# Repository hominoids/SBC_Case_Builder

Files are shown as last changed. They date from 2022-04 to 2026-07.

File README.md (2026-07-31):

# SBC Case Builder

## Introduction

This project is about autonomous SBC case creation. It utilizes the SBC Model Framework project to automatically generate cases based on the data for any of the current devices contained within the framework. This allows legacy, current and future SBC to have multiple cases available on day one of their inclusion in the framework. There are multiple base case designs available (shell, panel, stacked, tray, tray-sides, round, hex, snap, fitted, folded-paper and standard motherboard adapters) and each allows for customization within the design.

All case openings are created automatically based on SBC data and the dimensions of any case design can be expanded in any axis allowing for the creation of larger cases. If you reposition the SBC in a case, you will see I/O openings created or removed appropriately based on their proximity to the case geometry. These cases might be useful for prototypes or other in house uses to quickly and easily create standard, specialized and custom SBC cases thru different case designs, customization and accessories.

License: GPLv3.

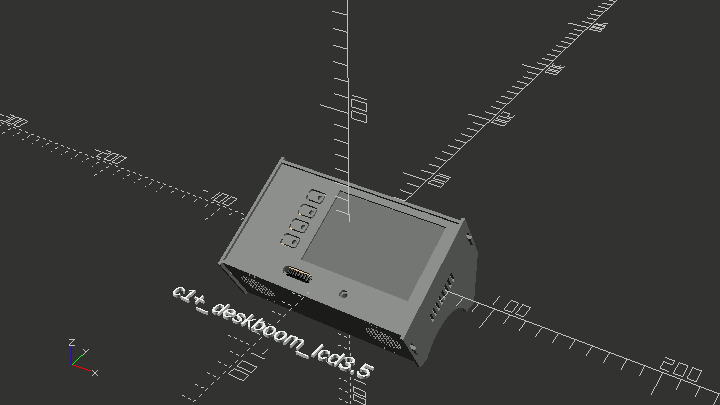
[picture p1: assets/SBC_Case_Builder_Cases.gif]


### Install
```
  git clone https://github.com/hominoids/SBC_Case_Builder.git
  cd SBC_Case_Builder
  git submodule init
  git submodule update

```
NOTE: The submodule *SBC Model Framework* needs to be updated anytime SBC Case Builder is updated.

## SBC Case Builder Features:
-  Autonomous Multi-SBC, Multi-Case Parametric Generation
-  Autonomous SBC and Accessory Model I/O Openings
-  Autonomous Case Standoffs with Variable Height
-  Extended Standoff SBC collision detection
-  Accessory Customization Framework
-  Accessory Multi-Associative Parametric Positioning
   - Absolute Location
   - Case Associations
   - SBC Associations
   - SBC_X,Y - Case_Z Association
-  Graphical User Interface
-  SBC Meta Data Access
-  Individual Standoff Parameter Control
-  Dynamic Heatsink Fan Size, Vent and Mask Openings 
-  Top and Bottom Case Cover Patterns
-  Parametric Bottom Access Panel

### Base Case Designs:
- Shell - complete
- Panel - complete
- Stacked - complete
- Tray - complete
- Tray-Sides - complete
- Tray-Vu5 - complete
- Tray-Vu7 - complete
- Round - complete
- Hex - complete
- Snap - complete
- Fitted - complete
- Paper, Folded - complete
- Standard MB SBC Adapters & io plates - completed
	+ SSI-EEB, SSI-CEB, ATX, Micro-ATX, DTX, Flex-ATX, Mini-DTX, EBX, Mini-ITX, Mini-ITX Thin, Mini-STX, Mini-STX Thin
- Standard MB Cases - complete
	+ SSI-EEB, SSI-CEB, ATX, Micro-ATX, DTX, Flex-ATX, Mini-DTX, EBX, Mini-ITX, Mini-ITX Thin, Mini-STX, Mini-STX Thin, Nano-ITX, NUC, Pico-ITX
- NAS, panel_nas - complete
- Rack, 1U and 2U - complete
- Stacked Levels
- Sliding
- Cylinder
- Free Form
- Sheet Metal, Folded
- CNC Cases

All case data is stored in the json file sbc_case_builder.json with the accessory data stored in a separate file structure in sbc_case_builder_accessories.cfg.  An accessory group name for a given case is stored as part of the case data in the json file.  This allows for the reuse or sharing of an accessory set by different cases and can be used to manage groups of accessories.

Variable height automated SBC standoffs, which can be individually adjusted, are also implemented to integrate add-on PCB, hats, heatsinks or other accessories that share SBC standoffs for mounting.

## Graphical User Interface
The GUI has multiple tabs that control what model and case is displayed, how it is presented, its adjustments, options and associated accessories. There are separate tabs in the GUI for *Folded Case Adjustments*, *Standard Motherboard Case Adjustments* and *3D Case Adjustments*.  The first two have unique settings that only apply to the respective case designs.  3D case adjustments affect all others case designs and some entries can also affect Folded and Standard Motherboard cases as well. There are three groups of two tabs each associated with SBC, Extended Case and Multi-PCB standoffs.



### View Tab
The View Tab allows the selection of various viewing modes and the selection of the device model for which a case is being generated.  The *view* pickbox allows the respective case to be displayed as a 3D model, platter for 3D printing and as an individual case part, which can be selected using the *individual part* pickbox.  The *section part* checkbox sections the selected part for dxf or other 2D export. The *sbc model* pickbox selects the device (SBC, MCU, Motherboard, etc).  The *sbc off* and *sbc information* are self explanatory.  The *sbc highlight* shows the subtractive openings that are being automatically created by SBC Model Framework while the *accessory highlight* shows the subtractive openings being generated by entries in the file sbc_case_builder_accessories.cfg.  The later is useful when trying to visually place a subtractive accessory.

### Folded Case Adjustments Tab
This tab exclusively deals with folded cases.  At this time the bend allowance equations are not complete and limits its use to paper and other thin materials with a low bend radius.  Once folded metal cases are implemented the bend allowance equations will be complete and allow for any bendable material of any given bend radius.  With that said, these adjustments are used for the paper_full-top and paper_split-top case designs and the *material thickness* and *bend Allowance* adjustments still need to be set appropriately for proper use.  The *bottom clearance* adjustment allows additional bottom height adjustment for those wishing to use user provided standoffs on the bottom of the device for better stability.  The *flat blank section* checkbox generates a flat blank based on the aforementioned settings.  Once it has been generated the model must be rendered(F6) to produce a 2D blank that can then be exported as a DXF or SVG file for printing or fed to a CNC cutter.

### Standard Motherboard Case Adjustments Tab
Both standard motherboard adapters and cases can be generated with SBC Case Builder and this tab controls the specific settings. Since it is not possible to know the motherboard thickness it is set to 2mm and the *standard motherboard thickness* setting is used to add or subtract thickness for an accurate representation of the user provided PCB.  The *rear io shield* setting enables the generation of an io shield for adapters and standard motherboard cases.  The setting *adapter sbc rotation* rotates the sbc for adapters.  Most of the adjustments in the *3D Case Adjustments* tab also work for motherboard adapters which allows for the SBC or other device to be repositioned on the adapter while providing the full use of the accessory subsystem. Any accessory entries in the sbc_case_builder_accessories.cfg file should reference the bottom face. The *bottom cover pattern* in the *Fan and Vent Openings* tab and the *SBC Bottom Standoff* tabs also apply to motherboard adapters.  There are predefined example cases and adapters available in the GUI for further reference.

### Rack Mount Case Adjustments Tab
Both 1U and 2U, 10" and 19", rack cases are configured in this tab.  The first entry *rack width* selects if 10" or 19" rack cases are being created.  The *rack size* sets whether 1U or 2U.  There is a 2mm wall in front of every removable bay. *removable bay height* allows the tray height to be reduced to form an opening which allows for tray removal and venting when installed with other rack cases above.  The remaining tab is divided into six groups of settings each representing a virtual bay.  Each bay group specifies the SBC thru the pickbox *Rack Bay1* respectively. With *rack bay1 xyz loc* and *rack bay1 rotation determining the position and z-axis rotation.  The type of bay is set in the *rack bay1 face* pickbox followed by two checkboxes for the internal dividing wall, rear fan and a bay conduit selection pickbox. 

### 3D Case Adjustments Tab
The *3D Case Adjustments* tab makes up the bulk of the possible case adjustments for 3D printed cases.  Most of the entries in this tab are self explanatory.  The *pcb loc* adjustments allow the selected device model to be moved in the case design, the *case offset* adjustments increase the selected case design dimensions. The *wallthick*, *floorthick* and *sidethick* adjust their respective areas.  Do note that the *floorthick* adjustment also determines the ceiling thickness for all case designs and the *sidethick* only affects the tray_sides, tray_vu5, tray_vu7 case designs. The *gap* entry is the distance between the device PCB and the sidewall of the case design.  The *tol* adjustment, located at the bottom of the tab, is a  tolerance fitment adjustment for the snap, fitted, round and hex case design tops.  Adjust accordingly if the tops are too tight or loose.

### Fan and Vent Openings Tab
This tab handles the fan and cooling options for case designs.  The *top cover pattern*, *bottom cover pattern* and *front cover pattern* contain several options for the creation of vent patterns that cover the complete panel, including a solid covering.  The *cooling* pickbox selects fan and vent openings exclusively for the heatsink associated with the device in SBC Model Framework.
```
disable - turns off the heatsink model and mask
off - heatsink model is off, mask is on and default will be used
default - heatsink model is on and uses the mask setting in ./SBC_Model_Framework/sbc_models.cfg
none - heatsink model is on and mask is off.
fan and vent pattern selections - open, fan_open, fan_1, fan_2, fan_hex, vent, vent_hex_5mm, vent_hex_8mm
custom - uses the file ./SBC_Model_Framework/customfan.dxf
```
The *fan size* allows the selection of different fan size masks over the default size selected by 0.  The rear fan entries are for the *panel_nas* case design and allow for the same types of fan adjustments as the heatsink.  There is also the choice of one or two rear fans as well as additional adjustments for the position and spacing of them.

### Bottom Access Panel Tab
This tab allows the creation of a bottom access panel and its entries are self explanatory.  Additional access panels can be implemented using the accessory subsystem.

### Options and Accessories
The entrys in this tab allow for the enablement and selection of different options and accessories. It includes case indents, GPIO, and UART openings based on their type identifier in SBC_Model_Framework.  It also contains hard drive options for the panel_nas case.

#### GPIO Selections
```
disable - turns off the GPIO model and mask
off - GPIO model is off, mask is on and default will be used
default - GPIO model is on and uses the mask setting stored in ./SBC_Model_Framework/sbc_models.cfg
none - GPIO model is on and mask is off
mask opening selections - open, block, knockout, vent
```

#### UART Selections
```
default - UART model is on and uses the mask setting stored in ./SBC_Model_Framework/sbc_models.cfg
none - UART model is on and mask is off
mask opening selections - open, knockout
```

The *indent* checkbox enables indents for a select group of components defined in SBC Model Framework.  The currently support components are - video-hmdi_a, video-hdmi_micro, video-hdmi_mini, power-pwr5.5_7.5x11.5, power-pwr2.5_5x7.5, usb2-micro, usbc-single_horizontal, audio-jack_3.5. The *accessory name* pickbox uses the unique accessory group name to associate a given accessory set with a case design.  Entries are stored in the file sbc_case_builder_accessories.cfg which is covered in detail with the Accessory Subsystem in this document.  The remaining two entries select the color and proportional font used with the *sbc information* display when enabled in the *View* tab.

#### NAS HD Options
The *nas sbc location* pickbox allows the positioning of the SBC at the top or bottom of a NAS case.  *hd bays* sets the number of drive bays, *hd reverse* checkbox rotates the drives 180 degrees while *hd center* centers the drives in the x-axis.  The next entry, *hd space* determines the spacing between drives and *hd y position* and *hd z position* sets the respective axis locations.

#### Accessory Group Name 
The *accessory name* allows the selection of an accessory group to be associated with the current case.  These groups are located in the file sbc_case_builder_accessories.cfg and provide a means to add or subtract geometry, models and add items to the print platter.  See the *Accessory Subsystem* area below for further details and use.

### Standoff Tabs
There are 3 types of standoffs available in the user interface, SBC Standoffs, Extended Case Standoffs and Multi-PCB Standoffs.  The SBC standoffs control adjustments for the SBC or pcbid 0 as defined by the entry in SBC Model Framework file ./SBC_Model_Framework/sbc_models.cfg.  The Extended Case Standoffs control case corner standoffs when the case exceeds the SBC size by the *SBC Standoff Support Size*.  The Multi-PCB standoffs are used for additional PCB in multi-PCB configurations as defined in ./SBC_Model_Framework/sbc_models.cfg e.g. pcbid 1, pcbid 2, etc.  All three standoff types have similar controls made up of a global tab and individual Settings tab in the GUI.

The main difference between the different standoff groups are that the SBC Standoffs are located by the SBC PCB holes, the Extended Case Standoffs are located in the four corners of a case design that exceeds dimensions of the intended device by the size of the *SBC Case Standoff Support Size* and the Multiple PCB Standoffs are located by the holes of the additional PCBs that makeup a given device.  The entries for the standoffs are basically the same so only the top SBC standoffs will be specifically covered.

#### Standoff Global Settings
The tab *SBC Top Standoff Global Settings* affects all the respective standoffs and starts with three checkboxes. The first, *sbc top standoffs*, enables or disable all the top standoffs.  The second, *top standoff reverse*, rotates the standoff 180 degrees and is used primarily for standoffs associated with the top face of all case designs.  The last, *top sidewall support*, enables or disables the side wall support for all SBC top standoffs.  The first pickbox in the tab is called *top standoff size* and determines the overall size of the SBC top standoffs.  It is made up of named sizes that are predefined and a custom entry that is defined by the remaining entries in the tab.  The predefined named top standoff sizes are further divided into entries where only the hole size is different e.g. m3, m3+, m3_tap.  The m3 entry has a 3mm hole, the m3+ entry's hole is approximately 15% larger for clearance and the m3_tap entry's hole size is the tap drill size.  When a named size is selected the *top standoff diameter* and *top standoff hole size* entries have no effect but the remaining entries do apply - it is the *custom* entry that allows full control of all parameters.

The *top standoff support size* and *top standoff support height* is what allows recessed *top standoff type* entries to work on thin wall 
floors and ceilings by providing the extra size and depth for the given recess.  This applies to the *top standoff type* selections countersunk, recessed and nutholder.  The recessed entry also allows for deep recessed screws by recessing the standoff for the full height of the *standoff support height* less 2mm.  This can be deployed for tall cases in order to use shorter fasteners and is the most practical way to handle this scenario.  The *top standoff insert* checkbox enables the use of inserts of the size defined by *top standoff insert dia* and *top Standoff insert height* at the opposite end of the standoff.  This allows case halves to be fastened together thru the bottom of the case and is another alternative to dealing with tall case designs.

#### Standoff Individual Settings
The *SBC Top Individual Settings* entries control variable on a per standoff basis.  There are four entry groups each controlling a standoff's enablement, height adjustment and sidewall support location.  This is useful when dealing with hats or other accessories that share SBC PCB holes for mounting.  Likewise, being able to change the direction of the sidewall support allows for a wider choice to strengthen and tie the standoff to the case walls or completely disable them if SBC components interfere.  The length of the sidewall support is equal to the respective *standoff support size* for SBC, Extended Case and  Multi-PCB standoffs.

As indicated previously, The SBC Standoffs, Extended Case Standoffs and Multi-PCB Standoffs all work the same with the following exceptions. The *standoff support size* is also used to determine the corner proximity for the Extended Case standoffs.  The Multiple PCB Standoffs present a unique challenge due to their nature.  There will be situations with multiple PCB devices when not all the standoffs created by the PCB holes will be needed.  Imagine two PCBs next to each other that would normally create eight standoffs.  In many scenarios only outer standoffs are needed for both the top and bottom and the bottom inner standoffs for PCB support.  In order to handle this and many other situations without creating a complex and burdensome GUI, an entry for the creation of the PCB hole can be used to disable the top, bottom or both standoffs.  This is accomplished within the SBC Model Framework pcbhole class.  The person creating the sbc_models.cfg entry can determine and override the creation of these standoffs in SBC Case Builder.  See the SBC Model Framework pcbhole class for further details.

## Notes, Tips and Things to Check
SBC Case Builder by default makes the smallest symmetrical case possible for the SBC selected and default parameters.  Most times this works well but some SBC need asymmetrical spacing, extra gap or additional standoff clearance and may require tweaking to obtain the best results. If there is a saved case for an SBC it is best to start your new case with it, or at least become familiar with any special changes made, since they might apply to a new case.

### Standoff Selection, Inserts and Clearance
Standoff selection and implementation is the most effected part of customizing a case.  Some SBC can use a M3 screw and others only use a M2.5 or M2 screw.  Finding the best fastening approach can be influenced too by the hardware one has on-hand or personal preference.  If using inserts, a custom standoff size must be used since the standard standoff sizes are to small for their respective insert diameter.  For tall cases, fastener length can be reduced by using a deep recessed standoff, the depth set by the *standoff support height* after selecting a *recessed* type under the appropriate global Tab . Watch for standoff clearance issues around PCB holes and neighboring components.  Some SBC designs crowd the area and can interfere with standoff diameter sizes, especially when inserts are being used. This is one factor that may determine whether to fasten the case from the top or bottom.

### Component Overhang and Case Gap
As previously stated, symmetrical cases use the same gap spacing for all sides. This has worked well but more recently many SBC use significantly different component overhangs and could benefit from an asymmetrical case. By increasing the case size by the needed amount in an axis and possibly shifting the PCB the same amount or not, an asymmetrical case gap can be created to accommodate SBC with significantly differing overhangs.  This is especially import if opposing sides of an SBC use component overhangs greater then 2mm which may also influence the assembly of the case.

### Geometry Placement, Alignment and Interference Checking
When using subtractive geometry accessories, turning on *accessory highlight* under the *View Tab* will help in placing and aligning objects.
Use case sections to view inside a closed case by setting to -1 the *move side* slider under the *View Tab*.  Platter view can be useful to view changes and as a final check if everything is configured as required prior to STL export. 

### Using Accessories Dynamically
Having SBC Case Builder running while editing the sbc_case_builder_accessories.cfg file using a separate text editor will aide in visual accessory manipulation and placement.  OpenSCAD will automatically regenerate the model preview when the accessory configuration files is saved.  
 
## Accessory Subsystem
Case accessories entries are kept in the file sbc_case_builder_accessories.cfg. Newly created accessory group names also need to be added to the variable accessory_name in sbc_models.scad on or around line #128 in order for them to appear in the GUI pickbox.  Any new accessory group names must be added to the pickbox entry or they will not be present in the GUI. This can be done manually or the helper script get_customizer_values.scad can be used to generate a complete accessory names list for copy and paste from the console.

### Accessory Schema
Each accessory group consists of a unique name followed by an unlimited number of accessory entries each containing 11 variables.
```
schema:

"accessory_name",
"class","type",loc_x,loc_y,loc_z,face,rotation[x,y,z],parametrics[association,x,y,z],size[],data[],mask[]
```

### Accessories Entries
There are 6 classes, “add1”,“sub”,”suball”,”add2”,”model”,”platter” and all use the same command format for various “type”.
```
"class","type",loc_x,loc_y,loc_z,face,rotation[x,y,z],parametrics[association,x,y,z],size[],data[],mask[]
```
e.g.
```
                                              p
                                              a
                                              r
                                     r        a                                               s
                                     o        m                                               e
                                     t        e                           s s s             l t    m
       c          l  l  l            a        t                           i i i             e      s
       l      t   o  o  o      f     t        r                           z z z   d     m   n b    t
       a      y   c  c  c      a     i        i                           e e e   a     a   g a    y
       s      p                c     o        c                                   t     s   t c    l
       s,     e,  x, y, z,     e,    n,       s,                          x,y,z,  a,    k   h k    e

     "sub","fan",10,10,24.5,"top",[0,0,0],["sbc-case_z",true,true,true],[40,0,6],[0],[true,10,2,"default"],
```
  
Every type, regardless of its class, uses a basic set of variables
`(loc_x,loc_y,loc_z,”face”,rotation[],parametrics[])`
but each type doesn’t necessarily use all available data fields
`(size[],data[])`

Multi-associative parametric positioning of accessories is implemented and allows each accessory to enable or disable parametric movement of the accessory for each axis.  The XY and Z axis can be associated with the case offset (size), SBC positioning, multi-associated axis's or absolute positioning.  For instance, a SBC fan opening needs to follow the SBC in the X and Y axis but the case Z axis for the correct height.  The parametric array specifies the axis to enable for associated parametric positioning. An accessory can be associated with the sbc position("sbc"), case offset("case"),multi-associated which use sbc xy position and case z offset("sbc-case_z") or use absolute values if all axis's are false.  In the accessory example above, the 8th parameter `["sbc-case_z",true,true,true]` means all axis's are enabled for multi-associative movement with the X and Y accessory axis following the SBC X and Y axis and the accessory Z axis following the case Z axis.

### classes: add1, sub, suball, add2, model, platter

Class *add1* and *add2* are used to add geometry to the case. The difference is when the addition occurs. *add1* happens at the beginning when the core case geometry is created before any subtractions and *add2* happens at the end after all subtractions have occurred. *suball* is used to affect all faces of a case, not just a single face. The “face” is the case piece that will be effected by the addition or subtraction. The *model* class is for placing supporting accessories in the model view. e.g. hard drives, fans. The *platter* class is for adding supporting accessories, that are not part of the core case geometry, to the print platter for printing e.g. a fan cover or access panel cover.

**additive type:**

art, access_panel, batt_holder, button, button_assembly, fan_cover, feet, grommet, hd_holder, hk_boom_grill, hk_boom_speaker_holder, hk_boom_vring, hk_h3_port_extender_holder, hk_hc4_oled_holder, hk_uart_holder, hk_uart_strap, keyhole, nut_holder, panel_clamp, pcb_holder, rectangle, round, slot, sphere, standoff, text, vent_panel_hex, uart_holder, hc4_oled_holder, button, pcb_holder

**subtractive type:**

art, fan_mask, hd_holes, knockout, rectangle, round, slot, sphere, text, vent, vent_hex

**model type:**

access_cover, adafruit_lcd, dsub, fan, hd25, hd35, hk_boom, hk_boom_speaker, hk_h3_port_extender, hk_hc4_oled, hk35_lcd, hk_m1s_ups, hk_net_card, hk_pwr_button, hk_speaker, hk_uart, hk_vu7c, hk_vu8m, hk_vu8s, hk_wb2, hk_xu4_shifter_shield, pillar, rpi_m2hat, stl_model

**platter type:**

access_cover, button_assembly, fan_cover, feet, grommet, hk_boom_vring, hk_h3_port_extender_holder, hk_uart_strap, vent_panel_hex

## Accessory Reference Manual

### Add1 and Add2 class “types”

### access_cover

```
    CLASSES: add1, add2, platter
DESCRIPTION: creates bottom access cover for access panels.
       MASK: no
      USAGE: "class", "access_cover", loc_x, loc_y, loc_z, face, rotation[], parametric[], size[], data[], mask[]

              class = "add1", "add2", "platter"
               type = "access_cover"
              loc_x = x location placement
              loc_y = y location placement
              loc_z = z location placement
               face = "top", "bottom", "right", "left", "front", "rear"
         rotation[] = object rotation
       parametric[] = "case", "sbc", "sbc-case_z"
            size[0] = x dimension
            size[1] = y dimension
            size[2] = floor thickness
            data[0] = "portrait", "landscape"
            mask[0] = false, not used
            mask[1] = length
            mask[2] = set back
            mask[3] = mstyle "default"
```

### access_panel

```
    CLASSES: add2
DESCRIPTION: creates bottom access panels.
       MASK: yes
      USAGE: "class", "access_panel", loc_x, loc_y, loc_z, face, rotation[], parametric[], size[], data[], mask[]

              class = "add2"
               type = "access_panel"
              loc_x = x location placement
              loc_y = y location placement
              loc_z = z location placement
               face = "top", "bottom", "right", "left", "front", "rear"
         rotation[] = object rotation
       parametric[] = "case", "sbc", "sbc-case_z"
            size[0] = x dimension
            size[1] = y dimension
            size[2] = floor thickness
            data[0] = "portrait", "landscape"
            mask[0] = true
            mask[1] = length
            mask[2] = set back
            mask[3] = mstyle "default"
```

### art

```
    CLASSES: add1, add2, sub, suball
DESCRIPTION: creates or subtracts art work geometry in dxf or svg format.
       MASK: no
      USAGE: "class", "art", loc_x, loc_y, loc_z, face, rotation[], parametric[], size[], data[], mask[]

              class = "add1", "add2", "sub", "suball"
               type = "art"
              loc_x = x location placement
              loc_y = y location placement
              loc_z = z location placement
               face = "top", "bottom", "right", "left", "front", "rear"
         rotation[] = object rotation
       parametric[] = "case", "sbc", "sbc-case_z"
             size[] = not used
            data[0] = scale
            data[1] = height
            data[2] = "file"
            mask[0] = false, not used
            mask[1] = length
            mask[2] = set back
            mask[3] = mstyle "default"
```

### battery_holder

```
    CLASSES: add1, add2
DESCRIPTION: creates battery holder for coin cr2032 batteries.
       MASK: no
      USAGE: "class", "battery_holder", loc_x, loc_y, loc_z, face, rotation[], parametric[], size[], data[], mask[]

              class = "add1", "add2"
               type = "battery_holder"
              loc_x = x location placement
              loc_y = y location placement
              loc_z = z location placement
               face = "top", "bottom", "right", "left", "front", "rear"
         rotation[] = object rotation
       parametric[] = "case", "sbc", "sbc-case_z"
             size[] = not used
            data[0] = tolerance adjustment
            mask[0] = false, not used
            mask[1] = length
            mask[2] = set back
            mask[3] = mstyle "default"
```

### button

```
    CLASSES: add2
DESCRIPTION: adds various button styles.
       MASK: yes
      USAGE: "add2", "button", loc_x, loc_y, loc_z, face, rotation[], parametric[], size[], data[], mask[]

              class = "add2"
               type = "button"
              loc_x = x location placement
              loc_y = y location placement
              loc_z = z location placement
               face = "top", "bottom", "right", "left", "front", "rear"
         rotation[] = object rotation
       parametric[] = "case", "sbc", "sbc-case_z"
            size[0] = diameter of button body for recess style
            size[1] = not used
            size[2] = height above button for recess style
            data[0] = "recess", "cutout"
            data[1] = radius for cutout style
            data[2] = button post size for cutout style
            mask[0] = true
            mask[1] = length
            mask[2] = set back
            mask[3] = mstyle "default"
```

### button_assembly

```
    CLASSES: add2, platter
DESCRIPTION: adds button assembly for recess button style.
       MASK: yes
      USAGE: "add2", "button_assembly", loc_x, loc_y, loc_z, face, rotation[], parametric[], size[], data[], mask[]

              class = "add2"
               type = "button_assembly"
              loc_x = x location placement
              loc_y = y location placement
              loc_z = z location placement
               face = "top", "bottom", "right", "left", "front", "rear"
         rotation[] = object rotation
       parametric[] = "case", "sbc", "sbc-case_z"
            size[0] = diameter of button body for recess style
            size[1] = not used
            size[2] = height above button for recess style
            data[0] = "recess"
            mask[0] = true
            mask[1] = length
            mask[2] = set back
            mask[3] = mstyle "default"
```

### fan_cover

```
    CLASSES: add1, add2, platter
DESCRIPTION: creates fan cover for fan openings.
       MASK: no
      USAGE: "class", "fan_cover", loc_x, loc_y, loc_z, face, rotation[], parametric[], size[], data[], mask[]

              class = "add1", "add2", "platter"
               type = "fan_cover"
              loc_x = x location placement
              loc_y = y location placement
              loc_z = z location placement
               face = "top", "bottom", "right", "left", "front", "rear"
         rotation[] = object rotation
       parametric[] = "case", "sbc", "sbc-case_z"
            size[0] = fan size
            size[1] = not used
            size[2] = cover thickness
            data[0] = "fan_open", "fan_1", "fan_2", "fan_hex"
            mask[0] = false, not used
            mask[1] = length
            mask[2] = set back
            mask[3] = mstyle "default"
```

### feet

```
    CLASSES: add1, add2, platter
DESCRIPTION: creates case feet.
       MASK: no
      USAGE: "class", "feet", loc_x, loc_y, loc_z, face, rotation[], parametric[], size[], data[], mask[]

              class = "add1", "add2", "platter"
               type = "feet"
              loc_x = x location placement
              loc_y = y location placement
              loc_z = z location placement
               face = "top", "bottom", "right", "left", "front", "rear"
         rotation[] = object rotation
       parametric[] = "case", "sbc", "sbc-case_z"
            size[0] = feet diameter
            size[1] = not used
            size[2] = feet height
             data[] = not used
            mask[0] = false, not used
            mask[1] = length
            mask[2] = set back
            mask[3] = mstyle "default"
```

### grommet

```
    CLASSES: add1, add2, platter
DESCRIPTION: creates different groumet styles.
       MASK: yes
      USAGE: "class", "grommet", loc_x, loc_y, loc_z, face, rotation[], parametric[], size[], data[], mask[]

              class = "add1", "add2", "platter"
               type = "grommet"
              loc_x = x location placement
              loc_y = y location placement
              loc_z = z location placement
               face = "top", "bottom", "right", "left", "front", "rear"
         rotation[] = object rotation
       parametric[] = "case", "sbc", "sbc-case_z"
            size[0] = od outside diameter of grommet body
            size[1] = id inside hole diameter of grommet body
            size[2] = wall thickness of installation
            data[0] = "top","bottom","front","rear","left","right"
            data[1] = "sleeve"
            data[2] = assembled true, false 
            mask[0] = true enables component mask
            mask[1] = mask length
            mask[2] = mask setback
            mask[3] = mstyle "default"
```

### hd_holder

```
    CLASSES: add1, add2
DESCRIPTION: creates a horizontal double stacked holder for 2.5 and 3.5 drives.
       MASK: no
      USAGE: "class", "hd_holder", loc_x, loc_y, loc_z, face, rotation[], parametric[], size[], data[], mask[]

              class = "add1", "add2"
               type = "hd_holder"
              loc_x = x location placement
              loc_y = y location placement
              loc_z = z location placement
               face = "top", "bottom", "right", "left", "front", "rear"
         rotation[] = object rotation
       parametric[] = "case", "sbc", "sbc-case_z"
             size[] = not used
            data[0] = 2.5 or 3.5
            data[1] = ”portrait”, “landscape”
            mask[0] = false, not used
            mask[1] = length
            mask[2] = set back
            mask[3] = mstyle "default"
```

### hd_vertleft_holder

```
    CLASSES: add1, add2
DESCRIPTION: creates a vertical left facing holder for 2.5 and 3.5 drives.
       MASK: no
      USAGE: "class", "hd_vertleft_holder", loc_x, loc_y, loc_z, face, rotation[], parametric[], size[], data[], mask[]

              class = "add1", "add2"
               type = "hd_vertleft_holder"
              loc_x = x location placement
              loc_y = y location placement
              loc_z = z location placement
               face = "top", "bottom", "right", "left", "front", "rear"
         rotation[] = object rotation
       parametric[] = "case", "sbc", "sbc-case_z"
             size[] = not used
            data[0] = 2.5 or 3.5
            data[1] = ”portrait”, “landscape”
            mask[0] = false, not used
            mask[1] = length
            mask[2] = set back
            mask[3] = mstyle "default"
```

### hd_vertright_holder

```
    CLASSES: add1, add2
DESCRIPTION: creates a vertical right facing holder for 2.5 and 3.5 drives.
       MASK: no
      USAGE: "class", "hd_vertright_holder", loc_x, loc_y, loc_z, face, rotation[], parametric[], size[], data[], mask[]

              class = "add1", "add2"
               type = "hd_vertright_holder"
              loc_x = x location placement
              loc_y = y location placement
              loc_z = z location placement
               face = "top", "bottom", "right", "left", "front", "rear"
         rotation[] = object rotation
       parametric[] = "case", "sbc", "sbc-case_z"
             size[] = not used
            data[0] = 2.5 or 3.5
            data[1] = ”portrait”, “landscape”
            mask[0] = false, not used
            mask[1] = length
            mask[2] = set back
            mask[3] = mstyle "default"
```

### hk_boom_grill

```
    CLASSES: add2
DESCRIPTION: creates hk boom bonnet grill covers.
       MASK: yes
      USAGE: "class", "hk_boom_grill", loc_x, loc_y, loc_z, face, rotation[], parametric[], size[], data[], mask[]

              class = "add2"
               type = "hk_boom_grill"
              loc_x = x location placement
              loc_y = y location placement
              loc_z = z location placement
               face = "top", "bottom", "right", "left", "front", "rear"
         rotation[] = object rotation
       parametric[] = "case", "sbc", "sbc-case_z"
            size[0] = not used
            size[1] = not used
            size[2] = wall thickness
            data[0] = "flat", "dome", "frame"
            mask[0] = true
            mask[1] = length
            mask[2] = set back
            mask[3] = mstyle "default"
```

### hk_boom_speaker_holder

```
    CLASSES: add2, platter
DESCRIPTION: creates hk boom bonnet speaker clamp and friction style holder.
       MASK: no
      USAGE: "class", "hk_boom_speaker_holder", loc_x, loc_y, loc_z, face, rotation[], parametric[], size[], data[], mask[]

              class = "add2"
               type = "hk_boom_speaker_holder"
              loc_x = x location placement
              loc_y = y location placement
              loc_z = z location placement
               face = "top", "bottom", "right", "left", "front", "rear"
         rotation[] = object rotation
       parametric[] = "case", "sbc", "sbc-case_z"
             size[] = not used
            data[0] = "friction", "clamp"
            data[1] = tolerance adjustment
            mask[0] = false
            mask[1] = length
            mask[2] = set back
            mask[3] = mstyle "default"
```

### hk_boom_vring

```
    CLASSES: add1, add2, platter
DESCRIPTION: creates hk stereo boom bonnet volume wheel extention.
       MASK: no
      USAGE: "class", "hk_boom_vring", loc_x, loc_y, loc_z, face, rotation[], parametric[], size[], data[], mask[]

              class = "add1", "add2", "platter"
               type = "hk_boom_vring"
              loc_x = x location placement
              loc_y = y location placement
              loc_z = z location placement
               face = "top", "bottom", "right", "left", "front", "rear"
         rotation[] = object rotation
       parametric[] = "case", "sbc", "sbc-case_z"
             size[] = not used
            data[0] = tolerance adjustment
            mask[0] = false
            mask[1] = length
            mask[2] = set back
            mask[3] = mstyle "default"
```

### hk_h3_port_extender_holder

```
    CLASSES: add1, add2, platter
DESCRIPTION: creates odroid-h3 port extender holder parts.
       MASK: no
      USAGE: "class", "hk_h3_port_extender_holder", loc_x, loc_y, loc_z, face, rotation[], parametric[], size[], data[], mask[]

              class = "add1", "add2", "platter"
               type = "hk_h3_port_extender_holder"
              loc_x = x location placement
              loc_y = y location placement
              loc_z = z location placement
               face = "top", "bottom", "right", "left", "front", "rear"
         rotation[] = object rotation
       parametric[] = "case", "sbc", "sbc-case_z"
             size[] = not used
            data[0] = distance from mount face
            data[1] = "top", "bottom", "both"
            mask[0] = false
            mask[1] = length
            mask[2] = set back
            mask[3] = mstyle "default"
```

### hk_hc4_oled_holder

```
    CLASSES: add2
DESCRIPTION: creates a holder for the hk odroid-hc4 oled display.
       MASK: yes
      USAGE: "class", "hk_hc4_oled_holder", loc_x, loc_y, loc_z, face, rotation[], parametric[], size[], data[], mask[]

              class = "add2"
               type = "hk_hc4_oled_holder"
              loc_x = x location placement
              loc_y = y location placement
              loc_z = z location placement
               face = "top", "bottom", "right", "left", "front", "rear"
         rotation[] = object rotation
       parametric[] = "case", "sbc", "sbc-case_z"
            size[0] = not used
            size[1] = not used
            size[2] = floor thickness
             data[] = not used
            mask[0] = true
            mask[1] = length
            mask[2] = set back
            mask[3] = mstyle "default"
```

### hk_uart_holder

```
    CLASSES: add2
DESCRIPTION: creates a holder for the hk micro-usb uart.
       MASK: yes
      USAGE: "class", "hk_uart_holder", loc_x, loc_y, loc_z, face, rotation[], parametric[], size[], data[], mask[]

              class = "add2"
               type = "hk_uart_holder"
              loc_x = x location placement
              loc_y = y location placement
              loc_z = z location placement
               face = "top", "bottom", "right", "left", "front", "rear"
         rotation[] = object rotation
       parametric[] = "case", "sbc", "sbc-case_z"
             size[] = not used
             data[] = not used
            mask[0] = true
            mask[1] = length
            mask[2] = set back
            mask[3] = mstyle "default"
```

### hk_uart_strap

```
    CLASSES: add2, platter
DESCRIPTION: creates a strap for the hk micro-usb uart holder.
       MASK: no
      USAGE: "class", "hk_uart_holder", loc_x, loc_y, loc_z, face, rotation[], parametric[], size[], data[], mask[]

              class = "add2"
               type = "hk_uart_holder"
              loc_x = x location placement
              loc_y = y location placement
              loc_z = z location placement
               face = "top", "bottom", "right", "left", "front", "rear"
         rotation[] = object rotation
       parametric[] = "case", "sbc", "sbc-case_z"
             size[] = not used
             data[] = not used
            mask[0] = false
            mask[1] = length
            mask[2] = set back
            mask[3] = mstyle "default"
```

### keyhole

```
    CLASSES: add1, add2
DESCRIPTION: creates enclosed keyhole.
       MASK: yes
      USAGE: "class", "keyhole", loc_x, loc_y, loc_z, face, rotation[], parametric[], size[], data[], mask[]

              class = "add1", "add2"
               type = "keyhole"
              loc_x = x location placement
              loc_y = y location placement
              loc_z = z location placement
               face = "top", "bottom", "right", "left", "front", "rear"
         rotation[] = object rotation
       parametric[] = "case", "sbc", "sbc-case_z"
             size[] = not used
            data[0] = [head_dia, slot_width, slot_length, floor_thick]
            mask[0] = true
            mask[1] = length
            mask[2] = set back
            mask[3] = mstyle "default"
```

### nut_holder

```
    CLASSES: add1, add2
DESCRIPTION: creates nut holder of various styles.
       MASK: no
      USAGE: "class", "nut_holder", loc_x, loc_y, loc_z, face, rotation[], parametric[], size[], data[], mask[]

              class = "add1", "add2"
               type = "nut_holder"
              loc_x = x location placement
              loc_y = y location placement
              loc_z = z location placement
               face = "top", "bottom", "right", "left", "front", "rear"
         rotation[] = object rotation
       parametric[] = "case", "sbc", "sbc-case_z"
            size[0] = top diameter or x size in mm
            size[1] = bottom diameter or y size in mm
            size[2] = holder height in mm
            data[0] = "m2", "m2.5", "m3", "m4", "m3-insert"
            data[1] = "default", "sloped", "trap"
            mask[0] = true
            mask[1] = length
            mask[2] = set back
            mask[3] = mstyle "default"
```

### panel_clamp

```
    CLASSES: add1, add2
DESCRIPTION: creates clamps to join two panels.
       MASK: yes
      USAGE: "class", "panel_clamp", loc_x, loc_y, loc_z, face, rotation[], parametric[], size[], data[], mask[]

              class = "add1", "add2"
               type = "panel_clamp"
              loc_x = x location placement
              loc_y = y location placement
              loc_z = z location placement
               face = "top", "bottom", "right", "left", "front", "rear"
         rotation[] = object rotation
       parametric[] = "case", "sbc", "sbc-case_z"
            size[0] = top diameter or x size in mm
            size[1] = bottom diameter or y size in mm
            size[2] = clamp height in mm
            data[0] = orientation "top","bottom","rear","front","left","right"
            data[1] = "sloped"
            data[2] = "m2", "m2.5", "m3", "m4"
            mask[0] = false
            mask[1] = length
            mask[2] = set back
            mask[3] = mstyle "default", "holes"
```

### pcb_holder

```
    CLASSES: add1, add2
DESCRIPTION: creates pcb holder for vertical mounting.
       MASK: no
      USAGE: "class", "pcb_holder", loc_x, loc_y, loc_z, face, rotation[], parametric[], size[], data[], mask[]

              class = "add1", "add2"
               type = "pcb_holder"
              loc_x = x location placement
              loc_y = y location placement
              loc_z = z location placement
               face = "top", "bottom", "right", "left", "front", "rear"
         rotation[] = object rotation
       parametric[] = "case", "sbc", "sbc-case_z"
            size[0] = pcb x size in mm
            size[1] = pcb y size in mm
            size[2] = pcb z size in mm
            data[0] = holder wall thickness
            mask[0] = false
            mask[1] = length
            mask[2] = set back
            mask[3] = mstyle "default"
```

### rectangle

```
    CLASSES: add1, add2, sub, suball
DESCRIPTION: creates or subtracts rectangular geometry with individual defined corner fillets. 
             Radius1 is lower left corner then moves clockwise.
       MASK: no
      USAGE: "class", "rectangle", loc_x, loc_y, loc_z, face, rotation[], parametric[], size[], data[], mask[]

              class = "add1", "add2", "sub", "suball"
               type = "rectangle"
              loc_x = x location placement
              loc_y = y location placement
              loc_z = z location placement
               face = "top", "bottom", "right", "left", "front", "rear"
         rotation[] = object rotation
       parametric[] = "case", "sbc", "sbc-case_z"
            size[0] = width
            size[1] = depth
            size[2] = height
            data[0] = [radius1, radius2, radius3, radius4]
            mask[0] = false, not used
            mask[1] = length
            mask[2] = set back
            mask[3] = mstyle "default"
```

### round

```
    CLASSES: add1, add2, sub, suball
DESCRIPTION: creates or subtracts circular geometry.
       MASK: no
      USAGE: "class", "round", loc_x, loc_y, loc_z, face, rotation[], parametric[], size[], data[], mask[]

              class = "add1", "add2", "sub", "suball"
               type = "round"
              loc_x = x location placement
              loc_y = y location placement
              loc_z = z location placement
               face = "top", "bottom", "right", "left", "front", "rear"
         rotation[] = object rotation
       parametric[] = "case", "sbc", "sbc-case_z"
            size[0] = diameter
            size[1] = not used
            size[2] = height
             data[] = not used
            mask[0] = false, not used
            mask[1] = length
            mask[2] = set back
            mask[3] = mstyle "default"
```

### slot

```
    CLASSES: add1, add2, sub, suball
DESCRIPTION: creates or subtracts slot geometry.
       MASK: no
      USAGE: "class", "slot", loc_x, loc_y, loc_z, face, rotation[], parametric[], size[], data[], mask[]

              class = "add1", "add2", "sub", "suball"
               type = "slot"
              loc_x = x location placement
              loc_y = y location placement
              loc_z = z location placement
               face = "top", "bottom", "right", "left", "front", "rear"
         rotation[] = object rotation
       parametric[] = "case", "sbc", "sbc-case_z"
            size[0] = diameter
            size[1] = length
            size[2] = height
             data[] = not used
            mask[0] = false, not used
            mask[1] = length
            mask[2] = set back
            mask[3] = mstyle "default"
```

### sphere

```
    CLASSES: add1, add2, sub, suball
DESCRIPTION: creates or subtracts sphere geometry.
       MASK: no
      USAGE: "class", "sphere", loc_x, loc_y, loc_z, face, rotation[], parametric[], size[], data[], mask[]

              class = "add1", "add2", "sub", "suball"
               type = "sphere"
              loc_x = x location placement
              loc_y = y location placement
              loc_z = z location placement
               face = "top", "bottom", "right", "left", "front", "rear"
         rotation[] = object rotation
       parametric[] = "case", "sbc", "sbc-case_z"
            size[0] = diameter
            size[1] = not used
            size[2] = not used
             data[] = not used
            mask[0] = false, not used
            mask[1] = length
            mask[2] = set back
            mask[3] = mstyle "default"
```

### standoff

```
    CLASSES: add2
DESCRIPTION: creates standoffs.
       MASK: yes
      USAGE: "add2", "standoff", loc_x, loc_y, loc_z, face, rotation[], parametric[], size[], data[], mask[]

              class = "add2"
               type = "standoff"
              loc_x = x location placement
              loc_y = y location placement
              loc_z = z location placement
               face = "top", "bottom"
         rotation[] = object rotation
       parametric[] = "case", "sbc", "sbc-case_z"
             size[] = not used
            data[0] = [size,diameter,height,holesize,supportsize,supportheight,sink,pillarstyle,pillarsupport,reverse,insert_e,i_dia,i_depth]

                       size = "m2_tap","m2","m2+","m2.5_tap","m2.5","m2.5+","m3_tap","m3","m3+","m4_tap","m4","m4+","custom"
                       diameter = pillar radius
                       height = total height
                       holesize = hole diameter
                       supportsize = support size for sink
                       supportheight = height of support for sink
                       sink = "none", "countersunk", "recessed", "nut holder", "blind"
                       pillarstyle = "hex", "round"
                       pillarsupport = "none", "left", "rear", "front", "right"
                       reverse = true or false
                       insert_e = true or false
                       i_dia = insert diameter
                       i_depth = insert hole depth

            mask[0] = true
            mask[1] = length
            mask[2] = set back
            mask[3] = mstyle "default"
```

### text

```
    CLASSES: add1, add2, sub, suball
DESCRIPTION: creates or subtracts raised or sunk text geometry.
       MASK: no
      USAGE: "class", "text", loc_x, loc_y, loc_z, face, rotation[], parametric[], size[], data[], mask[]

              class = "add1", "add2", "sub", "suball"
               type = "text"
              loc_x = x location placement
              loc_y = y location placement
              loc_z = z location placement
               face = "top", "bottom", "right", "left", "front", "rear"
         rotation[] = object rotation
       parametric[] = "case", "sbc", "sbc-case_z"
             size[] = not used
            data[0] = text size
            data[1] = "text"
            mask[0] = false, not used
            mask[1] = length
            mask[2] = set back
            mask[3] = mstyle "default"
```

### vent_panel_hex

```
    CLASSES: add1, add2, platter
DESCRIPTION: creates hex pattern covers for vent openings.
       MASK: no
      USAGE: "class", "vent_panel_hex", loc_x, loc_y, loc_z, face, rotation[], parametric[], size[], data[], mask[]

              class = "add1", "add2"
               type = "vent_panel_hex"
              loc_x = x location placement
              loc_y = y location placement
              loc_z = z location placement
               face = "top", "bottom", "right", "left", "front", "rear"
         rotation[] = object rotation
       parametric[] = "case", "sbc", "sbc-case_z"
            size[0] = #rows
            size[1] = #columns
            size[2] = thickness
            data[0] = size of hex
            data[1] = space between hex
            data[2] = size of borber
            data[3] = type of border "none", "default"
            mask[0] = false, not used
            mask[1] = length
            mask[2] = set back
            mask[3] = mstyle "default"
```

## Sub and Suball class “types”

### art

```
    CLASSES: add1, add2, sub, suball
DESCRIPTION: creates or subtracts art work geometry in dxf or svg format.
       MASK: no
      USAGE: "class", "art", loc_x, loc_y, loc_z, face, rotation[], parametric[], size[], data[], mask[]

              class = "add1", "add2", "sub", "suball"
               type = "art"
              loc_x = x location placement
              loc_y = y location placement
              loc_z = z location placement
               face = "top", "bottom", "right", "left", "front", "rear"
         rotation[] = object rotation
       parametric[] = "case", "sbc", "sbc-case_z"
             size[] = not used
            data[0] = scale
            data[1] = height
            data[2] = "file"
            mask[0] = false, not used
            mask[1] = length
            mask[2] = set back
            mask[3] = mstyle "default"
```

### fan_mask

```
    CLASSES: sub, suball
DESCRIPTION: creates fan openings in various styles and sizes.
       MASK: no
      USAGE: "class", "fan_mask", loc_x, loc_y, loc_z, face, rotation[], parametric[], size[], data[], mask[]

              class = "sub", "suball"
               type = "fan_mask"
              loc_x = x location placement
              loc_y = y location placement
              loc_z = z location placement
               face = "top", "bottom", "right", "left", "front", "rear"
         rotation[] = object rotation
       parametric[] = "case", "sbc", "sbc-case_z"
            size[0] = fan size of opening
            size[1] = not used
            size[2] = thickness
            data[0] = "fan_open", "fan_1", "fan_2", "fan_hex"
            mask[0] = false, not used
            mask[1] = length
            mask[2] = set back
            mask[3] = mstyle "default"
```

### hd_holes

```
    CLASSES: sub, suball
DESCRIPTION: creates hard drive holes for 2.5 and 3.5 drives in various orientations.
       MASK: no
      USAGE: "class", "hd_holes", loc_x, loc_y, loc_z, face, rotation[], parametric[], size[], data[], mask[]

              class = "sub", "suball"
               type = "hd_holes"
              loc_x = x location placement
              loc_y = y location placement
              loc_z = z location placement
               face = "top", "bottom", "right", "left", "front", "rear"
         rotation[] = object rotation
       parametric[] = "case", "sbc", "sbc-case_z"
             size[] = not used
            data[0] = 2.5 or 3.5
            data[1] = "portrait", "landscape"
            data[2] = "left", "right", "both", "bottom", "all"
            data[3] = floor thickness
            data[4] = "hole", "slot"
            mask[0] = false, not used
            mask[1] = length
            mask[2] = set back
            mask[3] = mstyle "default"
```

### knockout

```
    CLASSES: sub, suball
DESCRIPTION: creates knockouts in rectangle, round or slot shape.
       MASK: no
      USAGE: "class", "knockout", loc_x, loc_y, loc_z, face, rotation[], parametric[], size[], data[], mask[]

              class = "sub", "suball"
               type = "knockout"
              loc_x = x location placement
              loc_y = y location placement
              loc_z = z location placement
               face = "top", "bottom", "right", "left", "front", "rear"
         rotation[] = object rotation
       parametric[] = "case", "sbc", "sbc-case_z"
            size[0] = length
            size[1] = height
            size[2] = thickness
            data[0] = gap
            data[1] = fillet size
            data[2] = "slot", "rectangle", "round"
            mask[0] = false, not used
            mask[1] = length
            mask[2] = set back
            mask[3] = mstyle "default"
```

### rectangle

```
    CLASSES: add1, add2, sub, suball
DESCRIPTION: creates or subtracts rectangular geometry with individual defined corner fillets. 
             Radius1 is lower left corner then moves clockwise.
       MASK: no
      USAGE: "class", "rectangle", loc_x, loc_y, loc_z, face, rotation[], parametric[], size[], data[], mask[]

              class = "add1", "add2", "sub", "suball"
               type = "rectangle"
              loc_x = x location placement
              loc_y = y location placement
              loc_z = z location placement
               face = "top", "bottom", "right", "left", "front", "rear"
         rotation[] = object rotation
       parametric[] = "case", "sbc", "sbc-case_z"
            size[0] = width
            size[1] = depth
            size[2] = height
            data[0] = [radius1, radius2, radius3, radius4]
            mask[0] = false, not used
            mask[1] = length
            mask[2] = set back
            mask[3] = mstyle "default"
```

### round

```
    CLASSES: add1, add2, sub, suball
DESCRIPTION: creates or subtracts circular geometry.
       MASK: no
      USAGE: "class", "round", loc_x, loc_y, loc_z, face, rotation[], parametric[], size[], data[], mask[]

              class = "add1", "add2", "sub", "suball"
               type = "round"
              loc_x = x location placement
              loc_y = y location placement
              loc_z = z location placement
               face = "top", "bottom", "right", "left", "front", "rear"
         rotation[] = object rotation
       parametric[] = "case", "sbc", "sbc-case_z"
            size[0] = diameter
            size[1] = not used
            size[2] = height
             data[] = not used
            mask[0] = false, not used
            mask[1] = length
            mask[2] = set back
            mask[3] = mstyle "default"
```

### slot

```
    CLASSES: add1, add2, sub, suball
DESCRIPTION: creates or subtracts slot geometry.
       MASK: no
      USAGE: "class", "slot", loc_x, loc_y, loc_z, face, rotation[], parametric[], size[], data[], mask[]

              class = "add1", "add2", "sub", "suball"
               type = "slot"
              loc_x = x location placement
              loc_y = y location placement
              loc_z = z location placement
               face = "top", "bottom", "right", "left", "front", "rear"
         rotation[] = object rotation
       parametric[] = "case", "sbc", "sbc-case_z"
            size[0] = diameter
            size[1] = length
            size[2] = height
             data[] = not used
            mask[0] = false, not used
            mask[1] = length
            mask[2] = set back
            mask[3] = mstyle "default"
```

### sphere

```
    CLASSES: add1, add2, sub, suball
DESCRIPTION: creates or subtracts sphere geometry.
       MASK: no
      USAGE: "class", "sphere", loc_x, loc_y, loc_z, face, rotation[], parametric[], size[], data[], mask[]

              class = "add1", "add2", "sub", "suball"
               type = "sphere"
              loc_x = x location placement
              loc_y = y location placement
              loc_z = z location placement
               face = "top", "bottom", "right", "left", "front", "rear"
         rotation[] = object rotation
       parametric[] = "case", "sbc", "sbc-case_z"
            size[0] = diameter
            size[1] = not used
            size[2] = not used
             data[] = not used
            mask[0] = false, not used
            mask[1] = length
            mask[2] = set back
            mask[3] = mstyle "default"
```

### text

```
    CLASSES: add1, add2, sub, suball
DESCRIPTION: creates or subtracts raised or sunk text geometry.
       MASK: no
      USAGE: "class", "text", loc_x, loc_y, loc_z, face, rotation[], parametric[], size[], data[], mask[]

              class = "add1", "add2", "sub", "suball"
               type = "text"
              loc_x = x location placement
              loc_y = y location placement
              loc_z = z location placement
               face = "top", "bottom", "right", "left", "front", "rear"
         rotation[] = object rotation
       parametric[] = "case", "sbc", "sbc-case_z"
             size[] = not used
            data[0] = text size
            data[1] = "text"
            mask[0] = false, not used
            mask[1] = length
            mask[2] = set back
            mask[3] = mstyle "default"
```

### vent

```
    CLASSES: sub, suball
DESCRIPTION: creates horizontal or vertical vent openings.
       MASK: no
      USAGE: "class", "vent", loc_x, loc_y, loc_z, face, rotation[], parametric[], size[], data[], mask[]

              class = "sub", "suball"
               type = "vent"
              loc_x = x location placement
              loc_y = y location placement
              loc_z = z location placement
               face = "top", "bottom", "right", "left", "front", "rear"
         rotation[] = object rotation
       parametric[] = "case", "sbc", "sbc-case_z"
            size[0] = coloumn size_x
            size[1] = column size_y
            size[2] = height
            data[0] = #row
            data[1] = #columns
            data[2] = "horizontal", "vertical"
            data[3] = gap size
            mask[0] = false, not used
            mask[1] = length
            mask[2] = set back
            mask[3] = mstyle "default"
```

### vent_hex

```
    CLASSES: sub, suball
DESCRIPTION: creates horizontal or vertical hex vent openings.
       MASK: no
      USAGE: "class", "vent_hex", loc_x, loc_y, loc_z, face, rotation[], parametric[], size[], data[], mask[]

              class = "sub", "suball"
               type = "vent_hex"
              loc_x = x location placement
              loc_y = y location placement
              loc_z = z location placement
               face = "top", "bottom", "right", "left", "front", "rear"
         rotation[] = object rotation
       parametric[] = "case", "sbc", "sbc-case_z"
            size[0] = #rows
            size[1] = #columns
            size[2] = thickness
            data[0] = size of hex
            data[1] = space between hex
            data[2] = "horizontal", "vertical"
            data[3] = gap size
            mask[0] = false, not used
            mask[1] = length
            mask[2] = set back
            mask[3] = mstyle "default"
```

## Model class “types”

### adafruit_2030_powerboost

```
    CLASSES: model
DESCRIPTION: creates Adafruit 2030 Powerboost 1000 basic.
       MASK: yes
      USAGE: "model", "adafruit_2030_powerboost", loc_x, loc_y, loc_z, face, rotation[], parametric[], size[], data[], mask[]

              class = "model"
               type = "adafruit_2030_powerboost"
              loc_x = x location placement
              loc_y = y location placement
              loc_z = z location placement
               face = "top", "bottom", "right", "left", "front", "rear"
         rotation[] = object rotation
       parametric[] = "case", "sbc", "sbc-case_z"
             size[] = not used
             data[] = not used
            mask[0] = true
            mask[1] = length
            mask[2] = set back
            mask[3] = mstyle "default"
```

### adafruit_4311_lcd

```
    CLASSES: model
DESCRIPTION: creates Adafruit 4311 2.0" 320x240 Color IPS TFT Display with microSD Card Breakout - ST7789 EYESPI.
       MASK: yes
      USAGE: "model", "adafruit_4311_lcd", loc_x, loc_y, loc_z, face, rotation[], parametric[], size[], data[], mask[]

              class = "model"
               type = "adafruit_4311_lcd"
              loc_x = x location placement
              loc_y = y location placement
              loc_z = z location placement
               face = "top", "bottom", "right", "left", "front", "rear"
         rotation[] = object rotation
       parametric[] = "case", "sbc", "sbc-case_z"
             size[] = not used
             data[] = not used
            mask[0] = true
            mask[1] = length
            mask[2] = set back
            mask[3] = mstyle "default"
```

### adafruit_4755_solar_charger

```
    CLASSES: model
DESCRIPTION: creates Adafruit 4755 Universal USB/DC/Solar Lithium Ion/Polymer charger - bq24074.
       MASK: yes
      USAGE: "model", "adafruit_4755_solar_charger", loc_x, loc_y, loc_z, face, rotation[], parametric[], size[], data[], mask[]

              class = "model"
               type = "adafruit_4755_solar_charger"
              loc_x = x location placement
              loc_y = y location placement
              loc_z = z location placement
               face = "top", "bottom", "right", "left", "front", "rear"
         rotation[] = object rotation
       parametric[] = "case", "sbc", "sbc-case_z"
             size[] = not used
             data[] = not used
            mask[0] = true
            mask[1] = length
            mask[2] = set back
            mask[3] = mstyle "default"
```

### dsub

```
    CLASSES: model
DESCRIPTION: creates db connectors.
       MASK: yes
      USAGE: "model", "dsub", loc_x, loc_y, loc_z, face, rotation[], parametric[], size[], data[], mask[]

              class = "model"
               type = "dsub"
              loc_x = x location placement
              loc_y = y location placement
              loc_z = z location placement
               face = "top", "bottom", "right", "left", "front", "rear"
         rotation[] = object rotation
       parametric[] = "case", "sbc", "sbc-case_z"
             size[] = not used
            data[0] = "db9"
            data[1] = "female"
            mask[0] = true
            mask[1] = length
            mask[2] = set back
            mask[3] = mstyle "default"
```

### fan

```
    CLASSES: model
DESCRIPTION: creates fans.
       MASK: yes
      USAGE: "model", "fan", loc_x, loc_y, loc_z, face, rotation[], parametric[], size[], data[], mask[]

              class = "model"
               type = "fan"
              loc_x = x location placement
              loc_y = y location placement
              loc_z = z location placement
               face = "top", "bottom", "right", "left", "front", "rear"
         rotation[] = object rotation
       parametric[] = "case", "sbc", "sbc-case_z"
             size[] = not used
            data[0] = "box25x10","box30x10","box40x10","box50x10","box60x10","box80x10","box80x25","box92x10","box92x25","box120x25","box140x25"
            mask[0] = true
            mask[1] = length
            mask[2] = set back
            mask[3] = mstyle "default", "fan_open", "fan_1", "fan_2", "fan_hex"
```

### hd25

```
    CLASSES: model
DESCRIPTION: creates a 2.5 hard drive model.
       MASK: yes
      USAGE: "model", "hd25", loc_x, loc_y, loc_z, face, rotation[], parametric[], size[], data[], mask[]

              class = "model"
               type = "hd25"
              loc_x = x location placement
              loc_y = y location placement
              loc_z = z location placement
               face = "top", "bottom", "right", "left", "front", "rear"
         rotation[] = object rotation
       parametric[] = "case", "sbc", "sbc-case_z"
             size[] = not used
            data[0] = "landscape", "portrait"
            data[1] = height
            mask[0] = true
            mask[1] = length
            mask[2] = set back
            mask[3] = mstyle "default", "bottom", "side", "both"
```

### hd35

```
    CLASSES: model
DESCRIPTION: creates a 3.5 hard drive model.
       MASK: yes
      USAGE: "model", "hd35", loc_x, loc_y, loc_z, face, rotation[], parametric[], size[], data[], mask[]

              class = "model"
               type = "hd35"
              loc_x = x location placement
              loc_y = y location placement
              loc_z = z location placement
               face = "top", "bottom", "right", "left", "front", "rear"
         rotation[] = object rotation
       parametric[] = "case", "sbc", "sbc-case_z"
             size[] = not used
            data[0] = "landscape", "portrait"
            mask[0] = true
            mask[1] = length
            mask[2] = set back
            mask[3] = mstyle "default", "bottom", "side", "both"
```

### hk_h3_port_extender

```
    CLASSES: model
DESCRIPTION: creates hk port extender model.
       MASK: yes
      USAGE: "model", "hk_h3_port_extender", loc_x, loc_y, loc_z, face, rotation[], parametric[], size[], data[], mask[]

              class = "model"
               type = "hk_h3_port_extender"
              loc_x = x location placement
              loc_y = y location placement
              loc_z = z location placement
               face = "top", "bottom", "right", "left", "front", "rear"
         rotation[] = object rotation
       parametric[] = "case", "sbc", "sbc-case_z"
             size[] = not used
            data[0] = "header", "remote"
            mask[0] = true
            mask[1] = length
            mask[2] = set back
            mask[3] = mstyle "default"
```

### hk_boom

```
    CLASSES: model
DESCRIPTION: creates hardkernel boom bonnet model.
       MASK: yes
      USAGE: "model", "hk_boom", loc_x, loc_y, loc_z, face, rotation[], parametric[], size[], data[], mask[]

              class = "model"
               type = "hk_boom"
              loc_x = x location placement
              loc_y = y location placement
              loc_z = z location placement
               face = "top", "bottom", "right", "left", "front", "rear"
         rotation[] = object rotation
       parametric[] = "case", "sbc", "sbc-case_z"
             size[] = not used
            data[0] = true, false speakers
            data[1] = "front", "rear" facing 
            mask[0] = true
            mask[1] = length
            mask[2] = set back
            mask[3] = mstyle "default"
```

### hk_boom_speaker

```
    CLASSES: model
DESCRIPTION: creates hk stereo boom bonnet speaker model.
       MASK: yes
      USAGE: "model", "hk_boom_speaker", loc_x, loc_y, loc_z, face, rotation[], parametric[], size[], data[], mask[]

              class = "model"
               type = "hk_boom_speaker"
              loc_x = x location placement
              loc_y = y location placement
              loc_z = z location placement
               face = "top", "bottom", "right", "left", "front", "rear"
         rotation[] = object rotation
       parametric[] = "case", "sbc", "sbc-case_z"
             size[] = not used
             data[] = not used
            mask[0] = true
            mask[1] = length
            mask[2] = set back
            mask[3] = mstyle "default"
```

### hk_boom_speaker_pcb

```
    CLASSES: model
DESCRIPTION: creates hk stereo boom bonnet speaker pcb mounted model.
       MASK: yes
      USAGE: "model", "hk_boom_speaker_pcb", loc_x, loc_y, loc_z, face, rotation[], parametric[], size[], data[], mask[]

              class = "model"
               type = "hk_boom_speaker_pcb"
              loc_x = x location placement
              loc_y = y location placement
              loc_z = z location placement
               face = "top", "bottom", "right", "left", "front", "rear"
         rotation[] = object rotation
       parametric[] = "case", "sbc", "sbc-case_z"
             size[] = not used
            data[0] = true, false pcb
            data[1] = "left", "right"
            mask[0] = true
            mask[1] = length
            mask[2] = set back
            mask[3] = mstyle "default"
```

### hk_hc4_oled

```
    CLASSES: model
DESCRIPTION: creates hk odroid-hc4 oled model.
       MASK: yes
      USAGE: "model", "hk_hc4_oled", loc_x, loc_y, loc_z, face, rotation[], parametric[], size[], data[], mask[]

              class = "model"
               type = "hk_hc4_oled"
              loc_x = x location placement
              loc_y = y location placement
              loc_z = z location placement
               face = "top", "bottom", "right", "left", "front", "rear"
         rotation[] = object rotation
       parametric[] = "case", "sbc", "sbc-case_z"
             size[] = not used
             data[] = not used
            mask[0] = true
            mask[1] = length
            mask[2] = set back
            mask[3] = mstyle "default"
```

### hk_lcd35

```
    CLASSES: model
DESCRIPTION: creates hk 3.5" lcd model.
       MASK: yes
      USAGE: "model", "hk_lcd35", loc_x, loc_y, loc_z, face, rotation[], parametric[], size[], data[], mask[]

              class = "model"
               type = "hk_lcd35"
              loc_x = x location placement
              loc_y = y location placement
              loc_z = z location placement
               face = "top", "bottom", "right", "left", "front", "rear"
         rotation[] = object rotation
       parametric[] = "case", "sbc", "sbc-case_z"
             size[] = not used
             data[] = not used
            mask[0] = true
            mask[1] = length
            mask[2] = set back
            mask[3] = mstyle "default"
```

### hk_m1s_ups

```
    CLASSES: model
DESCRIPTION: creates hk odroid-m1s ups model.
       MASK: yes
      USAGE: "model", "hk_m1s_ups", loc_x, loc_y, loc_z, face, rotation[], parametric[], size[], data[], mask[]

              class = "model"
               type = "hk_m1s_ups"
              loc_x = x location placement
              loc_y = y location placement
              loc_z = z location placement
               face = "top", "bottom", "right", "left", "front", "rear"
         rotation[] = object rotation
       parametric[] = "case", "sbc", "sbc-case_z"
             size[] = not used
             data[] = not used
            mask[0] = true
            mask[1] = length
            mask[2] = set back
            mask[3] = mstyle "default"
```

### hk_netcard

```
    CLASSES: model
DESCRIPTION: creates hk 4 port 2.5gb netcard model.
       MASK: yes
      USAGE: "model", "hk_netcard", loc_x, loc_y, loc_z, face, rotation[], parametric[], size[], data[], mask[]

              class = "model"
               type = "hk_netcard"
              loc_x = x location placement
              loc_y = y location placement
              loc_z = z location placement
               face = "top", "bottom", "right", "left", "front", "rear"
         rotation[] = object rotation
       parametric[] = "case", "sbc", "sbc-case_z"
             size[] = not used
             data[] = not used
            mask[0] = true
            mask[1] = length
            mask[2] = set back
            mask[3] = mstyle "default"
```

### hk_pwr_button

```
    CLASSES: model
DESCRIPTION: creates hk backlite power button model.
       MASK: yes
      USAGE: "model", "hk_pwr_button", loc_x, loc_y, loc_z, face, rotation[], parametric[], size[], data[], mask[]

              class = "model"
               type = "hk_pwr_button"
              loc_x = x location placement
              loc_y = y location placement
              loc_z = z location placement
               face = "top", "bottom", "right", "left", "front", "rear"
         rotation[] = object rotation
       parametric[] = "case", "sbc", "sbc-case_z"
             size[] = not used
             data[] = not used
            mask[0] = true
            mask[1] = length
            mask[2] = set back
            mask[3] = mstyle "default"
```

### hk_speaker

```
    CLASSES: model
DESCRIPTION: creates hk speaker model.
       MASK: yes
      USAGE: "model", "hk_speaker", loc_x, loc_y, loc_z, face, rotation[], parametric[], size[], data[], mask[]

              class = "model"
               type = "hk_speaker"
              loc_x = x location placement
              loc_y = y location placement
              loc_z = z location placement
               face = "top", "bottom", "right", "left", "front", "rear"
         rotation[] = object rotation
       parametric[] = "case", "sbc", "sbc-case_z"
             size[] = not used
             data[] = not used
            mask[0] = true
            mask[1] = length
            mask[2] = set back
            mask[3] = mstyle "default"
```

### hk_uart

```
    CLASSES: model
DESCRIPTION: creates hk micro-usb uart model.
       MASK: yes
      USAGE: "model", "hk_uart", loc_x, loc_y, loc_z, face, rotation[], parametric[], size[], data[], mask[]

              class = "model"
               type = "hk_uart"
              loc_x = x location placement
              loc_y = y location placement
              loc_z = z location placement
               face = "top", "bottom", "right", "left", "front", "rear"
         rotation[] = object rotation
       parametric[] = "case", "sbc", "sbc-case_z"
             size[] = not used
             data[] = not used
            mask[0] = true
            mask[1] = length
            mask[2] = set back
            mask[3] = mstyle "default"
```

### hk_vu7c

```
    CLASSES: model
DESCRIPTION: creates hk vu7c model with optional gpio extension and tabs.
       MASK: yes
      USAGE: "model", "hk_vu7c", loc_x, loc_y, loc_z, face, rotation[], parametric[], size[], data[], mask[]

              class = "model"
               type = "hk_vu7c"
              loc_x = x location placement
              loc_y = y location placement
              loc_z = z location placement
               face = "top", "bottom", "right", "left", "front", "rear"
         rotation[] = object rotation
       parametric[] = "case", "sbc", "sbc-case_z"
             size[] = not used
            data[0] = true, false gpio_ext
            data[1] = true, false tabs
            mask[0] = true
            mask[1] = length
            mask[2] = set back
            mask[3] = mstyle "default"
```

### hk_vu8m

```
    CLASSES: model
DESCRIPTION: creates hk vu8m model with optional brackets.
       MASK: yes
      USAGE: "model", "hk_vu8m", loc_x, loc_y, loc_z, face, rotation[], parametric[], size[], data[], mask[]

              class = "model"
               type = "hk_vu8m"
              loc_x = x location placement
              loc_y = y location placement
              loc_z = z location placement
               face = "top", "bottom", "right", "left", "front", "rear"
         rotation[] = object rotation
       parametric[] = "case", "sbc", "sbc-case_z"
             size[] = not used
            data[0] = true, false brackets
            mask[0] = true
            mask[1] = length
            mask[2] = set back
            mask[3] = mstyle "default"
```

### hk_vu8s

```
    CLASSES: model
DESCRIPTION: creates hk vu8s model.
       MASK: yes
      USAGE: "model", "hk_vu8s", loc_x, loc_y, loc_z, face, rotation[], parametric[], size[], data[], mask[]

              class = "model"
               type = "hk_vu8s"
              loc_x = x location placement
              loc_y = y location placement
              loc_z = z location placement
               face = "top", "bottom", "right", "left", "front", "rear"
         rotation[] = object rotation
       parametric[] = "case", "sbc", "sbc-case_z"
             size[] = not used
             data[] = not used
            mask[0] = true
            mask[1] = length
            mask[2] = set back
            mask[3] = mstyle "default"
```

### hk_wb2

```
    CLASSES: model
DESCRIPTION: creates hk weather board 2 model.
       MASK: no
      USAGE: "model", "hk_wb2", loc_x, loc_y, loc_z, face, rotation[], parametric[], size[], data[], mask[]

              class = "model"
               type = "hk_wb2"
              loc_x = x location placement
              loc_y = y location placement
              loc_z = z location placement
               face = "top", "bottom", "right", "left", "front", "rear"
         rotation[] = object rotation
       parametric[] = "case", "sbc", "sbc-case_z"
             size[] = not used
             data[] = not used
            mask[0] = false
            mask[1] = length
            mask[2] = set back
            mask[3] = mstyle "default"
```

### hk_xu4_shifter_shield

```
    CLASSES: model
DESCRIPTION: creates hk odroid-xu5 level shifter shield model.
       MASK: yes
      USAGE: "model", "hk_xu4_shifter_shield", loc_x, loc_y, loc_z, face, rotation[], parametric[], size[], data[], mask[]

              class = "model"
               type = "hk_xu4_shifter_shield"
              loc_x = x location placement
              loc_y = y location placement
              loc_z = z location placement
               face = "top", "bottom", "right", "left", "front", "rear"
         rotation[] = object rotation
       parametric[] = "case", "sbc", "sbc-case_z"
             size[] = not used
             data[] = not used
            mask[0] = true
            mask[1] = length
            mask[2] = set back
            mask[3] = mstyle "default"
```

### pillar

```
    CLASSES: model
DESCRIPTION: creates pillars with female ends.
       MASK: yes
      USAGE: "model", "pillar", loc_x, loc_y, loc_z, face, rotation[], parametric[], size[], data[], mask[]

              class = "model"
               type = "pillar"
              loc_x = x location placement
              loc_y = y location placement
              loc_z = z location placement
               face = "top", "bottom", "right", "left", "front", "rear"
         rotation[] = object rotation
       parametric[] = "case", "sbc", "sbc-case_z"
            size[0] = outside diameter
            size[1] = inside diameter
            size[2] = height
            data[0] = "hex", "round"
            data[1] = "color"
            data[2] = side "top" or "bottom"
            mask[0] = false
            mask[1] = length
            mask[2] = set back
            mask[3] = mstyle "default"
```

### rpi_m2hat

```
    CLASSES: model
DESCRIPTION: adds Raspberry Pi M.2 HAT+ M Key model
       MASK: yes
      USAGE: "model", "rpi_m2hat", loc_x, loc_y, loc_z, face, rotation[], parametric[], size[], data[], mask[]

              class = "model"
               type = "rpi_m2hat"
              loc_x = x location placement
              loc_y = y location placement
              loc_z = z location placement
               face = "top", "bottom", "right", "left", "front", "rear"
         rotation[] = object rotation
       parametric[] = "case", "sbc", "sbc-case_z"
             size[] = not used
             data[] = not used
            mask[0] = true, false
            mask[1] = length
            mask[2] = set back
            mask[3] = mstyle "default"
```

### stl_model

```
    CLASSES: model
DESCRIPTION: adds stl models.
       MASK: no
      USAGE: "model", "stl_model", loc_x, loc_y, loc_z, face, rotation[], parametric[], size[], data[], mask[]

              class = "model"
               type = "stl_model"
              loc_x = x location placement
              loc_y = y location placement
              loc_z = z location placement
               face = "top", "bottom", "right", "left", "front", "rear"
         rotation[] = object rotation
       parametric[] = "case", "sbc", "sbc-case_z"
             size[] = not used
            data[0] = scale
            data[1] = "file name"
            mask[0] = false, not used
            mask[1] = length
            mask[2] = set back
            mask[3] = mstyle "default"
```

## Platter class “types”

### access_cover

```
    CLASSES: add1, add2, platter
DESCRIPTION: creates bottom access cover for access panels.
       MASK: no
      USAGE: "class", "access_cover", loc_x, loc_y, loc_z, face, rotation[], parametric[], size[], data[], mask[]

              class = "add1", "add2", "platter"
               type = "access_cover"
              loc_x = x location placement
              loc_y = y location placement
              loc_z = z location placement
               face = "top", "bottom", "right", "left", "front", "rear"
         rotation[] = object rotation
       parametric[] = "case", "sbc", "sbc-case_z"
            size[0] = x dimension
            size[1] = y dimension
            size[2] = floor thickness
            data[0] = "portrait", "landscape"
            mask[0] = false, not used
            mask[1] = length
            mask[2] = set back
            mask[3] = mstyle "default"
```

### button_assembly

```
    CLASSES: add2, platter
DESCRIPTION: adds button assembly for recess button style.
       MASK: yes
      USAGE: "add2", "button_assembly", loc_x, loc_y, loc_z, face, rotation[], parametric[], size[], data[], mask[]

              class = "add2"
               type = "button_assembly"
              loc_x = x location placement
              loc_y = y location placement
              loc_z = z location placement
               face = "top", "bottom", "right", "left", "front", "rear"
         rotation[] = object rotation
       parametric[] = "case", "sbc", "sbc-case_z"
            size[0] = diameter of button body for recess style
            size[1] = not used
            size[2] = height above button for recess style
            data[0] = "recess"
            mask[0] = true
            mask[1] = length
            mask[2] = set back
            mask[3] = mstyle "default"
```

### fan_cover

```
    CLASSES: add1, add2, platter
DESCRIPTION: creates fan cover for fan openings.
       MASK: no
      USAGE: "class", "fan_cover", loc_x, loc_y, loc_z, face, rotation[], parametric[], size[], data[], mask[]

              class = "add1", "add2", "platter"
               type = "fan_cover"
              loc_x = x location placement
              loc_y = y location placement
              loc_z = z location placement
               face = "top", "bottom", "right", "left", "front", "rear"
         rotation[] = object rotation
       parametric[] = "case", "sbc", "sbc-case_z"
            size[0] = fan size
            size[1] = not used
            size[2] = cover thickness
            data[0] = "fan_open", "fan_1", "fan_2", "fan_hex"
            mask[0] = false, not used
            mask[1] = length
            mask[2] = set back
            mask[3] = mstyle "default"
```

### feet

```
    CLASSES: add1, add2, platter
DESCRIPTION: creates case feet.
       MASK: no
      USAGE: "class", "feet", loc_x, loc_y, loc_z, face, rotation[], parametric[], size[], data[], mask[]

              class = "add1", "add2", "platter"
               type = "feet"
              loc_x = x location placement
              loc_y = y location placement
              loc_z = z location placement
               face = "top", "bottom", "right", "left", "front", "rear"
         rotation[] = object rotation
       parametric[] = "case", "sbc", "sbc-case_z"
            size[0] = feet diameter
            size[1] = not used
            size[2] = feet height
             data[] = not used
            mask[0] = false, not used
            mask[1] = length
            mask[2] = set back
            mask[3] = mstyle "default"
```

### grommet

```
    CLASSES: add1, add2, platter
DESCRIPTION: creates different groumet styles.
       MASK: yes
      USAGE: "class", "grommet", loc_x, loc_y, loc_z, face, rotation[], parametric[], size[], data[], mask[]

              class = "add1", "add2", "platter"
               type = "grommet"
              loc_x = x location placement
              loc_y = y location placement
              loc_z = z location placement
               face = "top", "bottom", "right", "left", "front", "rear"
         rotation[] = object rotation
       parametric[] = "case", "sbc", "sbc-case_z"
            size[0] = od outside diameter of grommet body
            size[1] = id inside hole diameter of grommet body
            size[2] = wall thickness of installation
            data[0] = "top","bottom","front","rear","left","right"
            data[1] = "sleeve"
            data[2] = assembled true, false 
            mask[0] = true enables component mask
            mask[1] = mask length
            mask[2] = mask setback
            mask[3] = mstyle "default"
```

### hk_boom_speaker_holder

```
    CLASSES: add2, platter
DESCRIPTION: creates hk boom bonnet speaker clamp and friction style holder.
       MASK: no
      USAGE: "class", "hk_boom_speaker_holder", loc_x, loc_y, loc_z, face, rotation[], parametric[], size[], data[], mask[]

              class = "add2"
               type = "hk_boom_speaker_holder"
              loc_x = x location placement
              loc_y = y location placement
              loc_z = z location placement
               face = "top", "bottom", "right", "left", "front", "rear"
         rotation[] = object rotation
       parametric[] = "case", "sbc", "sbc-case_z"
             size[] = not used
            data[0] = "friction", "clamp"
            data[1] = tolerance adjustment
            mask[0] = false
            mask[1] = length
            mask[2] = set back
            mask[3] = mstyle "default"
```

### hk_boom_vring

```
    CLASSES: add1, add2, platter
DESCRIPTION: creates hk stereo boom bonnet volume wheel extention.
       MASK: no
      USAGE: "class", "hk_boom_vring", loc_x, loc_y, loc_z, face, rotation[], parametric[], size[], data[], mask[]

              class = "add1", "add2", "platter"
               type = "hk_boom_vring"
              loc_x = x location placement
              loc_y = y location placement
              loc_z = z location placement
               face = "top", "bottom", "right", "left", "front", "rear"
         rotation[] = object rotation
       parametric[] = "case", "sbc", "sbc-case_z"
             size[] = not used
            data[0] = tolerance adjustment
            mask[0] = false
            mask[1] = length
            mask[2] = set back
            mask[3] = mstyle "default"
```

### hk_h3_port_extender_holder

```
    CLASSES: add1, add2, platter
DESCRIPTION: creates odroid-h3 port extender holder parts.
       MASK: no
      USAGE: "class", "hk_h3_port_extender_holder", loc_x, loc_y, loc_z, face, rotation[], parametric[], size[], data[], mask[]

              class = "add1", "add2", "platter"
               type = "hk_h3_port_extender_holder"
              loc_x = x location placement
              loc_y = y location placement
              loc_z = z location placement
               face = "top", "bottom", "right", "left", "front", "rear"
         rotation[] = object rotation
       parametric[] = "case", "sbc", "sbc-case_z"
             size[] = not used
            data[0] = distance from mount face
            data[1] = "top", "bottom", "both"
            mask[0] = false
            mask[1] = length
            mask[2] = set back
            mask[3] = mstyle "default"
```

### hk_uart_strap

```
    CLASSES: add2, platter
DESCRIPTION: creates a strap for the hk micro-usb uart holder.
       MASK: no
      USAGE: "class", "hk_uart_holder", loc_x, loc_y, loc_z, face, rotation[], parametric[], size[], data[], mask[]

              class = "add2"
               type = "hk_uart_holder"
              loc_x = x location placement
              loc_y = y location placement
              loc_z = z location placement
               face = "top", "bottom", "right", "left", "front", "rear"
         rotation[] = object rotation
       parametric[] = "case", "sbc", "sbc-case_z"
             size[] = not used
             data[] = not used
            mask[0] = false
            mask[1] = length
            mask[2] = set back
            mask[3] = mstyle "default"
```

### vent_panel_hex

```
    CLASSES: add1, add2, platter
DESCRIPTION: creates hex pattern covers for vent openings.
       MASK: no
      USAGE: "class", "vent_panel_hex", loc_x, loc_y, loc_z, face, rotation[], parametric[], size[], data[], mask[]

              class = "add1", "add2"
               type = "vent_panel_hex"
              loc_x = x location placement
              loc_y = y location placement
              loc_z = z location placement
               face = "top", "bottom", "right", "left", "front", "rear"
         rotation[] = object rotation
       parametric[] = "case", "sbc", "sbc-case_z"
            size[0] = #rows
            size[1] = #columns
            size[2] = thickness
            data[0] = size of hex
            data[1] = space between hex
            data[2] = size of borber
            data[3] = type of border "none", "default"
            mask[0] = false, not used
            mask[1] = length
            mask[2] = set back
            mask[3] = mstyle "default"
```

## Case Build Notes
This area covers specific build notes for specific cases.  Hardware used or other relavent information is list by case design name.

### panel_nas Case Design
The panel_nas design can be CNC cut or 3D printed.  By changing the top and bottom standoff type to "none" in the *SBC Standoff Global Settings* tabs respectively, only a hole is generated for CNC cutting support.  Panels can be exported in DXF or SVG by selecting the *part" view under the *view* tab, then the indivual part and select the *section part* checkbox. After the projection has been generated render it by pressing F7 or by selecting render from the user interface.  Exported DXF and SVG file formats are available under the File->Export menu.

Normally the top and bottom height added together is the overall case height for other cases.  But with hard drives involved there is additional height which is represented in its total by the height value.  In the example, the top is 41mm tall from the outside of the case to the top of the PCB.  In a bottom mounted case, 22.25mm measurement would be from the bottom of the case to the top of the PCB, which is sunk by it’s thickness so that the PCB top is even with the top edge of the bottom case piece normally.  So the equations for the standoff lengths would be:

Top standoff length = top height – floor thickness
38mm = 41mm – 3mm

Bottom standoff height = bottom height – floor thickness – PCB thickness
17mm = 22.25mm – 3mm – 2.25mm

2.5” drives are supported using a 3.5” holder adapter.  There is one in SBCCB that can be accessed using a new program, sbccb_accessory_tool.scad.  The holder can also be wider then a 3.5” drive (101.6mm) for an exact case fit.

For internal mounted rear fans, room above the rear fans equal to the 10mm tab size is required to remove the rear piece.

### rack Case Design
This case is divided into 3 pieces for the 19" cases and 2 pieces for the 10" cases.  They can be selected in the *part* view for STL export under the *view* tab by selecting the left, bottom or right individual part.  The peices are held together using M2x8mm screws and nuts.

10” rack case Qty 5 - M2x8mm screws cap or countersunk with nuts.
19” rack case Qty 10 - M2x8mm screws cap or countersunk with nuts.
Appropriate fasteners for all SBC.

For a better fit, prep the edges of the case pieces prior to assembly.  Use sand paper or a file to remove any imperfections and true the edge.

Using 2mm thickness for the floor and walls provides for an adequate case in most enclosed applications but a 3mm floor  or better is recommended for removable and open front cases.

There are 3mm holes on the left, center and right, both front and rear, to use for feet when deployed as a single bench top case.  If using the rack stands, the holes can be used to mount an external standoff to support the rear of a heavy case.

All case bodies can be printed without the use of support.  Only the removable bay tray needs support for printing.  SBC placement so as to bisect a SBC opening with a case divide, will require print supports.

Varies accessories (1u rack stand, grommets, fan covers, 2.5” drive holder, washers, etc) are available from sbccb_accessory_tool.scad.  The table top rack stand is comprised of two interchangeable brackets that can hold 1U-4U rack cases.

## Accuracy

In the past there was been no way of validating whether a SBC Model Framework model and its components were dimensionaly accurate in their size and placement other then trial and error. Along with producing cases this project provides a much needed model validation tool to assure model accuracy thru the use of test cases. It works on the very simple premise that if the real SBC fits the test case then the virtual model is accurate or otherwise shows were corrections are needed. This will further increased the overall accuracy of models over time.

Some SBC in SBC Model Framework have not been validated or may be missing component data and may produce one or more aspects of a case incorrectly.  SBC status is noted in sbc.png and sbc_models_viwer.scad, all a part of SBC Model Framework.  The color coded indicator of a SBC’s verification and completion is indicated in sbc.png as follows:

- GREEN = verified, complete and passes SBC Case Builder
- YELLOW = unverified, mostlikely usable and/or missing minor information
- ORANGE = unverified, may be usable but missing component data
- RED = unverified, not usable due to incomplete component data

The SBC that I do not own have been created using manufacturer supplied models, mechanical drawings or contributed by users.  Some of the drawings are missing information or have errors that effect all or part of the subsequent SBC models.  If you own an SBC that is not represented or verified in SBC Model Framework, please consider adding it or helping to correct any errors in the SBC data.  An SBC can be verified to be accurate if a printed shell case from SBC Case Builder fits.  Any misalignment is corrected in the SBC Model Framework model data(sbc_models.cfg).

## Future Development

There are a few more ideas for base cases to be worked on as well as a host of supporting accessory models that need to be created.  It would also be nice to have all of the OEM accessories for each OEM in the library as well.  I’m still looking for a better way to create accessory entries and groups, and  continue to expand and verify as many SBC as possible. With that and the obvious benefit of autonomously making SBC cases, this project has also been helping fulfill another personal goal.

Computer aided design(CAD) has been around a long time but I have been interested in exploring approaches to the next step, computer autonomous design.  Regardless of the current or future object creation method, whether it be manufactured or materialized, I believe a universal approach to autonomous design will be needed to advance the human condition.  This application has helped me explore and think about practical approaches that might be possible right now in autonomous design and I hope to continue this work by developing new tools and techniques for the new CAD, Computer Autonomous Design.

## Project Supporters

Thank You to the contributors for their contributions and also HardKernel and Pine64 for their support through the donation of SBC.

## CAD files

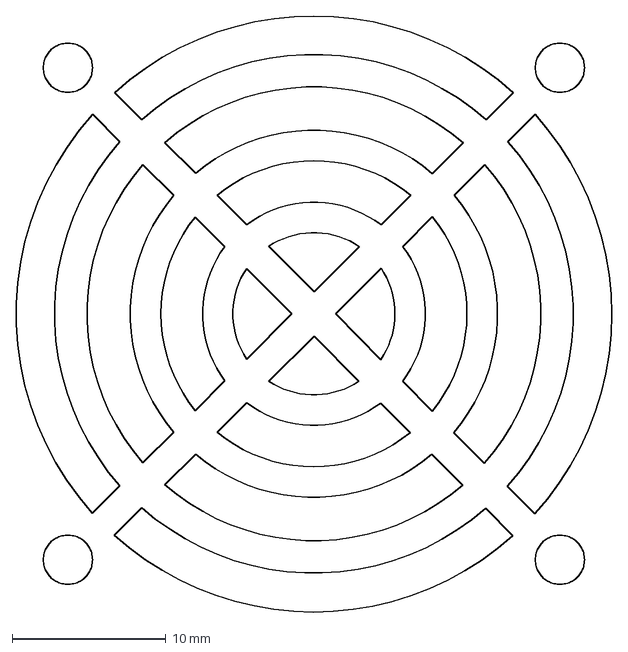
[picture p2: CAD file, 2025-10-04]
dxf/customfan.dxf
38.7 x 38.8 mm

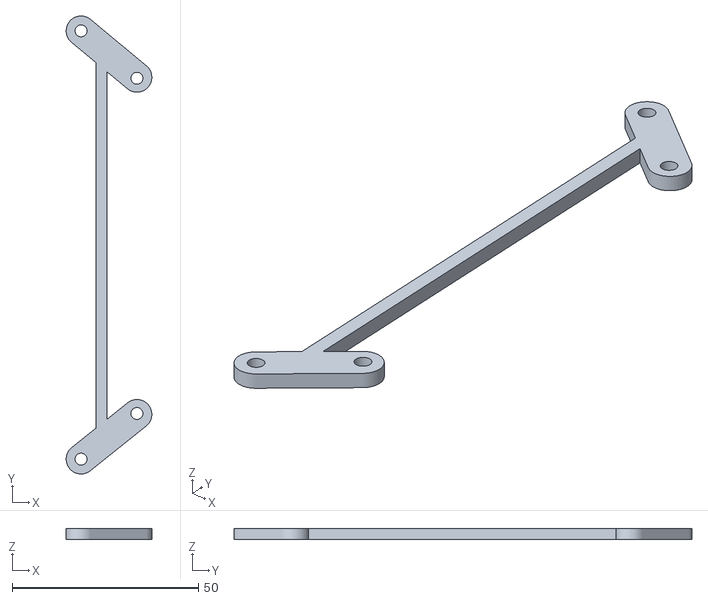
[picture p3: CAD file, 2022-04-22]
stl/Vu7_Speaker_Bracket_Right.stl
23.0 x 123.0 x 3.00

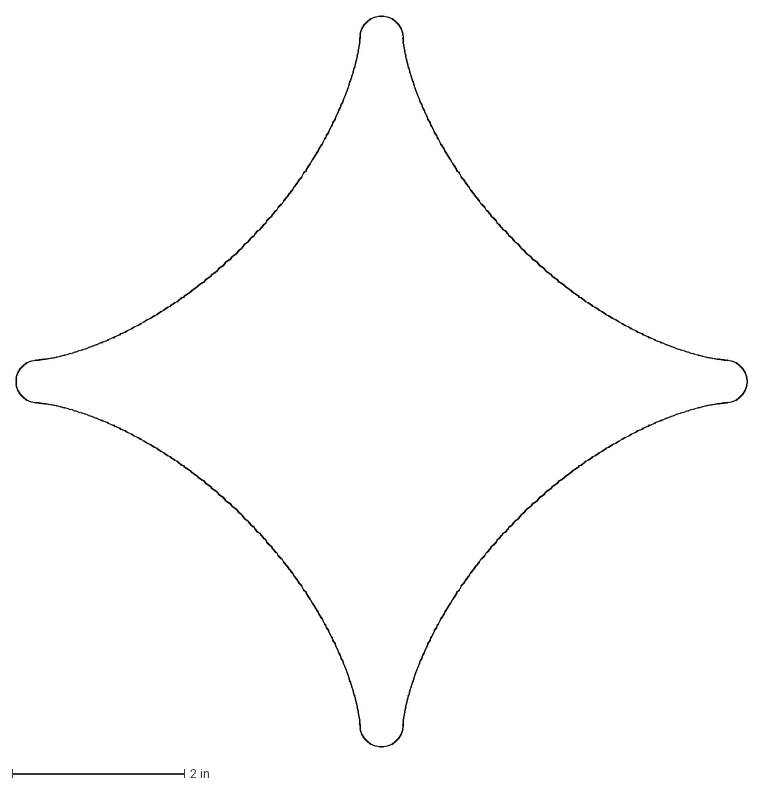
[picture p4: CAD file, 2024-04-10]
dxf/astroid_8mm.dxf
8.50 x 8.50 in

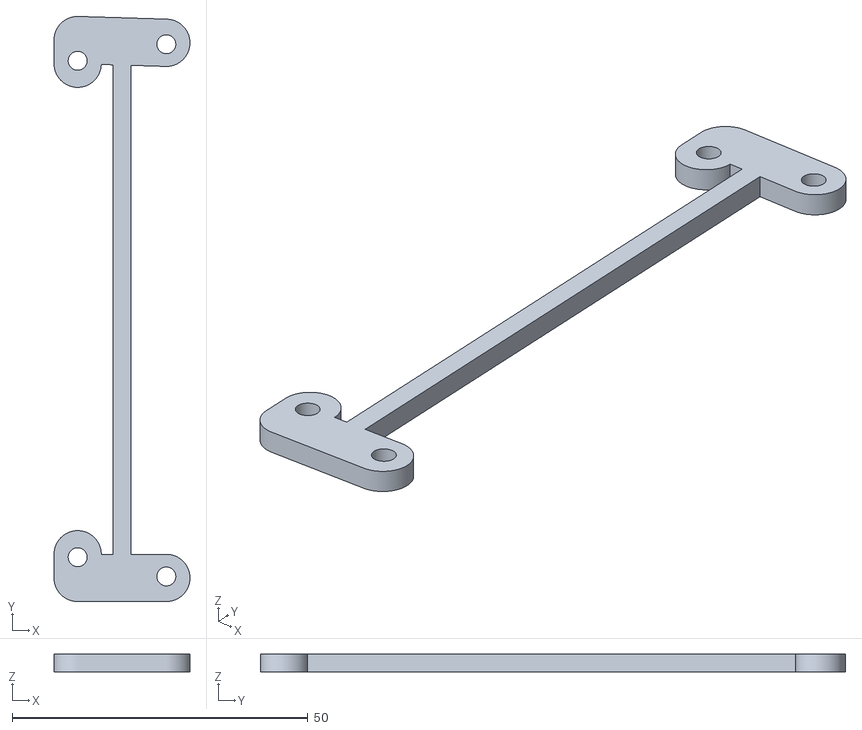
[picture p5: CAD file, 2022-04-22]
stl/Vu5_Speaker_Bracket_Right.stl
23.0 x 99.0 x 3.00

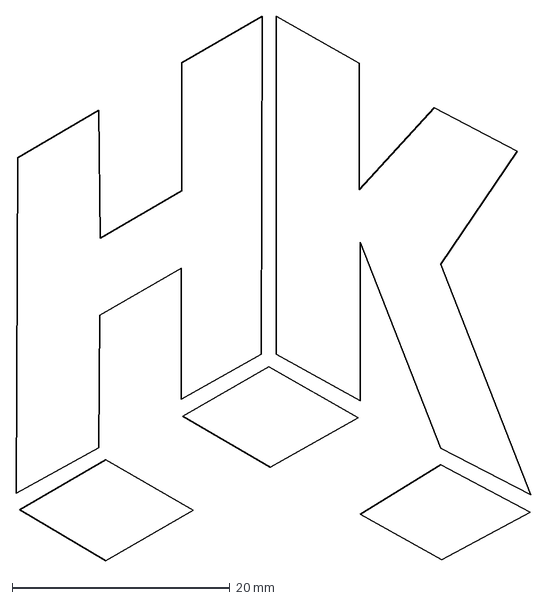
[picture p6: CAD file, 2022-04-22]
dxf/hk_50mm.dxf
47.3 x 50.0 mm

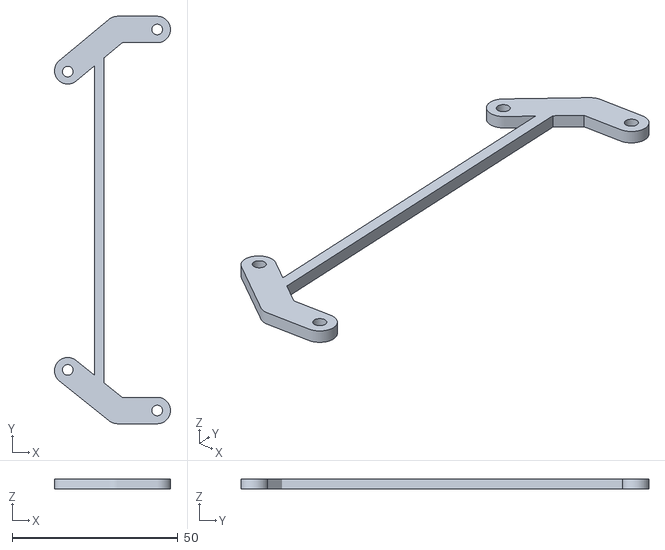
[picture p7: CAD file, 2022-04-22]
stl/Vu7_Speaker_Bracket_Left.stl
35.0 x 123.0 x 3.00

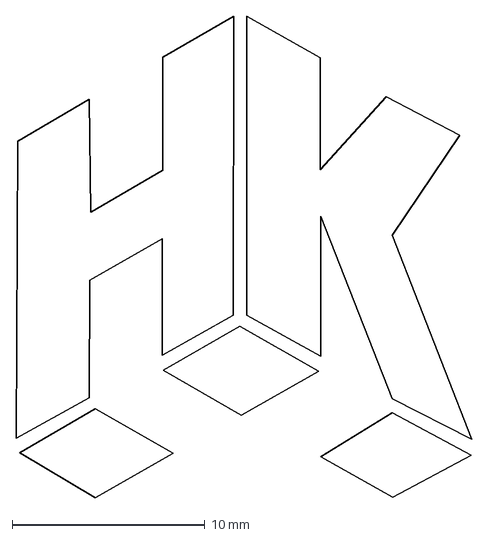
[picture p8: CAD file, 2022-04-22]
dxf/hk_25mm.dxf
23.7 x 25.0 mm

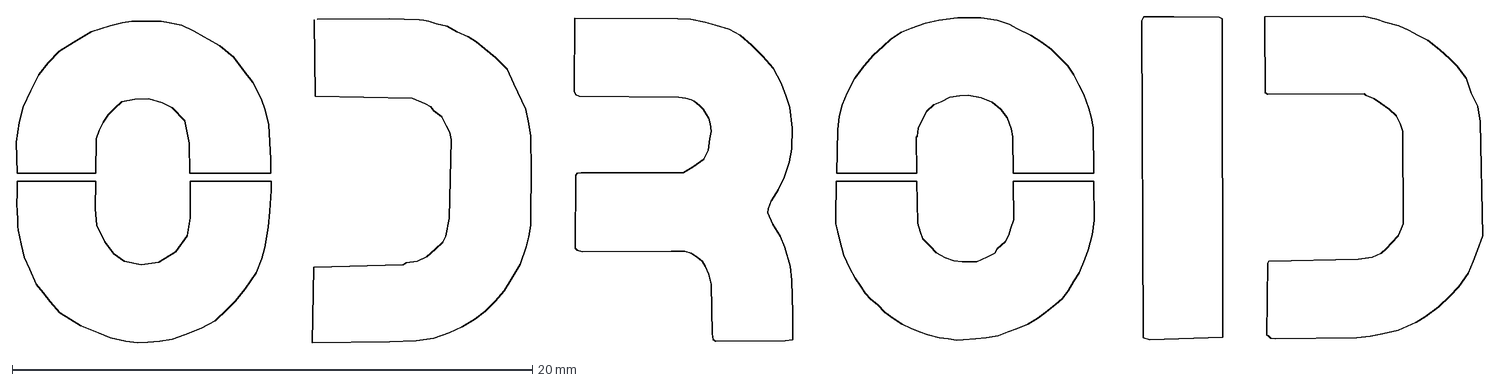
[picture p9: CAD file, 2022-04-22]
dxf/customart.dxf
56.4 x 12.6 mm

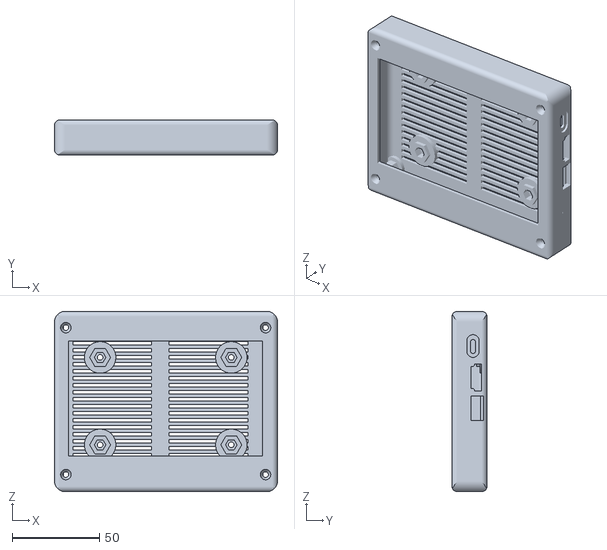
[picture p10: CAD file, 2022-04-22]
stl/Vu5_Case.stl
127.5 x 20.0 x 103.1

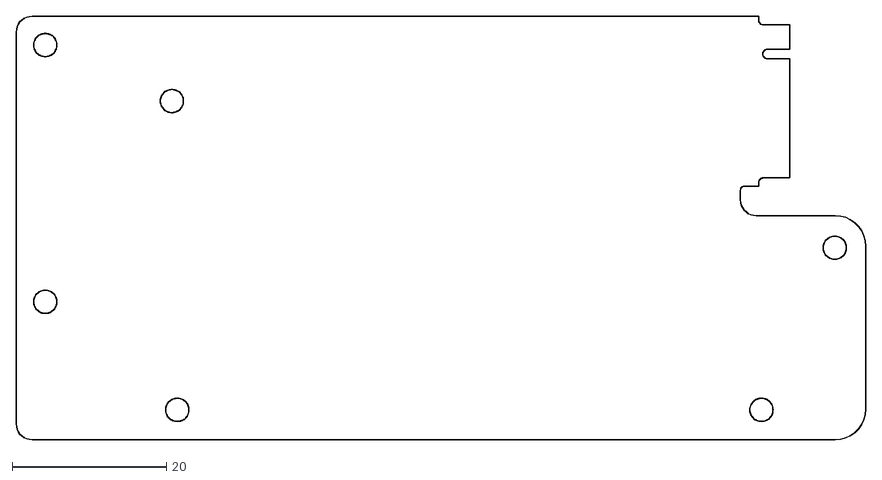
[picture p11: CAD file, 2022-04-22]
dxf/hk-network-card.dxf
110.0 x 54.8

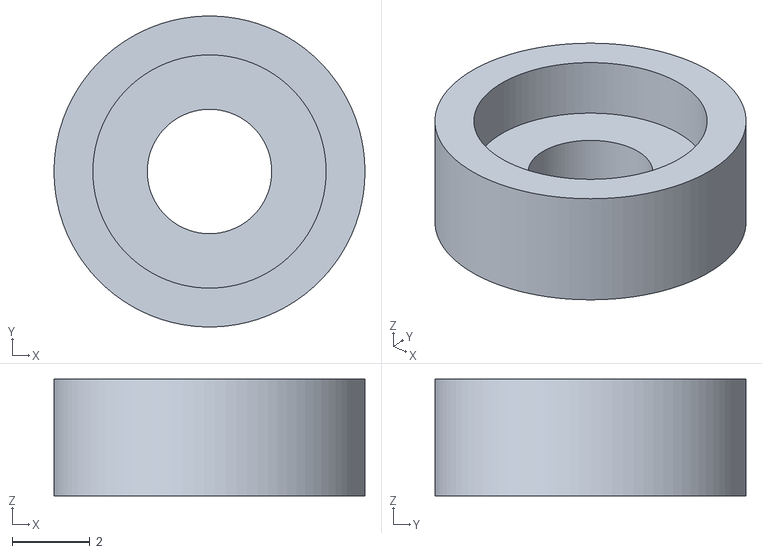
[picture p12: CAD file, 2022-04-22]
stl/Vu_Speaker_Bracket_Washer.stl
8.00 x 8.00 x 3.00

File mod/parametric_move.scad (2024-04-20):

/*
    This file is part of SBC Case Builder https://github.com/hominoids/SBC_Case_Builder
    Copyright 2022,2023,2024 Edward A. Kisiel hominoid@cablemi.com

    This program is free software: you can redistribute it and/or modify
    it under the terms of the GNU General Public License as published by
    the Free Software Foundation, either version 3 of the License, or
    (at your option) any later version.

    but WITHOUT ANY WARRANTY; without even the implied warranty of
    MERCHANTABILITY or FITNESS FOR A PARTICULAR PURPOSE.  See the
    GNU General Public License for more details.

    You should have received a copy of the GNU General Public License
    along with this program.  If not, see <http://www.gnu.org/licenses/>
    Code released under GPLv3: http://www.gnu.org/licenses/gpl.html


           NAME: parametric_move_add
    DESCRIPTION: places parametric additive objects 
           TODO: none

          USAGE: parametric_move_add(type, loc_x, loc_y, loc_z, face, rotation, parametric[], size[], data[], mask[])

                         type = component type
                        loc_x = x location placement
                        loc_y = y location placement
                        loc_z = z location placement
                         face = "top", "bottom", "left", "right", "front", "rear"
                   rotation[] = object rotation
                 parametric[] = parametric movement array
                       size[] = size array x,y,z
                       data[] = data filed
                      mask[0] = true enables component mask
                      mask[1] = mask length
                      mask[2] = mask setback
                      mask[3] = mstyle "default"

*/

module parametric_move_add(type, loc_x, loc_y, loc_z, face, rotation, parametric, size, data, mask) {
    
    // absolute no parametrics
    if(parametric[1] == false && parametric[2] == false && parametric[3] == false) {        
        add(type, loc_x, loc_y, loc_z, face, rotation, size, data, mask);
    }
    // x axis accessory parametrics
    if(parametric[1] == true && parametric[2] == false && parametric[3] == false) {
        if(parametric[0] == "case") {
            add(type, loc_x+case_offset_x, loc_y, loc_z, face, rotation, size, data, mask);
        }
        if(parametric[0] == "sbc") {
            add(type, loc_x+pcb_loc_x, loc_y, loc_z, face, rotation, size, data, mask);
        }
    }
    // y axis accessory parametrics
    if(parametric[1] == false && parametric[2] == true && parametric[3] == false) {
        if(parametric[0] == "case") {
            add(type, loc_x, loc_y+case_offset_y, loc_z, face, rotation, size, data, mask);
        }
        if(parametric[0] == "sbc") {
            add(type, loc_x, loc_y+pcb_loc_y, loc_z, face, rotation, size, data, mask);
        }
    }
    // z axis accessory parametrics
    if(parametric[1] == false && parametric[2] == false && parametric[3] == true) {
        if(parametric[0] == "case" && face == "top") {
            add(type, loc_x, loc_y, loc_z+case_offset_tz+case_offset_bz, face, rotation, size, data, mask);
        }
        if(parametric[0] == "case" && face == "bottom") {
            add(type, loc_x, loc_y, loc_z+case_offset_bz, face, rotation, size, data, mask);
        }
        if(parametric[0] == "case" && face != "bottom" && face != "top") {
            add(type, loc_x, loc_y, loc_z, face, rotation, size, data, mask);
        }
        if(parametric[0] == "sbc") {
            add(type, loc_x, loc_y, loc_z+pcb_loc_z+case_offset_bz, face, rotation, size, data, mask);
        }
        if(parametric[0] == "sbc-case_z" && face == "top") {
            add(type, loc_x, loc_y, loc_z+case_offset_tz+case_offset_bz, face, rotation, size, data, mask);
        }
        if(parametric[0] == "sbc-case_z" && face == "bottom") {
            add(type, loc_x, loc_y, loc_z+case_offset_bz, face, rotation, size, data, mask);
        }
    }
    // xy axis accessory parametrics
    if(parametric[1] == true && parametric[2] == true && parametric[3] == false) {
        if(parametric[0] == "case") {
            add(type, loc_x+case_offset_x, loc_y+case_offset_y, loc_z, face, rotation, size, data, mask);
        }
        if(parametric[0] == "sbc") {
            add(type, loc_x+pcb_loc_x, loc_y+pcb_loc_y, loc_z, face, rotation, size, data, mask);
        }
    }
    // xz axis accessory parametrics
    if(parametric[1] == true && parametric[2] == false && parametric[3] == true) {
        if(parametric[0] == "case" && face == "top") {
            add(type, loc_x+case_offset_x, loc_y, loc_z+case_offset_tz+case_offset_bz, face, rotation, size, data, mask);
        }
        if(parametric[0] == "case" && face == "bottom") {
            add(type, loc_x+case_offset_x, loc_y, loc_z+case_offset_bz, face, rotation, size, data, mask);
        }
        if(parametric[0] == "case" && face != "bottom" && face != "top") {
            add(type, loc_x+case_offset_x, loc_y, loc_z, face, rotation, size, data, mask);
        }
        if(parametric[0] == "sbc") {
            add(type, loc_x+pcb_loc_x, loc_y, loc_z+pcb_loc_z+case_offset_bz, face, rotation, size, data, mask);
        }
        if(parametric[0] == "sbc-case_z" && face == "top") {
            add(type, loc_x+pcb_loc_x, loc_y, loc_z+case_offset_tz+case_offset_bz, face, rotation, size, data, mask);
        }
        if(parametric[0] == "sbc-case_z" && face == "bottom") {
            add(type, loc_x+pcb_loc_x, loc_y, loc_z+case_offset_bz, face, rotation, size, data, mask);
        }
    }
    // yz axis accessory parametrics
    if(parametric[1] == false && parametric[2] == true && parametric[3] == true) {
        if(parametric[0] == "case" && face == "top") {
            add(type, loc_x, loc_y+case_offset_y, loc_z+case_offset_tz+case_offset_bz, face, rotation, size, data, mask);
        }
        if(parametric[0] == "case" && face == "bottom") {
            add(type, loc_x, loc_y+case_offset_y, loc_z+case_offset_bz, face, rotation, size, data, mask);
        }
        if(parametric[0] == "case" && face != "bottom" && face != "top") {
            add(type, loc_x, loc_y+case_offset_y, loc_z, face, rotation, size, data, mask);
        }
        if(parametric[0] == "sbc") {
            add(type, loc_x, loc_y+pcb_loc_y, loc_z+pcb_loc_z+case_offset_bz, face, rotation, size, data, mask);
        }
        if(parametric[0] == "sbc-case_z" && face == "top") {
            add(type, loc_x,loc_y+pcb_loc_y, loc_z+case_offset_tz+case_offset_bz, face, rotation, size, data, mask);
        }
        if(parametric[0] == "sbc-case_z" && face == "bottom") {
            add(type, loc_x, loc_y+pcb_loc_y, loc_z+case_offset_bz, face, rotation, size, data, mask);
        }
    }
    // xyz axis accessory parametrics
    if(parametric[1] == true && parametric[2] == true && parametric[3] == true) {
        if(parametric[0] == "case" && face == "top") {
            add(type, loc_x+case_offset_x, loc_y+case_offset_y, loc_z+case_offset_tz+case_offset_bz, face, rotation, size, data, mask);
        }
        if(parametric[0] == "case" && face == "bottom") {
            add(type, loc_x+case_offset_x, loc_y+case_offset_y, loc_z+case_offset_bz, face, rotation, size, data, mask);
        }
        if(parametric[0] == "case" && face != "bottom" && face != "top") {
            add(type, loc_x+case_offset_x, loc_y+case_offset_y, loc_z, face, rotation, size, data, mask);
        }
        if(parametric[0] == "sbc") {
            add(type, loc_x+pcb_loc_x, loc_y+pcb_loc_y, loc_z+pcb_loc_z+case_offset_bz, face, rotation, size, data, mask);
        }
        if(parametric[0] == "sbc-case_z" && face == "top") {
            add(type, loc_x+pcb_loc_x, loc_y+pcb_loc_y, loc_z+case_offset_tz+case_offset_bz, face, rotation, size, data, mask);
        }
        if(parametric[0] == "sbc-case_z" && face == "bottom") {
            add(type, loc_x+pcb_loc_x, loc_y+pcb_loc_y, loc_z+case_offset_bz, face, rotation, size, data, mask);
        }
    }
}


/*
           NAME: parametric_move_sub
    DESCRIPTION: places parametric subtractive objects 
           TODO: none

          USAGE: parametric_move_sub(type, loc_x, loc_y, loc_z, face, rotation, parametric[], size[], data[], mask[])

                         type = component type
                        loc_x = x location placement
                        loc_y = y location placement
                        loc_z = z location placement
                         face = "top", "bottom", "left", "right", "front", "rear"
                   rotation[] = object rotation
                 parametric[] = parametric movement array
                       size[] = size array x,y,z
                      mask[0] = true enables component mask
                      mask[1] = mask length
                      mask[2] = mask setback
                      mask[3] = mstyle "default"

*/
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

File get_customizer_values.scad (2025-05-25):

/* Gets a list of SBCs from the SBC Model Framework and Accessory sets
   for use with SBC Case Builder.
   After running this script, copy the output from the first Echo command into the
   list of SBC boards in `sbc_case_builder.scad:32` and `sbc_case_builder.scad` 
   6 locations line 82,90,98,106,114,122 for the sbc selection for the rack case design.
   Also copy the output from the second Echo command into the list of case acceessory
   sets in `sbc_case_builder.scad:196`
*/
include <./SBC_Model_Framework/sbc_models.cfg>;
include <./sbc_case_builder_accessories.cfg>;
echo(" ");
boards = [for(i=[0:1:len(sbc_data)-1]) sbc_data[i][0]];
echo("Copy the following to `sbc_case_builder.scad` for the `sbc_model` variable");
echo(boards);
echo(" ");
accessory_sets = [for(i=[0:1:len(accessory_data)-1]) accessory_data[i][0]];
echo("Copy the following to `sbc_case_builder.scad` for the `accessory_name` variable");
echo(accessory_sets);
echo(" ");

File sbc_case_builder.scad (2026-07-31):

/*
    SBC Case Builder Copyright 2022-2026 Edward A. Kisiel hominoid@cablemi.com

    This program is free software: you can redistribute it and/or modify
    it under the terms of the GNU General Public License as published by
    the Free Software Foundation, either version 3 of the License, or
    (at your option) any later version.

    but WITHOUT ANY WARRANTY; without even the implied warranty of
    MERCHANTABILITY or FITNESS FOR A PARTICULAR PURPOSE.  See the
    GNU General Public License for more details.

    You should have received a copy of the GNU General Public License
    along with this program.  If not, see <http://www.gnu.org/licenses/>.
    Code released under GPLv3: http://www.gnu.org/licenses/gpl.html

    20220202 Version 1.0.0    sbc case builder using sbc model framework.
    
    see https://github.com/hominoids/SBC_Case_Builder
*/

use <./SBC_Model_Framework/sbc_models.scad>;
include <./sbc_case_builder_library.scad>;
include <./SBC_Model_Framework/sbc_models.cfg>;
include <./sbc_case_builder_accessories.cfg>;

/* [View] */
// viewing mode "model", "platter", "part"
view = "model"; // [model, platter, part]
individual_part = "bottom"; // [top, bottom, right, left, front, rear, io_shield, accessories]
// section individual parts for panel cases
section_part = false; // [true,false]
// single board computer model
sbc_model = "c1+"; //  ["c1+", "c2", "c4", "hc4", "c5", "xu4", "xu4q", "mc1", "hc1", "n1", "n2", "n2+", "n2l", "n2lq", "m1", "m1s", "m2", "h2", "h2+", "h3", "h3+", "h4", "h4+", "h4_ultra", "h5", "show2", "rpipico", "rpipicow", "rpicm4+ioboard", "rpicm5+ioboard", "rpicm1", "rpicm3", "rpicm3l", "rpicm3+", "rpicm4s", "rpicm4", "rpicm4l", "rpicm5", "rpizero", "rpizerow", "rpizero2w", "rpi1a+", "rpi1b+", "rpi2b", "rpi3a+", "rpi3b", "rpi3b+", "rpi4b", "rpi5", "a64", "a64lts", "rock64", "rockpro64", "quartz64a", "quartz64b", "h64b", "star64", "soedge_a-baseboard", "soedge_rk1808", "rock4a", "rock4b", "rock4a+", "rock4b+", "rock4c", "rock4c+", "rock5b-v1.3", "rock5b", "rock5bq", "rock5b+", "nio12l", "vim1", "vim2", "vim3", "vim3l", "vim4", "tinkerboard", "tinkerboard-s", "tinkerboard-2", "tinkerboard-2s", "tinkerboard-r2", "tinkerboard-r2s", "opizero", "opizero2", "opir1plus_lts", "opir1", "opi3b-v2.1", "opi5", "opi5max", "jetsonnano", "lepotato", "sweetpotato", "tritium-h2+", "tritium-h3", "tritium-h5", "solitude", "alta", "atomicpi", "visionfive2", "visionfive2q", "bpif3", "milk-v_duos", "licheerv+dock", "rak19007", "cnano-avr128da48", "nodemcu-32s", "cs-solarmeter", "feather-m0_express", "feather-m0_wifi", "feather-m4_express", "ssi-eeb", "ssi-ceb", "atx", "micro-atx", "dtx", "flex-atx", "mini-dtx", "ebx", "mini-itx", "mini-itx_thin", "mini-stx", "mini-stx_thin", "nano-itx", "nuc", "pico-itx"]

// sbc off in model view
sbc_off = false;
// sbc information display
sbc_information = false;
// enable highlight for sbc component subtractive geometry
sbc_highlight = false;
// enable highlight for accessory subtractive geometry
accessory_highlight = false;
// base case design
case_design = "shell"; // [shell,panel,panel_nas,stacked,tray,tray_sides,tray_vu5,tray_vu7,round,hex,snap,fitted,rack,paper_split-top,paper_full-top,adapter_ssi-eeb,adapter_ssi-ceb,adapter_atx,adapter_micro-atx,adapter_dtx,adapter_flex-atx,adapter_mini-dtx,adapter_ebx,adapter_mini-itx,adapter_mini-itx_thin,adapter_mini-stx,adapter_mini-stx_thin]

// raises top mm in model view or < 0 = off
raise_top = 0; // [-1:100]
// lowers bottom mm in model view or < 0 = off
lower_bottom = 0; // [-1:100]
// move left side mm in model view or < 0 = off
move_leftside = 0; // [-1:100]
// move right side mm in model view or < 0 = off
move_rightside = 0; // [-1:100]
// move front mm in model view or < 0 = off
move_front = 0; // [-1:100]
// move rear mm in model view or < 0 = off
move_rear = 0; // [-1:100]

/* [3D Case Adjustments] */
// sbc location x axis
pcb_loc_x = 0; //[0:.01:300]
// sbc location y axis
pcb_loc_y = 0; //[0:.01:300]
// sbc location z axis
pcb_loc_z = 0; //[0:.01:100]
// additional x axis case size
case_offset_x = 0; //[0:.01:300]
// additional y axis case size
case_offset_y = 0; //[0:.01:300]
// additional z axis case top size
case_offset_tz = 0; //[-50:.01:300]
// additional z axis case bottom size
case_offset_bz = 0; //[-50:.01:300]
// case wall thickness
wallthick = 2; //[1:.25:5]
// case floor and ceiling thickness
floorthick = 2; //[1:.25:5]
// side wall thickness for tray_side and panel_nas cases only
sidethick = 2; //[1:.25:5]
// distance between pcb and case
gap = 1; //[.5:.25:5]
// corner fillets
corner_fillet = 3; //[0:.5:9]
// edge fillets
edge_fillet = 0; //[0:.5:6]
// tolerance for fitted surfaces
tol = .25; //[-.5:.0625:.5]

/* [    Folded Case Adjustments] */
// material thickness in mm
material_thickness = .5; //[.1:.01:3]
// bend allowance
bend_allowance = 1; //[0:.01:5]
// bottom clearence
bottom_clearence = 3.5; //[-10:.01:10]
// enable flat blank section for export
flat_blank_section =  false;

/* [    Standard Motherboard Case Adjustments] */
// adjustment for ssi-eeb, ssi-ceb, atx, micro-atx, dtx, flex-atx, mini-dtx, mini-itx, mini-stx, nano-itx,nuc, pico-itx PCB thickness from 2mm default//
standard_motherboard_thickness =  0; //[-3:.01:3]
// rear io plate opening for standard form motherboards
rear_io_shield = false;
// sbc rotation on the adapter
adapter_sbc_rotation = 0; //[0:90:270]

/* [    Rack Mount Case Adjustments] */
// size of rack 10" or 19" //
rack_width =  19; //[10,19]
// size of rack mount cases 1U or 2U //
rack_size =  "1u"; //["1u","1u+","1u++","2u"]
removable_bay_height = 0; // [-4 : .5 : 0]
// bay sbc device
Rack_Bay1 = "none"; //  ["none", "c1+", "c2", "c4", "hc4", "c5", "xu4", "xu4q", "mc1", "hc1", "n1", "n2", "n2+", "n2l", "n2lq", "m1", "m1s", "m2", "h2", "h2+", "h3", "h3+", "h4", "h4+", "h4_ultra", "h5", "show2", "rpipico", "rpipicow", "rpicm4+ioboard", "rpicm5+ioboard", "rpicm1", "rpicm3", "rpicm3l", "rpicm3+", "rpicm4s", "rpicm4", "rpicm4l", "rpicm5", "rpizero", "rpizerow", "rpizero2w", "rpi1a+", "rpi1b+", "rpi2b", "rpi3a+", "rpi3b", "rpi3b+", "rpi4b", "rpi5", "a64", "a64lts", "rock64", "rockpro64", "quartz64a", "quartz64b", "h64b", "star64", "soedge_a-baseboard", "soedge_rk1808", "rock4a", "rock4b", "rock4a+", "rock4b+", "rock4c", "rock4c+", "rock5b-v1.3", "rock5b", "rock5bq", "rock5b+", "nio12l", "vim1", "vim2", "vim3", "vim3l", "vim4", "tinkerboard", "tinkerboard-s", "tinkerboard-2", "tinkerboard-2s", "tinkerboard-r2", "tinkerboard-r2s", "opizero", "opizero2", "opir1plus_lts", "opir1", "opi5", "opi5max", "opi3b-v2.1", "jetsonnano", "lepotato", "sweetpotato", "tritium-h2+", "tritium-h3", "tritium-h5", "solitude", "alta", "atomicpi", "visionfive2", "visionfive2q", "bpif3", "milk-v_duos", "licheerv+dock", "rak19007", "cnano-avr128da48", "nodemcu-32s", "cs-solarmeter", "feather-m0_express", "feather-m0_wifi", "feather-m4_express"]
rack_bay1_xyz_loc = [0,0,0]; // [0:.5:450]
rack_bay1_rotation = 0; // [0:90:270]
rack_bay1_face = "fixed"; // ["open","fixed","removable","vent"]
rack_bay1_wall = false; // [true,false]
rack_bay1_rear_fan = false; // [true,false]
rack_bay1_rear_conduit = "none"; // ["none","conduit","grommet","grommets-vertical"]

Rack_Bay2 = "none"; //  ["none", "c1+", "c2", "c4", "hc4", "c5", "xu4", "xu4q", "mc1", "hc1", "n1", "n2", "n2+", "n2l", "n2lq", "m1", "m1s", "m2", "h2", "h2+", "h3", "h3+", "h4", "h4+", "h4_ultra", "h5", "show2", "rpipico", "rpipicow", "rpicm4+ioboard", "rpicm5+ioboard", "rpicm1", "rpicm3", "rpicm3l", "rpicm3+", "rpicm4s", "rpicm4", "rpicm4l", "rpicm5", "rpizero", "rpizerow", "rpizero2w", "rpi1a+", "rpi1b+", "rpi2b", "rpi3a+", "rpi3b", "rpi3b+", "rpi4b", "rpi5", "a64", "a64lts", "rock64", "rockpro64", "quartz64a", "quartz64b", "h64b", "star64", "soedge_a-baseboard", "soedge_rk1808", "rock4a", "rock4b", "rock4a+", "rock4b+", "rock4c", "rock4c+", "rock5b-v1.3", "rock5b", "rock5bq", "rock5b+", "nio12l", "vim1", "vim2", "vim3", "vim3l", "vim4", "tinkerboard", "tinkerboard-s", "tinkerboard-2", "tinkerboard-2s", "tinkerboard-r2", "tinkerboard-r2s", "opizero", "opizero2", "opir1plus_lts", "opir1", "opi5", "opi5max", "opi3b-v2.1", "jetsonnano", "lepotato", "sweetpotato", "tritium-h2+", "tritium-h3", "tritium-h5", "solitude", "alta", "atomicpi", "visionfive2", "visionfive2q", "bpif3", "milk-v_duos", "licheerv+dock", "rak19007", "cnano-avr128da48", "nodemcu-32s", "cs-solarmeter", "feather-m0_express", "feather-m0_wifi", "feather-m4_express"]
rack_bay2_xyz_loc = [0,0,0]; // [0:.5:450]
rack_bay2_rotation = 0; // [0:90:270]
rack_bay2_face = "fixed"; //["open","fixed","removable","vent"]
rack_bay2_wall = false; // [true,false]
rack_bay2_rear_fan = false; //[true,false]
rack_bay2_rear_conduit =  "none"; //["none","conduit","grommet","grommets-vertical"]
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

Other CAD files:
stl/Vu5_Speaker_Bracket_Left.stl
sbc_case_builder_library.scad
mod/add.scad
mod/case_adapter.scad
mod/case_bottom.scad
mod/case_folded.scad
mod/case_rack.scad
mod/case_side.scad
mod/case_top.scad
mod/fillets.scad
mod/indent.scad
mod/place.scad
mod/sub.scad
sbccb_accessory_tool.scad

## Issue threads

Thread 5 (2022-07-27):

Cleanup Case Builder Config

davejlong, 2022-07-27:
It seems like there's a number of elements of the Case Builder config file that aren't used or are potentially the wrong data type. I figured I'd create a list of them to make sure they aren't there for some future plan before submitting a PR to remove or change them:

* Remove standoff height (second element in all 4 of the standoff lists)
* Standoff reverse should be boolean (it seems like the checks are always boolean checks)
* Standoff insert enable should be a boolean

hominoids, 2022-07-27:
The standoff reverse and standoff insert can be boolean but keep the standoff height for now.  It doesn't need to be in the customizer but keep it in the case schema(sbc_case_builder.cfg).  I have been working on decoupling the standoff height so it's not a calculation, in order to provide additional case flexibility.  On one hand keeping it as a calculation removes the user from having to figure it out and possibly make a mistake, but it also doesn't allow some case configurations.  I may be able to do the case config's with variable standoff height in the code base, and if so, it can be taken out later

davejlong, 2022-07-29:
What if, instead of a standoff height, it's a modification to the calculated standoff? For example, if you want to add additional buffer space, perhaps to make room for a fan, you would just set the height to be the fan's size, and that value is added to the calculation?

hominoids, 2022-07-30:
Extra z-axis is achieved by case_offset_bz already.  I think we will be going in the direction chosen by the decisions made regarding the customizer, see issue#7.

Closed 2022-07-30.

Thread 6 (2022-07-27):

Alternative to setting standoff hole parameters

davejlong, 2022-07-27:
Instead of having to specific numeric values for standoff holes, would it make more sense to instead just enter the type of screw used and build the holes off of that? For example, the standard screw for PCB holes is M2.5, so the bottom standoff hole should be 2.5mm. If setting a nut holder type hole, the nut for an M2.5 screw is 4.9mm, so the hole should be ~5mm.

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

hominoids, 2022-07-27:
That sounds good on the surface but I'm concerned that it might create limitations with so many diverse users.  For instance, tapping holes as one example.  The size of the hole does vary based on the strength and shrinkage of the material one might use.  Same thing with nuts to be inserted.  I sometimes reduce the opening and hot insert them when they need to stay in place.  This change would make it easier for some but also less flexible for others.   I like the thought behind the suggestion but not sure of all the consequences.  I think we should hold off for now which would give more time to think about all the possible ramifications.

hominoids, 2022-09-12:
Not implemented for now.

Closed 2022-09-12.

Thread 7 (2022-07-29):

Improve support for customizer

davejlong, 2022-07-29:
Moving thread from https://github.com/hominoids/SBC_Case_Builder/pull/4

Goal of this is to improve the ease of entry for someone who wants to build a case without being familiar with OpenSCAD or needing to figure out the syntax in `sbc_case_builder.cfg`. Make all of the variables populated from `sbc_case_builder.cfg` set by the Customizer. Customizer configurations can be saved as JSON files.

In theory this would also allow for someone to use the [Thingiverse Customizer](https://www.thingiverse.com/app:22) to get a case without having to download the SCAD files at all.

Current hangup is how to handle the accessory settings.

hominoids, 2022-07-30:
After doing a deeper dive into the latest features of the customizer I don’t believe a fully integrated solution using the json format is going to possible.  We need to be able to search the accessories and  search() doesn't appear to work with that format. It only works on vectors and lists of vectors.  The json entries are also sorted alphabetically which rules out any fixed reference scheme.  I did have a idea for a solution but it is a hybrid with a philosophical change.

The current approach has been to treat a complete case as one entry.  By decoupling the accessories from the case, the customizer can be used to create and store the case information.  The current sbc_case_builder.cfg would still be used for the accessory entries in the current format.  Still looking for other ways but I did put some time into the fore mentioned possible approach for discussion.   Take a look at the case_design branch I just posted and let me know what you think.  Didn't remove the case data yet from sbc_case_builder.cfg but it's not used.

hominoids, 2022-08-14:
The customizer has been implemented using it's current capabilities.

Closed 2022-08-14.

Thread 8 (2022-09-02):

Case accessories break when changing offsets

davejlong, 2022-09-02:
When changing the offset, for example case_offset_tz, case accessories break. For example, when applying a fan cutout to a case, if I change the case_offset_tz to something like 15, the cutout is moved away from the case. Issue only seems to be with accessories from `sbc_case_builder_accessories.cfg`. Using the customizer dropdowns for colling, gpio openings and vents works as expected.

A solution that seems relatively logical on the surface is to remove the loc_z value from the accessories schema. Alternatively, maybe make `loc_x`, `loc_y`, and `loc_z` relative based on the case?

hominoids, 2022-09-03:
The accessories were intentionally implemented as absolute coordinates without any implied relationship to the case or SBC.  When this originally came up I had just started implementing accessories and didn’t have a good understanding of the nuances of implementing parametric positioning for them at the time.  The decision was made to use absolute positioning for accessories and to associate any SBC component opening or features(GPIO, heatsink, UART, etc) directly to the responsible SBC component contained in sbc_model_framework.cfg.  So the feature openings for GPIO and cooling in sbc case builder are created when there is a GPIO header component and/or a heatsink for the given SBC and uses their positions.  That’s why there is an accessory set for any SBC that has no OEM heatsink, to provide the type and location for a fan/vent opening.  Likewise, if a SBC doesn’t have a GPIO header, the opening doesn’t appear for the same reason even if they are enabled.  It also can be added as an dissociated absolute accessory if needed.

All that said, I think parametric positioning of accessories is achievable.  Your solution covers one possible scenario but I believe there are at least three situations(absolute, SBC associated and case associated positioning) that need to be implemented to address parametric accessories adequately.  In your example the fan position needs to be parametric to the SBC so when the SBC is moved the fan opening is moved, SBC associated parametric positioning.  For other accessories case associated parametric positioning will be needed; consider a UART and opening at each face of a case.  What axis to use for case parametric adjustments is not intuitive or uniform across the faces.  Since the users intent is not implied or known the affected axis(s) must be given.

I have been working towards the release of version 2.0 but I’ll take a look at whether I can get this done in a timely manner to include in version 2.0 since it will require a schema change for the accessories.

davejlong, 2022-09-07:
What if the user selects to add a fan openeing, in a case where the board doesn't have an OEM heatsink, to just create a fan opening either centered on the board or centered over SOC1?

hominoids, 2022-09-07:
That can be done now with an accessory but if you mean automated there is at least one issue, I don’t know if there is a heatsink or not for any given SBC.  Right now the algorithm works on SBC components that are in the list.  Knowing what is not there requires a different approach, the SBC components would need to be parsed ahead of time and flags set and checked.  I have thought about developing this for other reasons, but not good enough ones as of yet.  Another approach would be using the SOC for all cooling openings, instead of the heatsink.  One issue with this approach is that SOC data is not always available.  Some OEM don’t provide that Mechanical information.  If you look at the SBC added recently in SBC Model Framework, some have comments that the SOC data is missing.  This doesn’t stop a case from being made right now but it isn’t and shouldn’t be relied on either.  As the SOC data matures it might make more sense to look at the SOC approach to locate cooling in the future.  I have some other cooling options I would like to add that need the SOC data.  Regardless of the approach, this will be achievable using an accessory(fan opening) associated to the SBC, centered as needed.

hominoids, 2022-09-12:
The first attempt at accessory associative parametric positioning is done.

hominoids, 2022-09-12:
The first attempt at accessory associative parametric positioning is done.

Closed 2022-09-12.

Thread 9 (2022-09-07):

Feature Request: Support for different height standoffs

davejlong, 2022-09-07:
I use the [GeeekPi PoE Hat](https://smile.amazon.com/dp/B08CVDQWXF) for my Raspberry Pis which attaches to the pi at 3 points using standoffs. This means that creating a case for it, I need 3 of the standoffs to be short to screw into the PoE Hat and 1 standoff to be longer to reach down to the Pi. Right now this isn't possible. I think it would be suitably easy to add an option to provide an offset for each standoff.

hominoids, 2022-09-07:
I agree and this aligns with the broader issue of add on PCBs that I have been mulling over.

hominoids, 2022-09-12:
This is now complete.

Closed 2022-09-12.

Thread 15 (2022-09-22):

Feature Request: Easier view of how components fit together

davejlong, 2022-09-22:
In developing accessory layouts it can be difficult to determine if there's enough spacing for things. For example, putting a fan into a case. It's hard to tell if there's actually enough room between the case and the board for a fan. The best way I've found to do it, is to render the Model view to STL, load it into SuperSlicer, slice the model and move through layers to see how things look.

Perhaps we could make it so that when looking at the model view, accessories like fans, speakers, etc. would render the actual shape. Then when I render the case in Model view, and look at the Wireframe view in OpenSCAD, it would be easy to see any overlap between the accessory and the SBC.

Perhaps we could even just use the [NopSCAD](https://github.com/nophead/NopSCADlib) library for generating the objects.

hominoids, 2022-09-23:
If I understand what your requesting, to view accessory models in model view, it can be done already but there is not a fan model yet.  Take a look at the hc4 or h2 accessory entries for examples of model accessories as part of the model view.

I have used [cutaway views](https://forum.odroid.com/viewtopic.php?f=53&t=43948&start=19) (see h2 button cutaway) for fit issues and there may be a way to add them to the VIEW tab for cases of limited pieces, supplementing the move functions.  So for instance, since the shell case only has a top and bottom to move, use a cutaway on demand to see into the rear, front or sides without moving either the top or the bottom.

Accessory models will continue to be added in the future.  Doing the major OEM accessories for the supported SBC is one long term goal.  The NopSCAD library is nice and I considered using it but it focuses on 3d printer design.  The fans are about the only thing relevant for SBC so I think just adding fan models to the existing library is the way to go for now.   Having accessory models for locating and checking can be important in some situations, which is why I suggested doing one of the GeeekPOE hat.

hominoids, 2022-09-25:
This is now complete.  In the view tab, cutaway view can be enabled by changing the case face, that is not movable, to -1.

Closed 2022-09-25.

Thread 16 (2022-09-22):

Case indents not working

davejlong, 2022-09-22:
Case indents for IO openings doesn't seem to be working.

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

Customizer values are:

```
        "test_indents": {
            "$fn": "90",
            "accessory_highlight": "false",
            "accessory_name": "rpi4b_shell",
            "adjust": "0.01",
            "bottom_ext_standoff": "[6.75, 5, 3.6, 10, 4, 1, 0, 0, 0, 4.5, 5.1]",
            "bottom_front_left": "0",
            "bottom_front_right": "0",
            "bottom_rear_left": "0",
            "bottom_rear_right": "0",
            "bottom_standoff": "[6.75, 7, 3.6, 10, 4, 1, 0, 0, 0, 4.5, 5.1]",
            "c_fillet": "3",
            "case_design": "shell",
            "case_ext_standoffs": "false",
            "case_ffn": "90",
            "case_fn": "360",
            "case_offset_bz": "0",
            "case_offset_tz": "0",
            "case_offset_x": "0",
            "case_offset_y": "0",
            "case_style": "none",
            "cooling": "fan",
            "exhaust_vents": "vent",
            "fillet": "3",
            "floorthick": "2",
            "gap": "1",
            "gpio_opening": "none",
            "indents": "true",
            "lip": "5",
            "lower_bottom": "0",
            "move_front": "0",
            "move_leftside": "0",
            "move_rear": "0",
            "move_rightside": "0",
            "pcb_loc_x": "0",
            "pcb_loc_y": "0",
            "pcb_loc_z": "0",
            "raise_top": "0",
            "sata_punchout": "false",
            "sbc_bottom_standoffs": "true",
            "sbc_highlight": "false",
            "sbc_model": "rpi4b",
            "sbc_off": "false",
            "sbc_top_standoffs": "true",
            "sidethick": "2",
            "sidewall_support": "true",
            "tol": "0.25",
            "top_ext_standoff": "[6.75, 18, 2.5, 10, 4, 4, 0, 1, 0, 4.5, 5.1]",
            "top_front_left": "0",
            "top_front_right": "0",
            "top_rear_left": "0",
            "top_rear_right": "0",
            "top_standoff": "[6.75, 18, 2.5, 10, 4, 4, 0, 1, 0, 4.5, 5.1]",
            "view": "model",
            "vu_rotation": "[15, 0, 0]",
            "wallthick": "2"
        }
```

davejlong, 2022-09-22:
It looks to be a limitation of the indents logic. I found that indents only work for:

* Micro USB
* HDMI A
* Power

Perhaps there's a better way to generate the indents based on the shape in SBC_Model_Framework instead of creating new shapes in the case builder.

hominoids, 2022-09-23:
Your correct, I have only implemented a small number of components and orientations.  It is the last item on my issue list currently and will be addressed in the future.  I'm not planning to implement indents for every component, just some specific ones make sense, but in all orientations.

davejlong, 2022-09-23:
Can you offer some insight into the math behind building them? I wanted to add them for a few basics that I think follow the same logic you already have: USB-C, Micro HDMI and 3.5mm Audio Jack (all on the RPi4B).

Looking at adding them, using the `slot(hole,length,depth)` module, it seems like there might be a slight problem with the logic. In the [SBC_Model_Framework's USB-C](https://github.com/hominoids/SBC_Model_Framework/blob/main/sbc_library.scad#L687), the hull properly takes into account that cylinders are centered, whereas [`slot`](https://github.com/hominoids/SBC_Case_Builder/blob/main/sbc_case_builder_library.scad#L393) doesn't, so the size of the slot will actually be larger than specified in the length parameter. Not sure if this was by design or not.

hominoids, 2022-09-23:
Both approaches are correct but differ on their goal.  For slot() total length = _length_ + _hole diameter_.  That allows a rectangular object who's width is equal to _length_ to be but in the slot.  The other example, total length = _length_ - _hole diameter_, so the width is slot _length_ only, a rectangular object of width _length_ would not fit in the slot.

What shape and size indent to use is driven by the type of cable connector housing.  Look at the indents already [implemented as examples](https://github.com/hominoids/SBC_Case_Builder/blob/main/sbc_case_builder.scad#L1964) and do something similar of reasonable size and shape to the housing of the cable.  Most cable housings are either rectangular or round so I used an appropriate size slot for rectangles and a cylinder for round.  A more structured approach may have to be implemented for all the orientations, similar to what was done for [mask()](https://github.com/hominoids/SBC_Case_Builder/blob/main/sbc_case_builder_library.scad#L2534).

hominoids, 2022-09-25:
Are you working on this issue?

davejlong, 2022-09-27:
I'll take care of adding the indents for USB-C, Micro HDMI and 3.5mm Audio.

hominoids, 2022-10-02:
The rewrite of the indent is complete with more components added and all orientations adjusted.  All support SBC top and bottom side placement except the power plugs and the audio jack which are only supported on the top side at this time.  I have never seen either of these on the bottom of a SBC but they can be easily added if needed in the future.  I didn't find any related work in your repositories so I did all of the currently requested components.  Indents supported are hdmi_a,hdmi_mini,hdmi_micro,pwr5.5_7.5x11.5,pwr2.5_5x7.5,usb2-micro,usbc-single_horizontal and audio-jack_3.5.

Closed 2022-10-02.

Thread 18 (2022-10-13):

Adding new boards?

Botched1, 2022-10-13:
Just learned about this - installed it, and it is great! Very nice work.

Question - how hard is it to add new boards, and is that something end users can do? For instance I use a lot of RAKWireless WisBlock boards to make IoT devices, and this could potentially be a great tool to use for case design on those.

If it is something an end user can do, I would be open to making a try at doing it.

Example board:
https://store.rakwireless.com/products/rak19007-wisblock-base-board-2nd-gen

They also have 3D models for most of their stuff. Example:
https://downloads.rakwireless.com/3D_File/WisBlock/3D_RAK19007.stp

hominoids, 2022-10-13:
Boards are added in SBC Model Framework and there is a write up on the basic process at the HK forum thread.
https://forum.odroid.com/viewtopic.php?f=53&t=33823
Regarding SBC Case Builders use with new boards, as long as no new components are needed the integration is fairly straight forward.  The Customizer’s SBC list needs to be updated.  If new SBC components are needed then new components are created in sbc_library.scad and masks openings in sbc_case_builder_library.scad in the module mask().

Right now it won’t be possible to use SBC Model Framework or SBC Case Builder for complex PCB shapes because they are not supported.  I have been looking at ways to implement that capability, as well as other improvements for SBC Model Framework, so possibly in the future.

Botched1, 2022-10-29:
That is awesome! Great work.

samuk, 2024-01-27:
Would you be interested in adding a case for: https://pipci.jeffgeerling.com/boards_cm/johanns_carrier_board.html I hope to make them available for sale soon. The boards will be CERN-OHL-P open hardware

The step is https://github.com/samuk/Open-Pi/tree/main/v1/3d

hominoids, 2024-01-27:
Hi Samuk,
It is possible but please open a new issue to discuss this topic further
regarding your specific request.

hominoid

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

hominoids, 2024-02-09:
It's been awhile but I wanted to let you know  version 2 of SBC Model Framework has been released and that this has been completed, in case your still interested.  A complete rk19007 has been added to SBC Model Framework and subsequently SBC Case Builder.  I used the RAK STEP model converted to STL to locate the components, others can be created the same way.
```
use <./sbc_models.scad>
model = "rak19007";

import("RAK19007_VB_0330.stl");
sbc(model, "default", 0, "default", "default", false);
// uncomment for mask set
//#sbc(model, "default", 0, "default", "default", true);
```
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

Closed 2024-02-09.

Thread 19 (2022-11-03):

a way to just  render case top or bottom

gjm19761, 2022-11-03:
For People with smaller build plates is it possible to render the top or the bottom as individual renders ??

Nurb432, 2022-11-03:
Just go into the design in SCAD and only export one piece at a time.

gjm19761, 2022-11-03:
i dont see that option under export anywhere in scad?

Nurb432, 2022-11-03:
i will verify the parameter tonight, but if i remember right its "offset" on the object, and if you set to < 1 it hides it. Then it only exports the one piece.

hominoids, 2022-11-03:
I use Slic3r's split function to breakout the individual pieces.  One of the problems is that the platters are generated dynamically so the amount of pieces and the overall size varies considerably.  The process that @Nurb432 suggested is a good work around in some situations but won't work correctly all the time.  Many of the pieces won't be in the correct orientation to print so they would still need to be transformed again.  It won't handle any of the components from accessories correctly either.

Using debug view might work. I use it to work on individual pieces during development.  I think I can add a pick box for what piece to generate when debug is selected and then they would be in the right orientation for printing.   I'll take a look and let you know how it goes.

One other thing, Not sure what SBC you guys are using but, if anyone can help verify any of the SBC not yet verified in SBC Model Framework I would really appreciate it.  It involves simply printing a shell case for the SBC and making or letting me know what corrections are needed for sbc_models.cfg.  Unfortunately I can not own them all to do the work, I wish I could.

tomek-szczesny, 2022-11-03:
Would be handy to find a way outside of slicer. I don't own a 3D printer and just export stuff from OpenSCAD so other can print them for me.
A checkbox for displaying separate parts, well oriented for printing, would be great.
But if the script could automatically export all parts to stl format separately that'd be perfect. However I'm not sure if stl exports can be automated in OpenSCAD language.

hominoids, 2022-11-03:
I added part selection for 'debug' and setup the case parts to display at  the origin for all parts accept the accessories.  Their platter location is stored in the sbc_case_builder_accessories.cfg and are placed accordingly.  I think this will work fine for individual parts but I'll keep an open mind to other ideas. let me know if there are any issues with the current implemented approach or other brainstorms.
Tom, thanks for the input.  I though about using check boxes but they are placed vertical when there is more then one and it would take more room and might not be the best UI layout.  It also would complicate the platter creation since it would be totally dynamic and I would have to start looking at part size to be guaranteed a proper and usable platter layout for any given part combination.  I'm not sure it's worth the extra effort over the current approach.

Closed 2022-11-03.

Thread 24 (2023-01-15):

add2 + standoff creates undesired holes on top and bottom

tomek-szczesny, 2023-01-15:
I guess the idea behind standoffs was to put them either on top or bottom of a case, as the code suggests it automatically makes holes for add2 class:

https://github.com/hominoids/SBC_Case_Builder/blob/33e9c04da10243e7fb8f548405a73253eb2e5be7/sbc_case_builder.scad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

Took me a while to figure out what is going on. :) Picture below. Holes are created regardless how standoff is oriented or how high it is above the case bottom.

Code:
```
"sub","round",111,16.57,9,"bottom",[0,90,0],["case",true,false,false],9,0,4,0,0,"",0,                                    // vent cover screw hole
"add2","standoff",140,16.57,9 ,"bottom",[0,90,0],["case",false,false,false],0,0,0,0,0,0,[10,4,3.2,10,2.5,3,1,0,0,0,0], // standoff
```
In another words, a horizontal 10mm standoff stuffed into a 9mm hole.

Any way to work around this issue? I could use add1 instead but I do need to make a hole first to obtain recessed nut holder.

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

hominoids, 2023-01-15:
Thanks for the issue report.  It has been addressed in the latest commit as well as the unreported issue you identified with the standoff sidewall support for the top of cases.

Closed 2023-01-15.

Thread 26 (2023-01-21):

access_port rotation bug

amazingfate, 2023-01-21:
I want to rotate the access_port 180 degree for my rock5b v1.3 board, here is  my attempt:
```
diff --git a/sbc_case_builder_accessories.cfg b/sbc_case_builder_accessories.cfg
index 4708fee..2a8ed19 100644
--- a/sbc_case_builder_accessories.cfg
+++ b/sbc_case_builder_accessories.cfg
@@ -1354,7 +1354,7 @@ accessory_data = [
              "sub","rectangle",-1,66.5,13,"top",[0,0,0],["sbc",true,true,false],10,2,8,0,0,"",[.25,.25,.25,.25],                        // UL standoff adjustment
              "sub","rectangle",92,17.5,13,"top",[0,0,0],["sbc",true,true,false],10,2,15,0,0,"",[.25,.25,.25,.25],                        // LR standoff adjustment
              "sub","rectangle",77,67,-1,"bottom",[0,0,0],["sbc",true,true,false],15,18,12.5,0,0,"",[.25,.25,.25,.25],                   // sdcard opening
-             "add1","access_port",10,0,-0.01,"bottom",[0,0,0],["sbc",true,true,false],80,75,2,0,0,"portrait",0,                         // access port
+             "add1","access_port",90,10,-0.01,"bottom",[0,0,180],["sbc",true,true,false],80,75,2,0,0,"portrait",0,
 // access port
              "model","access_cover",10,0,-0.01,"bottom",[0,0,0],["sbc",true,true,false],80,75,2,0,0,"portrait",0,                       // model access port cover
              "platter","access_cover",-110,30,0,"bottom",[0,0,0],["case",false,false,false],80,75,2,0,0,"portrait",0],                  // platter access port cover
```
Here is what I get:
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

hominoids, 2023-01-21:
Thanks for reporting the issue, I'll take a look.

hominoids, 2023-01-22:
Give it a try now from the main branch, it should work for 180 degree rotation in landscape or portrait.  This accessory wasn’t originally designed to be rotated but this fix should work until I get to the planned improvements in this area.

FYI, The Rock5b SBC model is not verified yet and I suspect it needs some adjustments.  Unfortunately I don’t own one but I briefly worked with another Radxa user to build the current Rock5b model in SBC Model Framework but it was never verified.  I see your active on the Radxa forum so I’ll ask if you would be willing to help verify the rock5b model?

It simply means that a case for the Rock5b would need to be 3D printed from SBC Case Builder, it could be the one your working on now.   If the case is misaligned then changes are made to adjust the virtual model in sbc_models.cfg so that it matches the real SBC, using the printed case as a guide.  Once the Rock5b fits the printed case the model is correctly aligned and is verified.  All subsequent designs will then print correctly for the Rock5b within SBC Case Builder.

If your willing to give it a try let me know I can help as well.  What you would get out of it are correctly fitted Rock5b cases for yourself and the Radxa community.

amazingfate, 2023-01-22:
@hominoids Thank you for your quick fix! I have a rock5b v1.3 board which has something different compared with the public releasd v1.42 board. Here are the top and bottom photo of it:
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
Since I don't have a printer,I'm going to print a case using your builder for it by the 3D print service of JLC China. By the way I know my friend @happyme531 has printed a case using your builder for rock5b, he may help you about it.
I will modify these following things to make the case fit for my rock5b v1.3 board:
1, rotate the access_port so that it fits with the bottom emmc and m.2 location
2, change the fan connector location and add openings for it on the case
I will follow the other locations from your code. I will feedback infos when I get my case.
Here is what I've done:
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

hominoids, 2023-01-22:
Thanks for the clarification regarding the different models.  It sounds like multiple SBC Model Framework entries should be created, one for each version of the board.  If your willing to share your v1.3 changes when finished, I'll create a new SBC, rock5b-v1.3 or accept a pull request for SBC Model Framework.  Any help by you or anyone else to get working rock5b models for v1.3, v1.42 or whatever the production version is, would be appreciated.  I see Radxa just released a Rock5a too.

Closed 2023-01-22.

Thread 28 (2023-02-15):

rock5b v1.3 case verified

amazingfate, 2023-02-15:
Hello , finally I got my printed case for my rock5b v1.3 developer edition.
It works but still has some minor issues.
At first I cant't install the case because of the audio jack opening:
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
Then I cut one part of the audio jack opening, then here comes the typec opening:
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
Then I cut one part of the typec opening, here is the final state:
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

There is another issue that the power button position is not right:
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

I use the position of audio jack, typec and power button same as rock5b v1.42 in your repo. This is just a feedback from rock5b v1.3. We need users who can verify this on rock5b v1.42.

hominoids, 2023-05-10:
After waiting more then 2 months my ROCK5B arrived a couple of days ago.  I did one test prints and made a few adjustments for the 1.42v yesterday.  I have another adjustment to do and test print and it should be complete.  I'll post the corrections I made soon.  Has the status of the 1.3v changed?

amazingfate, 2023-05-11:
There are some differences between v1.3 and v1.42. I may create pull request to add adjustments on v1.3 in the future. There are only 50 V1.3 boards in the world, so not many people need this.

Closed 2023-05-10.

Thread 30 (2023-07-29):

Generating heat sinks?

gounthar, 2023-07-29:
Hi there! 👋

I have been following this repository for a few months now, and I am thrilled that it exists. Your work is impressive, and I want to thank you for it. I have also been working on building a generic library with OpenSCAD to create boxes based on SBC dimensions, rack units, and more. However, your library is lightyears ahead of mine, and I truly appreciate your contribution.

One of the things I had in mind for my library was a heatsink generator. Unfortunately, I lacked many measurements to make it effective and ensure it fits as many components as possible. My plan was to print a thin prototype in PLA to test the fit (even in translucent PLA) and then use my CNC (yes, I got one just for this purpose) to mill a large heatsink block.

So, my question is, do you think your models have enough measurements to create a custom heatsink for each board?

Thank you so much for your time and expertise. Your work has been inspiring, and I look forward to your response.

hominoids, 2023-07-30:
Well, that is an interesting and a complicated question but I believe the short answer is probably.  The library involved would be SBC Model Framework not SBC Case Builder.  Let me explain how things work now and where development is going.  In essence, what your suggesting is what happens right now for some SBC.  Some heatsink models are generate on the fly with OpenSCAD and some are models provided by the manufacturer converted to a STL.  My goal is to have them all automatically generated but using OEM models has allowed me to offer heatsinks I haven’t had time to work on yet. See the [heatsink class in sbc_library.scad](https://github.com/hominoids/SBC_Model_Framework/blob/616edae8cb62fea0a4a067d471a521597516b81c/sbc_library.scad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)

If there is an OEM heatsink they are handled as their own entry in sbc_models.cfg as x_loc,y_loc,rotation,class,type for model inclusion.  If there is no official OEM heatsink one is not displayed(RPI) or, in some cases were there is a wide and clear community driven choice, it is included. e.g. using XU4 and XU4Q heatsinks on the StarFive2 or ROCK5B.

            ["c1+",85,56,1,3.5,17,6,                                // sbc model, pcb size and component height
            3.5,3.5,3,3.5,52.5,3,                                   // pcb holes 1 and 2
            61.5,3.5,3,61.5,52.5,3,                                 // pcb holes 3 and 4
            9.385,38,3,60.615,18,3,                                 // pcb holes 5 and 6
            0,0,0,0,0,0,                                            // pcb holes 7 and 8
            0,0,0,0,0,0,                                            // pcb holes 9 and 10     
            12,12,1.25,34.4,22,0,0,"top",                           // soc1 size, location, rotation and side
            0,0,0,0,0,0,0,"",                                       // soc2 size, location, rotation and side
            0,0,0,0,0,0,0,"",                                       // soc3 size, location, rotation and side
            0,0,0,0,0,0,0,"",                                       // soc4 size, location, rotation and side
 	.
	.
	.
	9.385,38,0,"top","heatsink","c1+_oem"],                 // heatsink

In the partial [C1+ entry](https://github.com/hominoids/SBC_Model_Framework/blob/616edae8cb62fea0a4a067d471a521597516b81c/sbc_models.cfg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) above, the x,y location is relative to the heatsink origin, which can vary between heatsinks and be defined anywhere, and is usually set based on the SOC location.  There is also heatsink hole data in the fixed length portion of the SBC definition.  SBC Model Framework requires the first hole entries to be the main PCB mounting holes for the case and generally speaking the heatsink holes are defined afterwards.  So in the above example the heatsink hole location and size are indicated by holes 5 and 6.  The height of the SOC is also given in the SOC1 entry as 1.25mm. See [file format documentation](https://github.com/hominoids/SBC_Model_Framework/blob/main/README.md).

So one could use the SBC data in SBC Model Framework to know the heatsink hole locations and pattern as well as the proper x,y,z location to place the heatsink in reference to the SOC.  This information could be queried for use during the design process and then again in a checking and locating process to validate the design and check for other component interference.

To do this there are several challenges that currently exist but all of them can be overcome.

- Missing SOC data for an entry.
- Correctly identify the heatsink holes from other holes.
- Better PCB component representation.

SOC information in some instantaneous is not provided by the OEM(e.g. RPI) but can be acquired with some effort.  It is the most common reason why SBC Model Framework models are “yellow” and not verified “green”.  The SOC data isn’t necessarily required for case generation so not a big impact on SBC Case Builder.  Knowing what hole entries belong to the heatsink needs to be improved so when a PCB was more then 4 mount holes or other holes, the heatsink holes can be clearly identified.   Also, to reduce space and improve performance many SBC components have been generalized and may not be accurate in the depth of the component, which will be an issue for accurate internal SBC interference checking.  These are all identified shortcomings of version 1 of SBC Model Framework and are being addressed in version 2 currently in the SBC Model Framework branch v2update.

There are other new features and more complete and accurate library components being introduced for version 2 which will also incorporate complex PCBs and dynamic component masks.  Most of the code is done and I have been slowly working on converting all the SBC to the new format.  It should have been done by now but I stopped working on it to help with a couple of other open source projects. I hope to be back on it again soon and finish it up.  Some other information is available at the [HK forum where I write about it](https://forum.odroid.com/viewtopic.php?f=53&t=33823&start=52) sometimes.

To summarize, you could use SBC Model Framework to extract heatsink hole and placement location data to use in a heatsink design algorithm and then place the heatsink design on the same SBC model for checking and locating, either manually or autonomously.  Take a look at how SBC Case Builder searches for the selected SBC and uses the data from SBC Model Framework. The same approach can be used in your heatsink algorithm to access the needed SBC data.

It is also possible to easily integrate your heatsink algorithm into SBC Model Framework as another type of heatsink that can be used on a SBC.  The benefit of doing this is that in version 2, the opening masks are being moved from SBC Case Builder to SBC Model Framework as part of the SBC model.  What this means is automatic opening generation at the model level.  Any use of the SBC model in any design also makes an IO opening mask set available to difference against  geometry for accurate and consistent SBC openings.  Since heatsinks are considered a SBC component their opening mask is also available to use.  This means your heatsinks could work with SBC Case Builder or other future downstream application that use any SBC model from SBC Model Framework. See examples of [version 2 automatic mask generation](https://forum.odroid.com/viewtopic.php?f=53&t=33823&start=54).

gounthar, 2023-07-30:
Thanks for taking the time to provide such a detailed and insightful response to my question. Your explanation of the SBC Model Framework and how it handles heatsinks was incredibly helpful, and I truly appreciate all the pointers you gave me.

I must admit that my OpenSCAD skills are still at a beginner level, and I realize that creating code up to your standards might be challenging for me at the moment. However, I am eager to learn and progress in this area.

I will study your answer thoroughly and try to understand how I can make use of the SBC Model Framework to extract heatsink hole and placement location data for my project. The idea of integrating my heatsink algorithm (which only exists in pseudo-code in my head) into the framework as another type of heatsink sounds intriguing, and I will explore that possibility further.

hominoids, 2023-07-30:
Attached is a simple routine that searches sbc_models.cfg and prints to the console the sbc data for the requested SBC model.  It will help get you going.  I'll close this issue for now but reopen it if needed.
[SBCMF_skeleton.zip](https://github.com/hominoids/SBC_Case_Builder/files/12210216/SBCMF_skeleton.zip)

Closed 2023-07-30.

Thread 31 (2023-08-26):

Rock 5B case issues

Chippit, 2023-08-26:
The Rock5B case templates have some minor issues.

- All top pieces have two unneeded cylinders on them
- The snap case top part only has snaps on one side

The image below illustrates both problems

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

hominoids, 2023-08-26:
Thanks for reporting the problems, they are fixed in the recent commit.  Let me know if you have anymore issues.

Closed 2023-08-26.

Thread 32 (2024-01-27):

Adding support for Open Pi board

samuk, 2024-01-27:
Would you be interested in adding a case for: https://pipci.jeffgeerling.com/boards_cm/johanns_carrier_board.html I hope to make them available for sale soon. The boards will be CERN-OHL-P open hardware

The step is https://github.com/samuk/Open-Pi/tree/main/v1/3d

hominoids, 2024-01-27:
Hi Samuk,
The cases are autonomously generated from the SBC that are part of SBC
Model Framework.  To have SBC Case Builder generate cases for your
carrier board it needs to be added to SBC Model Framework.  After it is
added any of the cases in SBCCB can be generated with or without further
case customization.

After an extended development cycle, I'm on the cusp of releasing
version 2.0 of SBC Model Framework.  It's schema is significantly
different then version 1 and has features that will make adding boards
much easier, so I would recommend using version 2. It is usable in it's
current beta state and can be viewed at this branch:
https://github.com/hominoids/SBC_Model_Framework/tree/v2update

I'm currently adding more SBC, MCU and updating documentation.  I
estimate that it will take between 1-2 weeks to finalize, release
version 2.0 and integrate it into SBC Case Builder. As chance would have
it, the RPi CM4 and IO board were recently added to v2 so it can be used
as a reference.

Are you the original designer of this board or just marketing it?
What is the release timeline?
What is the scope and magnitude of your planned 1st production?
Does this carrier board/project have a name?

hominoid

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

samuk, 2024-01-27:
Hi thanks, I might just check in in two weeks. I have time.

I'm not the designer of the board, I'm just marketing & hopefully certifying it. I was given the design files on condition that it was professionally reviewed which I intend to do.

Timeline, a month or so until I have some [uncertified engineering samples](https://github.com/samuk/Open-Pi/blob/main/compliance/EvaluationBoards.md)

I may do a 20pc run of engineering samples after an initial 5pc batch.

Not sure on actual CE marked boards, never done it before. Several months at least.

I'm calling it 'Open Pi' for now but need to check how sensible that is https://github.com/samuk/Open-Pi/tree/main

hominoids, 2024-02-09:
SBC Model Framework v2 and SBC Case Builder are ready.  I have attached a sample sbc_models.cfg entry for SBC Model Framework that includes the PCB, 4 holes and the GPIO already placed.  It will get you a solid start and you will just need to place the remaining components.

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

To that end here is a simple OpenSCAD program that overlays a STL file that was converted from your STEP model.  This way components can be visually placed.  Make sure to have SBC_Model_Framework in the current directory or update the <use> statement.  When it's complete issue a PR to include it in the distribution.
```
use <./sbc_models.scad>
model = "jocabo";

rotate([0,0,90]) import("jocabo.stl");

sbc(model, "default", 0, "default", "default", false);
// uncomment to display the mask
//#sbc(model, "default", 0, "default", "default", true);

```
[test_jocabo_sbc_models.txt](https://github.com/hominoids/SBC_Case_Builder/files/14223270/test_jocabo_sbc_models.txt)
[jocabo.stl.zip](https://github.com/hominoids/SBC_Case_Builder/files/14223280/jocabo.stl.zip)

[How to add a New SBC or MCU](https://github.com/hominoids/SBC_Model_Framework#adding-devices)

[SBC Model Framework Reference Manual](https://github.com/hominoids/SBC_Model_Framework#class-and-type-reference-manual)

Good luck with your project!

Closed 2024-02-09.

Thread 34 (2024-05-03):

Missing Reset Button on Star64

Fishwaldo, 2024-05-03:
Hi,
Just some feedback - The star64 model is missing the reset button between the USB jacks and the headphone jack. I've attached a image here for your reference.
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

You can see it on the top left.

hominoids, 2024-05-03:
Thanks for the feedback, I don't have one of these SBC.  Can you post a measurement here from the top of the PCB to the top edge of the button or make the change in SBC Model Framework and issue a PR?  It looks like there are two IPEX connectors next to it as well that aren't on the model which I'll also add.  Any other corrections or additions?

Fishwaldo, 2024-05-10:
Hi, I tried to make the changes but failed miserably. Here is some measurements.

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

Fishwaldo, 2024-05-10:
Anything else you need?

Fishwaldo, 2024-05-10:
Ahhh. Sorry I was confused about the "top" of the board. Here is another pic 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

A few other things (that might be relevant?)

The Ethernet port is stacked, and by default exceeds the height of the cases. Here is the height of the Ethernet jacks:
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 (I just increased the top half by 13 or 14 (if I went to 15, the cutouts for the vent disappeared but 15 would have been nice clearance)

Also, the PCI connector exceeds the width of the PCB by 1-2mm, and is a tight fit with the side of the case. Maybe increase the width a little bit?
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

Final point, the bottom of the USB jacks also exceed the length of the board and need a cutout on the bottom of the cases, otherwise the PCB doesn't rest on the standoffs but on the edge of the bottom of the case. Maybe just increase the height of the standoffs by default?
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

Last issue: the cutout for the HDMI port should be moved a slight bit lower. It ended up printing as below: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
(HDMI port also rests on the bottom side of the case)

(Cheers for your assistance, I know a lot of people have been asking for a case for the star64!)

Fishwaldo, 2024-05-10:
Sorry 2 other small things:
This might not be an issue when the reset button is done, but right now, the length of the case is a bit small, and it rests on top of the reset button... 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 (hard to see with black PLA, sorry)

Also, the SD card slot is too low (the top of the slot needs to align with the top of the standoffs) and it needs to move slightly right when looking from the side:
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

Fishwaldo, 2024-05-10:
That last picture is from the right edge of the slot to the edge of the board.

hominoids, 2024-05-10:
Great, that's the type of feedback I need.  It looks like the PCB thickness may be incorrect since it is sitting slightly recessed in the case bottom. The top of the PCB surface should be even with the top edge of the case bottom.  Component openings in both case halves are made automatically as needed.  When it is off it can cause similar problems to what your reporting.  What is the PCB thickness?  It also looks like the gap, the distance between the PCB and case wall, may need to be increased in SBCCB.

 I'll make all these changes and include a saved case example for you to try.  The test case will tell me critical info and in the end we'll end up with a verified SBC model that will work for all the case designs in SBCCB.  I have also added the FPC connectors but it is not clear what the pin count is on them or which way the FPC cable connects.  This is important so that the mask openings face the correct direction.  The current changes are just my guesswork.  I'll let you know when the test case is ready, maybe later today still.
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

hominoids, 2024-05-11:
All the changes have been made on the Main branch of SBC Case Builder and I saved a test case called star64_shell.  When you have time, use that case for a test print so if any changes are needed I'll know what the SBCCB parameters were when printed.  You'll need to update SBCCB and it's submodule SBC Model Framework prior to printing.
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
FYI, I increased the case gap to 2mm to give more room and left the PCB thickness at the default 2mm.  The double stacked rj45 was too tall so I shortened it to 25mm.  The SBC maximum component height was also set incorrectly at 17mm which is why it protruded thru the case.  The SOC location is unknown to me so I approximated it's location.

I try to hold design tolerances to plus or minus 1/8mm so any warping or splitting of the print will effect the fit of the case.  Let me know how it went and what if any changes are needed.  Straight on photos of any problems will be helpful for the corrections.

Fishwaldo, 2024-05-11:
when I render in openscad I get the following error:
```
Parsing design (AST generation)...
Compiling design (CSG Tree generation)...
ECHO: Case_Width = 135, Depth = 87.5, Top = 28, Bottom = 12
Rendering Polygon Mesh using CGAL...
Geometries in cache: 1352
Geometry cache size in bytes: 12553112
CGAL Polyhedrons in cache: 3
CGAL cache size in bytes: 77086416
Total rendering time: 0:10:28.746
   Top level object is a 3D object:
   Simple:         no
   Vertices:    40468
   Halfedges:  144858
   Edges:       72429
   Halffacets:  64750
   Facets:      32375
   Volumes:        13
WARNING: Object may not be a valid 2-manifold and may need repair!
Rendering finished.
```

if I export to my printer it complains about a damaged STL.

Fishwaldo, 2024-05-11:
Oh and PCB thickness is 0.9

hominoids, 2024-05-11:
The Main branch and it's sub module have been updated with the new PCB thickness.  I changed the style of the SD card holder and also increased the size of the standoff support diameter to 14 for star64_shell.  At 13mm it was close to the side wall and was triggering a false positive manifold error.  OpenSCAD v21.1 complained but SuperSlicer v2.4.58.5 saw that it was indeed manifold.  The code for manifold detection isn't that sophisticated always.  I will likely add a blip about it in the README.md in the near future to warn users. Give it another try and let me know if there are any more problems.

Fishwaldo, 2024-05-15:
Hi,
I did a test print today and it's almost perfect!

1) HDMI port needs to shift to the left (when looking at it directly) by about 1.5-2mm

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

2) The Standoff are a bit misaligned on the side where the Ethernet port is. I hope you can see from this pic?
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

3) (may be just due to me doing a fast print) - the thickness of the board means it's not a perfect fit between the top/bottom parts and leave a small gap around the joint (as seen on the first photo). The rest button and SD card are aligned perfectly.

Fishwaldo, 2024-05-15:
Here is another shot of the HDMI

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

Fishwaldo, 2024-05-15:
This doesn't bother me but if you want to center the FAN over the SOC, you can see its slight off in this pic: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

It needs to move down 5mm (centered?) and to the left 4mm when viewed with the Ethernet ports on the left of the pic.

hominoids, 2024-05-16:
Ok, I made some more changes.  The HDMI was moved and the PCB thickness increased to 1.6.  I know you said 1mm but since there is a gap between the halves that cannot be right.  Most SBC are 1.6mm and that would make sense with what I'm seeing.  I also made a slight adjustment to the power connector and moved the PCB holes to 3.5mm from the corners.  FYI, The top fan opening is meant to be centered on the heatsink, not the SOC.  If you want it centered on the SOC we can disable the fan mask under the _Fan and Vent Openings_ Tab and create an accessory entry in sbc_case_builder_accessories.cfg for the new fan mask location with a subtractive entry.
https://github.com/hominoids/SBC_Case_Builder#fan_mask
When you get a chance I could use the SOC size and location too. The location measurement should be from the lower left corner of the PCB to the lower left corner of the SOC with the PCB orientated so the RJ45 connectors are on the left. That would complete the model once we finish the final tweaks.

When there are no OEM drawings or models It usually takes me at least 2-3 test prints to get things zeroed in correctly, depending on how accurate I can measure things. You might consider doing the bottom test print first to see if the holes are correct, then the top if they are correct.  If they aren't, let me know ASAP and I'll adjust them accordingly, no point in wasting time and resources. Let me know how things go...were almost done. Thanks

hominoids, 2024-05-30:
Just wanted to verify if the last adjustments worked out before I close this issue?  Does everything align?  If so, I'll mark the star64 as verified-green otherwise I'll leave it as yellow?

Fishwaldo, 2024-05-31:
Sorry I haven't had a chance to do another print. I've started one now and will let you know soon.

Fishwaldo, 2024-06-07:
Sorry I ran out of filament so only completed the print today.

The mounting holes are still a bit off. I hope these pics are clear enough for you (I have one screw on the hole near the power connector)

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

hominoids, 2024-06-07:
Ok, lets do this a different and more accurate way so not to waste any
more of your time and filament.  Also, from the photo it looks like the
PCB holes may not be located symmetrically in the corners, it's hard to
tell.

First use your digital calipers to measure the inside diameter of the
PCB hole.  Use the top set of gauges on the caliper that are designed
for measuring inside diameters.  Then use the other set to measure the
distance from the hole edge to the PCB edge in both the x and y axis, in
case the hole isn't placed symmetrically.

Half the hole diameter plus the distance from the edge of the PCB to the
edge of the hole will give us the exact location of the center of the
hole from the corner.  If the x and y measurements for the PCB edge to
hole edge are different, then the hole isn't placed systematically and
I'll need to know both measurements and which measurement goes with
which axis when the long side of the PCB board is orientated horizontal
along the x-axis.  Check all four holes too just in case they aren't
placed symmetrical to each other.  If measurements for all four holes
are the same then I only need measurements from one of them. Thanks

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

Fishwaldo, 2024-06-18:
Ok - Here we go:
hole diameter: 3.5mm
Hole A  - x side 2.66mm - y side - 2.5mm
Hole B - x side 2.66mm - y side -  2.5mm
Hole C - x side 2.66mm - y side - 2.8mm
Hole D - x side 2.66mm - y side - 2.65mm

y side width - 79.5mm
x side height - 127mm

Fishwaldo, 2024-06-18:
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

hominoids, 2024-06-25:
The holes have been adjusted.

hominoids, 2024-06-29:
I just received a very nice assortment of Pine64 SBC and one of them is a Star64.  You might want to hold off doing any test prints.  I'll start with the Star64 and after a good SBCCB test print let you know when it is ready.

hominoids, 2024-07-02:
The Star64 model has been completed and a test case printed successfully.   Your hole measurements were spot on.  The Star64_shell saved case should be used which incorporates a 3mm gap.  It has a 40mm fan mask but you can change it to 25mm in the tab _Fan and Vent Openings_ -> fan size.   The case also uses 3mm inserts in the top standoffs which can be disabled if your not using them,  tab _SBC Top Standoff Global Settings_ -> top standoff insert.  If you disable them make sure to select the standoff and hole size you want.  I consider this complete and will close the issue, thanks for the help.

Closed 2024-07-02.

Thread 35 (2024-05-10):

25mm fan?

Fishwaldo, 2024-05-10:
Any chance you can also add a 25mm Fan cutout/vent?

hominoids, 2024-05-10:
Yes, that shouldn't be a problem.

hominoids, 2024-05-11:
A 25mm x 10mm fan model and mask has been added.

Closed 2024-05-11.

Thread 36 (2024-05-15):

RPI 5 with Hats?

Fishwaldo, 2024-05-15:
What's your recommendation for RPI5 with hats? I have a NVMe Hat for my rpi5 so just increase the height of the case?

(In this model it also extends the GPIO headers above the HAT, it would be perfect if the top of the case had a cutout for the headers so they can be plugged in without disassembling the case (Like the case from Khadas in the pic below)

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

hominoids, 2024-05-16:
Yeah, that's basically it but the top standoffs need to be adjusted to accommodate the hat.  I've been meaning to model the recently released RPi M2 Hat so I did.  Since the basic footprint is the same it will work for your situation too.  I included a sample case called rpi5_m2hat_shell that can be used as is or as an example and starting point for you, take a look and let me know if it worked out ok.
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

Closed 2024-05-16.

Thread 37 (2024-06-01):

BananaPi F3 Case?

Fishwaldo, 2024-06-01:
Any chance you would be interested in adding a case for the BananaPi F3 Board?
There is a DXF file on this page that I assume could help:

https://docs.banana-pi.org/en/BPI-F3/BananaPi_BPI-F3

hominoids, 2024-06-02:
Yeah, interesting SBC, I'll need some time though to work with the dxf.  If you have this SBC a test case print would be appreciated.  Either way I'll let you know when the first revision of the model is done.

hominoids, 2024-06-07:
I've added bpif3 to SBC Model Framework and updated SBC Case Builder.  The DXF drawing was of good quality so things went well.  A SD Card model was used for the SIM Card which should work.  I'm not sure if there is any difference between the two.  I didn't have a Mini PCIe connector for the top of the PCB but that is internal and shouldn't affect case generation. I'll deal with that later.  If you have this SBC already try a test case print when you get a chance.  If you don't have it I'll kept it as unverified.  FYI, Since there is no customization needed for this SBC I didn't create a predefined case in SBCCB, you'll have to create one if you do a test print.
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

Fishwaldo, 2024-06-08:
Hi,
I tried - But get a load of errors when selecting bpif3:
`Parsing design (AST generation)...
Compiling design (CSG Tree generation)...
[WARNING: undefined operation (undefined + number) in file sbc_case_builder.scad, line 357](https://github.com/hominoids/SBC_Case_Builder/issues/357,/home/fish/github/SBC_Case_Builder/sbc_case_builder.scad)
[WARNING: undefined operation (undefined + number) in file sbc_case_builder.scad, line 357](https://github.com/hominoids/SBC_Case_Builder/issues/357,/home/fish/github/SBC_Case_Builder/sbc_case_builder.scad)
[WARNING: undefined operation (undefined + number) in file sbc_case_builder.scad, line 358](https://github.com/hominoids/SBC_Case_Builder/issues/358,/home/fish/github/SBC_Case_Builder/sbc_case_builder.scad)
[WARNING: undefined operation (undefined + number) in file sbc_case_builder.scad, line 358](https://github.com/hominoids/SBC_Case_Builder/issues/358,/home/fish/github/SBC_Case_Builder/sbc_case_builder.scad)
[WARNING: undefined operation (undefined + number) in file sbc_case_builder.scad, line 359](https://github.com/hominoids/SBC_Case_Builder/issues/359,/home/fish/github/SBC_Case_Builder/sbc_case_builder.scad)
[WARNING: undefined operation (undefined + number) in file sbc_case_builder.scad, line 359](https://github.com/hominoids/SBC_Case_Builder/issues/359,/home/fish/github/SBC_Case_Builder/sbc_case_builder.scad)
[WARNING: undefined operation (undefined + number) in file sbc_case_builder.scad, line 359](https://github.com/hominoids/SBC_Case_Builder/issues/359,/home/fish/github/SBC_Case_Builder/sbc_case_builder.scad)
[WARNING: undefined operation (undefined + undefined) in file sbc_case_builder.scad, line 360](https://github.com/hominoids/SBC_Case_Builder/issues/360,/home/fish/github/SBC_Case_Builder/sbc_case_builder.scad)
[WARNING: undefined operation (undefined + number) in file sbc_case_builder.scad, line 360](https://github.com/hominoids/SBC_Case_Builder/issues/360,/home/fish/github/SBC_Case_Builder/sbc_case_builder.scad)
[WARNING: undefined operation (undefined + number) in file sbc_case_builder.scad, line 360](https://github.com/hominoids/SBC_Case_Builder/issues/360,/home/fish/github/SBC_Case_Builder/sbc_case_builder.scad)
[WARNING: undefined operation (undefined + undefined) in file sbc_case_builder.scad, line 361](https://github.com/hominoids/SBC_Case_Builder/issues/361,/home/fish/github/SBC_Case_Builder/sbc_case_builder.scad)
[WARNING: undefined operation (undefined - number) in file sbc_case_builder.scad, line 362](https://github.com/hominoids/SBC_Case_Builder/issues/362,/home/fish/github/SBC_Case_Builder/sbc_case_builder.scad)
[WARNING: undefined operation (undefined - number) in file sbc_case_builder.scad, line 362](https://github.com/hominoids/SBC_Case_Builder/issues/362,/home/fish/github/SBC_Case_Builder/sbc_case_builder.scad)
[WARNING: pow() parameter could not be converted in file sbc_case_builder.scad, line 362](https://github.com/hominoids/SBC_Case_Builder/issues/362,/home/fish/github/SBC_Case_Builder/sbc_case_builder.scad)
[WARNING: undefined operation (undefined - number) in file sbc_case_builder.scad, line 362](https://github.com/hominoids/SBC_Case_Builder/issues/362,/home/fish/github/SBC_Case_Builder/sbc_case_builder.scad)
[WARNING: undefined operation (undefined - number) in file sbc_case_builder.scad, line 362](https://github.com/hominoids/SBC_Case_Builder/issues/362,/home/fish/github/SBC_Case_Builder/sbc_case_builder.scad)
[WARNING: pow() parameter could not be converted in file sbc_case_builder.scad, line 362](https://github.com/hominoids/SBC_Case_Builder/issues/362,/home/fish/github/SBC_Case_Builder/sbc_case_builder.scad)
[WARNING: undefined operation (undefined + undefined) in file sbc_case_builder.scad, line 362](https://github.com/hominoids/SBC_Case_Builder/issues/362,/home/fish/github/SBC_Case_Builder/sbc_case_builder.scad)
[WARNING: sqrt() parameter could not be converted in file sbc_case_builder.scad, line 362](https://github.com/hominoids/SBC_Case_Builder/issues/362,/home/fish/github/SBC_Case_Builder/sbc_case_builder.scad)
[WARNING: undefined operation (undefined + number) in file sbc_case_builder.scad, line 363](https://github.com/hominoids/SBC_Case_Builder/issues/363,/home/fish/github/SBC_Case_Builder/sbc_case_builder.scad)
[WARNING: pow() parameter could not be converted in file sbc_case_builder.scad, line 363](https://github.com/hominoids/SBC_Case_Builder/issues/363,/home/fish/github/SBC_Case_Builder/sbc_case_builder.scad)
[WARNING: undefined operation (undefined + number) in file sbc_case_builder.scad, line 363](https://github.com/hominoids/SBC_Case_Builder/issues/363,/home/fish/github/SBC_Case_Builder/sbc_case_builder.scad)
[WARNING: pow() parameter could not be converted in file sbc_case_builder.scad, line 363](https://github.com/hominoids/SBC_Case_Builder/issues/363,/home/fish/github/SBC_Case_Builder/sbc_case_builder.scad)
[WARNING: undefined operation (undefined + undefined) in file sbc_case_builder.scad, line 363](https://github.com/hominoids/SBC_Case_Builder/issues/363,/home/fish/github/SBC_Case_Builder/sbc_case_builder.scad)
[WARNING: sqrt() parameter could not be converted in file sbc_case_builder.scad, line 363](https://github.com/hominoids/SBC_Case_Builder/issues/363,/home/fish/github/SBC_Case_Builder/sbc_case_builder.scad)
[WARNING: len() parameter could not be converted in file sbc_case_builder.scad, line 560](https://github.com/hominoids/SBC_Case_Builder/issues/560,/home/fish/github/SBC_Case_Builder/sbc_case_builder.scad)
[WARNING: undefined operation (undefined * number) in file sbc_case_builder.scad, line 560](https://github.com/hominoids/SBC_Case_Builder/issues/560,/home/fish/github/SBC_Case_Builder/sbc_case_builder.scad)
[WARNING: undefined operation (undefined + undefined) in file sbc_case_builder.scad, line 560](https://github.com/hominoids/SBC_Case_Builder/issues/560,/home/fish/github/SBC_Case_Builder/sbc_case_builder.scad)
[WARNING: undefined operation (undefined / number) in file mod/case_bottom.scad, line 40](https://github.com/hominoids/SBC_Case_Builder/issues/40,/home/fish/github/SBC_Case_Builder/mod/case_bottom.scad)
[WARNING: undefined operation (undefined - number) in file mod/case_bottom.scad, line 40](https://github.com/hominoids/SBC_Case_Builder/issues/40,/home/fish/github/SBC_Case_Builder/mod/case_bottom.scad)
[WARNING: undefined operation (undefined - number) in file mod/case_bottom.scad, line 40](https://github.com/hominoids/SBC_Case_Builder/issues/40,/home/fish/github/SBC_Case_Builder/mod/case_bottom.scad)
[WARNING: undefined operation (undefined / number) in file mod/case_bottom.scad, line 40](https://github.com/hominoids/SBC_Case_Builder/issues/40,/home/fish/github/SBC_Case_Builder/mod/case_bottom.scad)
[WARNING: undefined operation (undefined - number) in file mod/case_bottom.scad, line 40](https://github.com/hominoids/SBC_Case_Builder/issues/40,/home/fish/github/SBC_Case_Builder/mod/case_bottom.scad)
[WARNING: undefined operation (undefined - number) in file mod/case_bottom.scad, line 40](https://github.com/hominoids/SBC_Case_Builder/issues/40,/home/fish/github/SBC_Case_Builder/mod/case_bottom.scad)
[WARNING: undefined operation (undefined / number) in file mod/case_bottom.scad, line 40](https://github.com/hominoids/SBC_Case_Builder/issues/40,/home/fish/github/SBC_Case_Builder/mod/case_bottom.scad)
[WARNING: Unable to convert translate([undef, undef, undef]) parameter to a vec3 or vec2 of numbers in file mod/case_bottom.scad, line 40](https://github.com/hominoids/SBC_Case_Builder/issues/40,/home/fish/github/SBC_Case_Builder/mod/case_bottom.scad)
[WARNING: Unable to convert cube(size=[undef, undef, undef], ...) parameter to a number or a vec3 of numbers in file mod/fillets.scad, line 170](https://github.com/hominoids/SBC_Case_Builder/issues/170,/home/fish/github/SBC_Case_Builder/mod/fillets.scad)
[WARNING: undefined operation (undefined / number) in file mod/fillets.scad, line 107](https://github.com/hominoids/SBC_Case_Builder/issues/107,/home/fish/github/SBC_Case_Builder/mod/fillets.scad)
[WARNING: undefined operation (undefined / number) in file mod/fillets.scad, line 107](https://github.com/hominoids/SBC_Case_Builder/issues/107,/home/fish/github/SBC_Case_Builder/mod/fillets.scad)
[WARNING: Unable to convert translate([undef, undef, 0]) parameter to a vec3 or vec2 of numbers in file mod/fillets.scad, line 107](https://github.com/hominoids/SBC_Case_Builder/issues/107,/home/fish/github/SBC_Case_Builder/mod/fillets.scad)
[WARNING: undefined operation (-undefined) in file mod/fillets.scad, line 107](https://github.com/hominoids/SBC_Case_Builder/issues/107,/home/fish/github/SBC_Case_Builder/mod/fillets.scad)
[WARNING: undefined operation (undefined / number) in file mod/fillets.scad, line 107](https://github.com/hominoids/SBC_Case_Builder/issues/107,/home/fish/github/SBC_Case_Builder/mod/fillets.scad)
[WARNING: Unable to convert translate([0, 0, undef]) parameter to a vec3 or vec2 of numbers in file mod/fillets.scad, line 107](https://github.com/hominoids/SBC_Case_Builder/issues/107,/home/fish/github/SBC_Case_Builder/mod/fillets.scad)
[WARNING: undefined operation (undefined + number) in file mod/fillets.scad, line 88](https://github.com/hominoids/SBC_Case_Builder/issues/88,/home/fish/github/SBC_Case_Builder/mod/fillets.scad)
[WARNING: undefined operation (undefined / number) in file mod/fillets.scad, line 109](https://github.com/hominoids/SBC_Case_Builder/issues/109,/home/fish/github/SBC_Case_Builder/mod/fillets.scad)
[WARNING: undefined operation (undefined / number) in file mod/fillets.scad, line 109](https://github.com/hominoids/SBC_Case_Builder/issues/109,/home/fish/github/SBC_Case_Builder/mod/fillets.scad)
[WARNING: Unable to convert translate([undef, undef, 0]) parameter to a vec3 or vec2 of numbers in file mod/fillets.scad, line 109](https://github.com/hominoids/SBC_Case_Builder/issues/109,/home/fish/github/SBC_Case_Builder/mod/fillets.scad)
[WARNING: undefined operation (-undefined) in file mod/fillets.scad, line 109](https://github.com/hominoids/SBC_Case_Builder/issues/109,/home/fish/github/SBC_Case_Builder/mod/fillets.scad)
[WARNING: undefined operation (undefined / number) in file mod/fillets.scad, line 109](https://github.com/hominoids/SBC_Case_Builder/issues/109,/home/fish/github/SBC_Case_Builder/mod/fillets.scad)
[WARNING: Unable to convert translate([0, 0, undef]) parameter to a vec3 or vec2 of numbers in file mod/fillets.scad, line 109](https://github.com/hominoids/SBC_Case_Builder/issues/109,/home/fish/github/SBC_Case_Builder/mod/fillets.scad)
[WARNING: undefined operation (undefined / number) in file mod/fillets.scad, line 110](https://github.com/hominoids/SBC_Case_Builder/issues/110,/home/fish/github/SBC_Case_Builder/mod/fillets.scad)
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

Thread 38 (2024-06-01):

Increase height for additional HATs

sprange, 2024-06-01:
Amazing project for OpenSCAD!  However for the life of me I can't figure out how to increase the case height.  My PI5 has a POE hat and a GPIO relay so I need a taller case.  I can't seem to find any parameter that affects the height of the case.  Any assistance would be great!

hominoids, 2024-06-02:
The example case rpi5_m2hat_shell is based on the official RPI M2 hat which uses 16mm standoffs and has a PCB thickness of 1.65mm.  When using a third party hat both of these factors need to be taken into account as well as the actual additional height that might be needed for component clearance.

So lets say that the third party hat PCB thickness is the same(1.65mm) but uses 17mm standoffs instead of 16mm.  Lets also assume that 2mm more is needed for the third party hat component clearance.  That means we need to increase the top case height by 3mm and reduce the top standoff height by 2mm for our hypothetical third party hat to fit.  If the third party hat PCB thickness was different then we would also need to make an appropriate adjustment for the difference in PCB thickness, both in the case height and top standoffs.

It might seem a little confusing at first but if you take your time and study the animation example I'm sure you'll understand whats going on and be able to apply it to your own situation.  I also realize that the 20mm standoff adjustment range may not work for some of the hats I've seen lately due to an increase in standoff and component height, so I just increased it to 30mm and pushed the update onto the main branch in case yours needs more adjustment then the previous 20mm allowed.

I'll leave this issue open through the weekend in case you have more questions but also let me know if everything worked out for you.
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

hominoids, 2024-06-02:
lol, In my rush I got it wrong!  In the example above the top case standoffs only need to be reduced by 1mm not 2mm since the supplied hat standoffs increased from 16mm to 17mm.  The two millimeters was for the component clearance for a total case height increase of 3mm.

sprange, 2024-06-02:
Ok totally makes sense.  I swear I tried 3D adjustments before asking but obviously not.  Thanks for taking the time to help me!

Closed 2024-06-02.

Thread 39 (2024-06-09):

Suggestions for improving the program

Robocycle, 2024-06-09:
Hi! I will immediately apologize for not knowing English, I wrote to you through a translator. I would like to thank you for such a wonderful program as "SBC Case Builder". I used it to create a case for my Rock 5b. In general, everything is fine, but there are two points that I would like to improve. These are just suggestions for improving your program. First: adding a parameter to the settings that would allow you to adjust the inner radius, in addition to "corner fillets". Something like "inner corner fillets". When creating a box, the wall thickness at the bend point is greater than the thickness of the straight wall. Because of this, when processing in a slicer, an additional line or point is added at the bend point. This is not very nice and increases the printing time.
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
The "inner corner fillets" parameter would allow you to adjust the radius so that the bending thickness and the wall thickness are the same.
 Second: adding chamfering or rounding to the program settings at the junction of the racks ("standoff") and the bottom of the box instead of the cylindrical "standoff support". This results in a smooth transition and increases the strength of the racks ("standoff").
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
With gratitude and respect to you, Robocycle.

hominoids, 2024-06-09:
Hello,
Thank you for your suggestions.  Your right that the inner corner fillet is not calculated correctly. The premise of SBC Case Builder is autonomous case generation so instead of adding another entry in the user interface for an inner corner fillet, the code has been fixed to generate the correct thickness at the corners.  The wall thickness at the corner fillet is now the same thickness as the rest of the wall per this [commit](https://github.com/hominoids/SBC_Case_Builder/commit/29192ea4415a77698951c3d910ad52d300f1fdb7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).

The second suggestion is more complex then what it appears.  The purpose of the "standoff support height" is to allow screw heads and nuts to be recessed in thin floors or ceilings that normally would not support the recess due to their thickness.  Tapering the support would interfere with the recess in some situations due to the reduction of the wall thickness at the recess caused by the taper.

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

For the bottom of most cases, the standoff support height needs to be kept as short as possible so as not to interfere with nearby PCB components.

The other problem with your suggestion is that the "standoff support height" is also used to create a deep recessed standoff for tall cases. This allows the use of significantly shorter fasteners and a tapered support would not allow this use.  Keeping its current cylinder form allows the most flexibility in my opinion.

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

The third point I would make is that the "standoff sidewall support" provides better strength for standoffs then a tapered support approach. Standoff side wall support is available for all standoffs and it's position and length can be controlled per individual standoff.  The length of the side wall support is determined by the "standoff support diameter".

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

Here is an example of case that uses both methods.

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

Thanks for taking the time to make these suggestions and don't worry about having to use a translator, it worked well and I understood your suggestions.  I have fixed the corner fillet wall thickness and consider this issued closed. I'm glad that SBC Case Builder has been useful for you.

Closed 2024-06-09.

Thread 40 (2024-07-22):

Thank you and questions for a 20cm tall case...

vijaygill, 2024-07-22:
Hi,

First of all, thanks for such a great piece of software. I tried I could really play with various designs.

Now, I am trying to create a case for Rock 5A based nas (the SBC has same layour as Raspberry Pi 4C) using Radxa Penta SATA HAT. When I set tz value to say 200 to get a really tall case, I find two limitations

1. I foresee problem in installing the board. Is there a way I can have that lid at the top taller so that lower part can be made shorter?
2. I cannot seem to add a fan on the side wall. Is this to be done as post-design step in another editor or can the framework achieve it too? I deally I would like to add fan at the top, I was just trying to add it on the side in the design.

Thank you once again and apoligies in advance if my requirements are too stupid.

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

hominoids, 2024-07-23:
The Fitted case top is a fixed height and cannot be changed but that won't solve the problem your likely to have during installation anyway.  Setting the gap value correctly should solve the SBC installation issue and allow it to be installed regardless of the case bottom height. In the *3D Case Adjustments* Tab, increase the gap so there is very little to no protrusion of any component overhang thru the sidewall. The README.md briefly talks about [component overhang and case gap](https://github.com/hominoids/SBC_Case_Builder?tab=readme-ov-file#component-overhang-and-case-gap ).

As far as the second issue goes, fan mask patterns cannot be 3D printed on a vertical sidewall AFAIK, but a round opening can be created for use with a fan cover as an accessory.  There are saved examples such as hc4_shell_drivebox2.5 that use this technique.
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
It uses the following accessory entries to create a sidewall fan opening and fan cover.  Something similar should work for your case.
```
"model","fan",39,10,7.5,"bottom",[90,0,0],["case",true,false,false],[40,0,3],["box40x10"],[true,10,2,"fan_open"],
"model","fan_cover",39,-4,7.5,"bottom",[90,0,0],["case",true,false,false],[40,0,3],["fan_1"],[false,10,2,"default"],
"platter","fan_cover",-50,50,0,"bottom",[0,0,0],["case",false,false,false],[40,0,3],["fan_1"],[false,10,2,"default"],

```
You'll need to create and assign an accessory group to your case, look at the examples and read the [Accessory subsystem and use](https://github.com/hominoids/SBC_Case_Builder?tab=readme-ov-file#accessory-subsystem) section in the README.md file.

Accessory Reference Entries
https://github.com/hominoids/SBC_Case_Builder#fan
https://github.com/hominoids/SBC_Case_Builder#fan_cover

vijaygill, 2024-07-23:
@hominoids Thanks once again for a detailed reply. I wil try as per your suggestion.

Closed 2024-07-23.

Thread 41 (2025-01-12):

Case selection very limited

sstainba, 2025-01-12:
I have just installed the lastest version of OpenSCAD for Windows (tried by 32- and 64-bit) and cloned the SBC project, did the init and the update.  However, I have a VERY limited selected of SBCs.  There's probably about 25-30 or so showing in the drop-down.  There are no RPi (other than the default) and no OrangePi, for example.

hominoids, 2025-01-13:
The predefined case pull down is not meant to hold all possible cases. With thousands of possible cases that is not practical or possible with the limitations of the Customizer UI within OpenSCAD.  The pull down menu of predefined cases are custom cases or ones that have additional changes from the accessories subsystem.  In addition, a reference shell case is included as a benefit for all SBC from the OEMs that support this project by supplying SBC samples, Hard Kernel and Pine64.

This tool is meant to autonomously build cases for any supported SBC by selecting the SBC and base case design under the View tab. It will automatically create the smallest possible symmetrical case using the current default tab settings.  Any additional changes desired can also be made from the respective tab default settings e.g. the type of standoff fasteners to use for the top and bottom.

This is explained in the README.md file and I would strongly recommend you pay special attention to the [notes-tips-and-things-to-check](https://github.com/hominoids/SBC_Case_Builder#notes-tips-and-things-to-check) section for other suggestions of things to consider when setting up a case.  Any case you create can then be saved in the predefined case pull down menu by pressing the + sign next to the 'save preset' button near the top of the GUI.  The + sign creates a new entry and the 'save preset' button saves the current selected preset.  There is also an area in the README.md that covers what each [GUI tab and its parameters](https://github.com/hominoids/SBC_Case_Builder#graphical-user-interface) accomplish.

So if you want an OrangePi shell case select the correct SBC under the View tab and then select the case design.  It will be automatically created and any other changes you want can be selected from the appropriate tab for the default presets.  It's that simple.  FYI, What you are calling the default RPI case is not the default case.  It is an example of a custom RPI5 case incorporating a M2 HAT accessory.

If you need further assistance reopen this issue or create another.

Closed 2025-01-13.

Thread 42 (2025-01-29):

Bottom standoffs - Bug or user

origin2000, 2025-01-29:
OS: OpenSUSE Leap 15.6
OpenSCAD: 2021.01
SBC_Case_Builder 3.0 - current github.

First let me thank you for this great tool! I very much enjoy working with it, although I'm new to it an just started with my first project.

I designed an Extended Case for a Radxa 4c+ v1.41 using the base case design „shell“.
Here’s my workflow:
    1) Created a new model for the 4c+ based upon rpi4b in SBC_Model_Framework/sbc_models.cfg.
    2) „Integrated“ it following the instructions using get_customized_values.scad
    3) Verified the model by 3D printing a regular shell case.

But the bottom standoff support is cutting out material from the wall which results in a thinner wall up to the height of the full standoff. The workaround is changing the bottom standoff size support from 10,00 to 9,00. Cause the position of the standoff is defined by the pcb it’s not moving anywhere => problem fixed.

In the case of  extended case bottom standoff this doesn’t work. Changing the ex case bottom standoff size, say from 10,00 to 8,00 moves the whole standoff closer to the corner still cutting material from the wall.

This is not happening with the top standoffs for both sbc and extended. Changing the model i.e. to rpi4b or c1+ shows the same behavior.

Is this a bug or is it me? It looks like a boolean operation should be union but is cut. Can I fix this in one of the OpenSCAD files? If yes, where.

I also would like to contribute the Radxa 4c+ v1.41 model. What’s the process?

hominoids, 2025-01-30:
Thanks for opening an issue. Looking at the code there is a bug in the Extended Case Standoff placement.  As you already figured out, the PCB Standoffs are fixed to the PCB hole locations and work as designed.  Changing the PCB Standoff Support Size is the way to address the issue you encountered.

The extended case standoffs were originally fixed as well, at 10mm from the corners.  When variable standoff sizes(3mm, 2.5mm, etc) were implemented their location was changed to be relative to the Standoff Support Size.  This change allowed them to be placed closer to the corner of the case and why they move when you change the support size. I 'll make any corrections that are needed for the Extended Standoff placement and post the fix once completed and tested.  It's late evening here now so I anticipate 24 hours time should be sufficient unless I run into some unforeseen problem.

Regarding the Union verse Subtraction, a hole is first created in the case that is slightly smaller then the Standoff Support Size and then the standoff geometry is placed at the same location.  This is required so that the type of fastener end( blind, countersunk, recessed, etc) can be accommodated in the case geometry, otherwise they would be covered by the case geometry and not visible.

Regarding contributing your Rock 4c+ model, that would be welcomed and appreciated.  Knowing that Radxa doesn't do a very good job with their documentation IMO, I am confused.  There is already a Rock 4c+ in SBC Model Framework which I thought was version 1.4.  So are these corrections to the existing model, a new model version or something else?  If I remember correctly the current model was created based on the [STEP model from their Wiki](https://wiki.radxa.com/Rock4/hardware) and is unverified(yellow) and may need corrections.  Regardless, it would be good to have a verified model of the Radxa 4c+ since I don't own one, so your help in adding or updating the current version would be appreciated.  The program [sbc_models_viewer.scad](https://github.com/hominoids/SBC_Model_Framework#sbc-model-and-component-viewer) within SBC Model Framework can be used to view the current models using a customizer GUI.

Regarding the process, SBC models for SBC Case Builder are added to [SBC Model Framework](https://github.com/hominoids/SBC_Model_Framework) in a separate repository.  The technical process to add a model you seemed to have figured out already, add appropriate entries to sbc_models.cfg.  For reference, there is information in the README.md for SBC Model Framework that explicitly explains the [technical process](https://github.com/hominoids/SBC_Model_Framework#adding-devices).

So to add or update a model, start by forking SBC Model Framework, add or modify the SBC model in sbc_models.cfg and then issue a Pull Request.  I'll handle the changes necessary for SBC Case Builder and update along with the sub-module linkage to pull the latest version of SBC Model Framework.  Once this is done any one that installs either will get the updated models.  Those with existing SBCCB installations will need to update SBC Case Builder and it's sub-module SBC Model Framework, as noted in the SBC Case Builder README.md.   If it is easier for you, instead of a PR you can open an issue in SBC Model Framework and post your entry from sbc_model.cfg for the Rock 4c+.  The only down side with this approach is you wouldn't be shown as a contributor to the project.

hominoids, 2025-01-30:
Ok, I changed the code so as not to interfere with case side wall geometry for any of the standoffs.  Don't forget to save your case entry in the sbc_case_builder.json file, if you saved it, otherwise it will be over written when you update SBC Case Builder.

Also let me know if you have any more problems and the answers to my questions above about the Rock4c+ model.  If your print is good I'll change the status to verified(green) based on the answer to the model questions.  If you haven't found the current Rock 4c+ model in SBC Case Builder take a look at my response to this [past closed issue](https://github.com/hominoids/SBC_Case_Builder/issues/41).

origin2000, 2025-02-01:
Many thanks for the incredible fast reply and fix! Just saw it on my mobile. I will test tomorrow ;-) In regard to adding the 4c+ v1.4 model I will give it a try as you described. I will also check the .step file they provided. The major difference though was a few mm here and there plus the stacked USB ports being on the wrong side. Stay tuned ;-) Thanks again!

hominoids, 2025-02-04:
Issued addressed under https://github.com/hominoids/SBC_Model_Framework/issues/19, closed

Closed 2025-02-04.

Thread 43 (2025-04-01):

Fitted case top standoffs floating above surface

sm-s2ack, 2025-04-01:
Hi

Tested the latest code base and noticed that the top standoffs in a couple of the "Fitted" case designs are floating above surface.  I tried correcting with all available parameter but couldn't manage to get it working,  I think the fix (if needed) is somewhere in case_top.scad but I'm only guessing?

I've attached STL exports and some images for just the top sections of the C+ and Quartz64a cases just to show what I'm seeing

Any more info need just let me know.

Great work by the way!

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

[top_standoffs_fitted_case_floating.zip](https://github.com/user-attachments/files/19553398/top_standoffs_fitted_case_floating.zip)

hominoids, 2025-04-01:
Thanks for reporting the issue, it should be fixed with the latest push.  FYI, some case designs have different case_z heights and it wasn't being handled correctly for the top standoffs.  The bug effected the top standoffs for the fitted, snap and tray_sides cases, all ones that typically don't use top standoffs but have additional case height for the design.  If you have anymore issues let me know.

sm-s2ack, 2025-04-02:
@hominoids Thanks for the quick response and fixes, very much appreciated!

Closed 2025-04-01.

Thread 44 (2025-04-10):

Request for adding Pimoroni NVMe Base to Acessories

mtinman, 2025-04-10:
Hominoids,

I'm hoping that this is the proper way to ask for this, please feel free to contact me to let me know either way (j.m.wall@thegeekden.net). Just wanted to put in a request for adding the [Pimoroni NVMe Base](https://shop.pimoroni.com/products/nvme-base?variant=41219587178579) to the SBC_CASE_Builder. The resources for this can be found at the link above, but to make it easier for you to deal with, here are the links:

1. [Dimensional drawing](https://cdn.shopify.com/s/files/1/0174/1800/files/nvme-hat-drawing.pdf?v=1714386681)
2. [PNG](https://cdn.shopify.com/s/files/1/0174/1800/files/nvme-base-model.png?v=1714386681)
3. [STEP](https://cdn.shopify.com/s/files/1/0174/1800/files/nvme-base-model.step?v=1714386685)
4. [STL&SCAD](https://thegeekden.net/share/share/Pimoroni-nvme-base-STL&SCAD.zip)

I attempted to convert the STEP file provided by Pimoroni to SCAD file format, but the best I could do is to drag and drop the STL file into OpenSCAD to do so. I have included those files in the zip file below, so it can be at least viewed in OpenSCAD. I have also attached the files for this issue (request for feature) ticket below, so as to save you a bit more work.

Thank You! :-)  in advance for help on this, and please feel free to contact me at the above email regarding this. Also, if there is a place to chat in real time regarding SBC_Case_Builder, and/or potentially help with the project, please let me know, I would be happy to help in the ways that I can...

Here are the files:

[Pimoroni-nvme-base-STL&SCAD.zip](https://github.com/user-attachments/files/19693475/Pimoroni-nvme-base-STL.SCAD.zip)
[nvme-base-model.png (PNG Image, 1528 × 1024 pixels) — Scaled (91_).pdf](https://github.com/user-attachments/files/19693476/nvme-base-model.png.PNG.Image.1528.x.1024.pixels.Scaled.91_.pdf)
[NVMe Base for Raspberry Pi 5.pdf](https://github.com/user-attachments/files/19693478/NVMe.Base.for.Raspberry.Pi.5.pdf)
[Pimoroni-nvme-hat-drawing.pdf](https://github.com/user-attachments/files/19693477/Pimoroni-nvme-hat-drawing.pdf)

.

hominoids, 2025-04-11:
An OpenSCAD model isn’t necessary since there is an OEM STEP model and there are no case openings for this device, it is only acting as a place holder.  I added a case that uses the OEM STEP model converted to STL.  The case example is rpi5_bottom_m2hat_shell and is available with the latest repository commit in the saved cases pickbox.

FYI, this PCB was different then most HAT setups because it is larger then the SBC and the holes are offset from the edge.  There is also conflicting information regarding the PCB thickness.  The STEP model PCB is 2mm and the drawings say the PCB is 1.6mm.  Since most 4-layer PCB are 1.6mm I setup the example case to that thickness.  The case will need some adjustments if the Pimoroni PCB is not 1.6mm thick - you'll need to measure.

If you do need to make adjustments, in the view tab set the rear face to -1 to section off that side in order to view the internal fitment as shown below, it makes it a lot easier.  I have attached the STL I used to set up the example case.  It is used as an accessory so If you want to view it in the case model edit the file sbc_case_builder_accessories.cfg and un-comment the entry for it on line number [476](https://github.com/hominoids/SBC_Case_Builder/blob/3fee9e59ce8c06adda5ce3c482ef64fc8ee8ade6/sbc_case_builder_accessories.cfg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
) and make sure the model path is correct.

[pimoroni-nvme-rpi5-base.stl.zip](https://github.com/user-attachments/files/19713104/pimoroni-nvme-rpi5-base.stl.zip)

The example case is setup for inserts for the case bottom and countersunk 2.5mm screws from the top.   Change as necessary to accommodate your available fastener hardware.  I'm closing this issue but you can still post to it if you have other questions or further issues.

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

mtinman, 2025-04-14:
Thank You Very Much for doing that, I GREATLY appreciate it. I have the Pimoroni NVMe base, and verified the PCB thickness at 1.6mm.

Closed 2025-04-11.

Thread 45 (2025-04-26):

rackmod 1u slide: 19" slide in cases

origin2000, 2025-04-26:
There is a project on www.makerworld.com that provides a nice framework for 1U and 2U slide in cases:

https://makerworld.com/de/models/1040867-rackmod-1u-slide-a-modular-server-rack-system#profileId-1025742

It is a nice fit for SBCs but also other PCBs.

What is the process to create a new "rackmod 1U slide case" for the SBC Case Builder?

My first use case would be to use it for radxa 4c+ SBCs.

Thx in advance for the feedback.

hominoids, 2025-04-27:
SBC Case Builder is a FOSS project and the project in your link is not.  It has an abnormally restrictive license so It will not be possible to work with them at all.

hominoids, 2025-06-04:
FYI, a rack case was recently added to SBCCB.  More info can be found at my [Hardkernel forum post](https://forum.odroid.com/viewtopic.php?f=53&t=43948&start=117).

Closed 2025-04-27.

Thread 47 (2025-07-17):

Creating accessories

11mbs, 2025-07-17:
Hi! Thanks so much for such a beautiful tool!
I am trying to create some custom holes in the case for a custom board/shield on a rpi4.
I have tried making a custom accessory in the .cfg file but it's not showing up on the dropdown menu and I'm not confident .
Is there any way to use normal openscad commands to interact with the models the tool generates?

Closed 2025-07-17.

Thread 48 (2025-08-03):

Rock5BQ doesn't seem to create the middle_rear or middle_front type standoffs

sm-s2ack, 2025-08-03:
Hi

Found a small issue while designing a case that has a "middle" pcb holes and noticed they dont apear in the Case Builder View when using shell or fitted options.

I checked against the Rock5B+ (which has similar "middle" pcb holes) and is seems to exhibit the same issue.  I've tried a few GUI otpins but cant seem to get them to appear.  Maybe its becasue of the honeycomb vents and the fan opening or im not selecting the correct option or may they are not suppoed to appear?

Anyway, here's the model view.

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

And here's the Case Builder view in paltter mode.  I circled where the standoffs should be.

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

Thanks

sm-s2ack, 2025-08-04:
Hi

I just realised you can add a standoff manually in the accessories.cfg file so I can leave the pcb holes defined as middle_rear, middle_front in sbc_models.cfg.   If I change them to right_front/left_front/right_rear/left_rear it creates an extra hole on the side of a "tray" design I was working on.  It might be to do with the fact the rear_right pcb hole is so close to the edge?  Thats a different issue or an invalid use of pcbhold attributes on my part though.

            "pcb","rectangle",0,0,0,0,"top",[0,0,0],[140,80,1.65],[3,"#252525",0,0,0,17,7,0],[false,10,2,"default"],

            // left_rear
            "pcbhole","round",0,5,16.7,0,"top",[0,0,0],[3,0,0],["both","#fee5a6","rear",3,"left_rear"],[false,10,2,"default"],

            // middle
            "pcbhole","round",0,96.8,11.1,0,"top",[0,0,0],[3,0,0],["both","#fee5a6","rear",3,"right_rear"],[false,10,2,"default"],

            // actual right_rear
            "pcbhole","round",0,136,4,0,"top",[0,0,0],[3,0,0],["both","#fee5a6","rear",3,"right_rear"],[false,10,2,"default"],   

            "pcbhole","round",0,5,64.2,0,"top",[0,0,0],[3,0,0],["both","#fee5a6","front",3,"left_front"],[false,10,2,"default"],
            "pcbhole","round",0,103.6,77,0,"top",[0,0,0],[3,0,0],["both","#fee5a6","front",3,"right_front"],[false,10,2,"default"],

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

I can use the accessories.cfg approach to creat my middle standoffs anyway, so can probably close this issue.

Thanks

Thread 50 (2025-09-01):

Panel case extended standoff "ears"

thiakil, 2025-09-01:
With the Panel case type, the corner standoffs protrude off the corner of the bottom/top faces, rendering inside the panels.
When printed this means the tabs in the front/back cant work, as no allowance is subtracted and the panels bow outwards

Is it a bug, or am I missing something?

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

hominoids, 2025-09-01:
I changed the positioning of the extended standoffs so they are always within the case and don't extend into the side wall anymore.  I guess it makes more sense this way and should work for your application.  For this example I did have to reduce the bottom SBC standoff's support diameter as well, from 10mm to 9mm, so they didn't also interfere.

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

I'll close this for now but reopen it if you find some related problem.

Closed 2025-09-01.

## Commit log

2022-04-13 Fixed hex standoff diameter
    [sbc_case_builder_library.scad]
2022-04-13 vu8m update, added screws and m1 hd mount removed spacer() as obsolete
    [sbc_case_builder_library.scad]
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2022-04-26 added view area to hk_vu8m() and fixed spacer_size[]
    [sbc_case_builder_library.scad]
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2022-05-14 rework of mask ioopen() addition of jetsonnano and rockpro64
    [sbc_case_builder.cfg, sbc_case_builder.scad, sbc_case_builder_library.scad]
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2022-05-19 finished mask(), changed tray top design, added sides style for tray design, added odroid-m1 and show2 cases, improved docs, updated sbc_model with fixed m1 heatsink and other m1 adjustments.
    [sbc_case_builder.cfg, sbc_case_builder.scad, sbc_case_builder_library.scad]
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2022-07-08 more code cleanup and fixes
    [sbc_case_builder.cfg, sbc_case_builder.scad]
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2022-07-28 added snap top and hexagon cases
    [sbc_case_builder.cfg, sbc_case_builder.scad]
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2022-07-31 fixed indent to adjust correctly based on wallthick, fixed standoff wall support placement, more customizer integration work, removed case data from sbc_case_builder.cfg, additional cases in json for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
    [sbc_case_builder.cfg, sbc_case_builder.scad]
2022-07-31 more json integration, fixed round, hex, fitted, snap cases, other minor fixes
    [sbc_case_builder.cfg, sbc_case_builder.scad, sbc_case_builder_library.scad]
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2022-08-05 round and hex case work and parameteric fixes
    [sbc_case_builder.cfg, sbc_case_builder.scad, sbc_case_builder_library.scad]
2022-08-07 added sbc_highlight to ui, changed to sbc_case_builder_accessories.cfg,updated json data, other case adjustments and fixes
    [sbc_case_builder.scad, sbc_case_builder_accessories.cfg, sbc_case_builder_library.scad]
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2022-08-07 fixed floorthick in round and hex cases, updated readme
    [sbc_case_builder.scad]
2022-08-08 adjusted floor thickness for snap and fitted cases
    [sbc_case_builder.scad]
2022-08-14 added sbc rpi3a+,rpi4b,rpizero,rock64,rockpi4c+,rockpi4b+ to customizer, added mask for usb2 and usb3 single_horizontal_a
    [sbc_case_builder.scad, sbc_case_builder_library.scad]
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2022-08-20 updated sbc_model_library and started update of customizer and case additions of multiple new sbc.
    [sbc_case_builder.scad, sbc_case_builder_accessories.cfg]
2022-08-20 updated sbc_model_framework for heatsink name correction.
2022-08-21 added momentary_7x3x3 mask, changed snap size for snap case, new case configurations.
    [sbc_case_builder.scad, sbc_case_builder_accessories.cfg, sbc_case_builder_library.scad]
2022-08-21 plumbed vim heatsink, adjusted vim case heights, added mask for combo usb3-usbc and other case adjustments.
    [sbc_case_builder.scad, sbc_case_builder_accessories.cfg, sbc_case_builder_library.scad]
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2022-08-27 add round case for low width/depth ratio sbc, fixed vent location, added rj-45_short mask
    [sbc_case_builder.scad, sbc_case_builder_accessories.cfg, sbc_case_builder_library.scad]
2022-08-28 modified hex case for low width/depth ratio sbc, other fixes and updates.
    [sbc_case_builder.scad, sbc_case_builder_accessories.cfg]
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2022-09-11 updated readme.md, added new variables to json entires, converted all case except HK to parametric accessories
    [sbc_case_builder.scad, sbc_case_builder_accessories.cfg]
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2022-09-13 Adds a new preset for Raspberry Pi 4b with GeeekPi PoE Hat
    [sbc_case_builder.scad, sbc_case_builder_accessories.cfg]
2022-09-14 Revert "new fan design that supports more fan sizes"
    This reverts commit d3b19d09ba4a15b11786b374dc07b407d6cda282.
    There are problems with this design. The code is causing warnings and using to much processing power.
    [sbc_case_builder_library.scad]
2022-09-14 changed default view to model for rpi4b_shell_geeekpi_poe_hat, turned off acc highlight and changed fan to 40mm.
    [sbc_case_builder_accessories.cfg]
2022-09-14 Fixes spacing of vents and rendering
    [sbc_case_builder_library.scad]
2022-09-14 rotated cross bars to 45deg. added a test file to generate a few sizes of masks
    [fan_mask.scad, sbc_case_builder_library.scad]
2022-09-14 Fixed comment in test
    [fan_mask.scad]
2022-09-15 Update fan logic to handle larger fan sizes better. Improved positioning and placement of fan parts.
    [fan_mask.scad, sbc_case_builder.scad, sbc_case_builder_accessories.cfg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]
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2022-09-15 Made all elements of test 3d to allow for surface and wireframe checking
    [fan_mask.scad]
2022-09-18 added multi-associative parametric positioning of accessories which use sbc xy postion and case z offset, sbc-case_z.
    [sbc_case_builder.scad, sbc_case_builder_accessories.cfg]
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2022-10-01 rewrite of indents, added usb2-micro,usbc-single_horizontal,audio-jack_3.5 and video-hdmi_a indents in all orientations, top and bottom, created new mask openings for bottom side components as needed.
    [sbc_case_builder.scad, sbc_case_builder_library.scad]
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2022-10-06 updated version in all files, updated readme.md and other small tweaks and corrections
    [sbc_case_builder.scad, sbc_case_builder_accessories.cfg, sbc_case_builder_library.scad]
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2022-10-14 added hdmi_a_vertical mask, usbc single_vertical mask, created base cases and updated readme.md and sbc_model_framework in support of rockpi5b.
    [sbc_case_builder.scad, sbc_case_builder_library.scad]
2022-10-22 added mask for microsdcard2, updated rockpi5b case data and sbc model framework
    [sbc_case_builder.scad, sbc_case_builder_accessories.cfg, sbc_case_builder_library.scad]
2022-10-25 fixed panel case left hook size, added access panel and standoff trim to all rockpi5b cases, readme.md changes
    [sbc_case_builder.scad, sbc_case_builder_accessories.cfg]
2022-11-01 updated sbc model framework with h3 and h3+, added 3mm to h2 and h3 case bottoms that use an access port, access port tab and opening adjustment, additional rockpi5b changes
    [get_customizer_values.scad, sbc_case_builder.scad, sbc_case_builder_accessories.cfg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]
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2022-11-03 added part selection for debug to facilitate individual part work and prints
    [sbc_case_builder.scad]
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2022-12-08 added part view in gui, added n2l and n2lq cases, updated sbc model framework
    [sbc_case_builder.scad, sbc_case_builder_accessories.cfg, sbc_case_builder_library.scad]
2022-12-10 updated readme.md, sbc_case_builder.gif, increased possible case size to 300mm, added m1 cases, added pine64 cases, other fixes
    [sbc_case_builder.scad, sbc_case_builder_accessories.cfg, sbc_case_builder_library.scad]
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2023-01-02 added hk_pwr_button model, keyhole accessory and h3_port_extender models for header and remote mount, updated h3_ultimate case.
    [sbc_case_builder.scad, sbc_case_builder_accessories.cfg, sbc_case_builder_library.scad]
2023-01-04 fixed standoff sidewall support placement, added fan masks for 60mm and code cleanup, finished h3_port_extender, created h3_ultimate2 for remote mount of port_extender.
    [sbc_case_builder.scad, sbc_case_builder_accessories.cfg, sbc_case_builder_library.scad]
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2023-01-09 added db9 model and mask, n2l sidewall support changed, work on n2l_gpio and h3_ultimate2 cases, updated readme.md.
    [db9_f.stl, db9_m.stl, sbc_case_builder.scad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]
2023-01-15 added vent_panel_hex(), minor fix in vent_hex()
    [sbc_case_builder_library.scad]
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2023-01-15 add bigger usbc hole for LicheeRV + Dock Type-C
    This Type-C port is on SoM and behind the edge of the Dock.
    [sbc_case_builder_library.scad]
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2023-01-15 fixed standoff auto openings for z height, fixed standoff sidewall supports distance on top face
    [sbc_case_builder.scad]
2023-01-15 fixed other standoff opening issue and set color in vent_panel_hex.
    [sbc_case_builder.scad, sbc_case_builder_library.scad]
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2023-01-21 fixed 60mm fan mask crossarms
    [sbc_case_builder_library.scad]
2023-01-22 fixed access_port and access_cover 180 rotation in portrait and landscape.
    [sbc_case_builder.scad, sbc_case_builder_library.scad]
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2023-02-20 added visionfive2 cases, split rockpi5b into rockpi5b-v1.3 and rockpi5b-v1.42 with addtions and modifications to support pre-release and released versions.
    [sbc_case_builder.scad, sbc_case_builder_accessories.cfg, sbc_case_builder_library.scad]
2023-02-21 add mask fix for rock5b v1.3
    [sbc_case_builder_library.scad]
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2023-03-04 updated sbc model framework, renamed radax rockpi to rock, rock 5b io adjustments, visionfive2 io overhang adjusted, readme.md and file comments updated.
    [sbc_case_builder.scad, sbc_case_builder_accessories.cfg, sbc_case_builder_library.scad]
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2023-03-05 updated sbc model framework for h2 and h3 pcb thickness increase, changed bottom_height calc to include pcb thickness.
    [sbc_case_builder.scad]
2023-03-06 reverted bottom height calc and added support ribs for h3_ultimate2 case
    [sbc_case_builder.scad, sbc_case_builder_accessories.cfg]
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2023-03-09 updated sbc model framework for visionfive2q, added visionfive2q cases, adjusted tray design side screw locations due to interference
    [sbc_case_builder.scad, sbc_case_builder_accessories.cfg]
2023-05-14 adjustments to rock5b-v1.42 and added rock5bq-v1.42 with updated sbc model framework, adjusted all rock5b case openings in sbc_case_builder_accessories.cfg, rock5b is now green-verified
    [sbc_case_builder.scad, sbc_case_builder_accessories.cfg, sbc_case_builder_library.scad]
2023-05-14 added rock5bq cases panel, stacked, tray, tray-sides, snap and fitted, updated sbc_model_framework
    [sbc_case_builder.scad, sbc_case_builder_accessories.cfg]
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2023-08-26 fixed snap case top, removed support pieces from non-shell cases for rock5b, fixed tray bottom mounting hole location for top and interference with standoff.
    [sbc_case_builder.scad, sbc_case_builder_accessories.cfg]
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2023-12-11 added 5mm and 8mm hex vent, adjusted m1s cases, updated sbc model framework, fixed snap top protrusion placement and other fixes.
    [header_2x5_90.stl, sbc_case_builder.scad, sbc_case_builder_accessories.cfg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]
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2024-01-30 removed no longer needed entries in accessory cfg.
    [sbc_case_builder.scad, sbc_case_builder_accessories.cfg]
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2024-02-01 fixed indent for cases with more code standardization and cleanup
    [case_bottom.scad, case_side.scad, case_top.scad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]
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2024-02-08 fixed front section cut, added 45 heatsink mask, fixed vu5 and vu7 holder, adjusted accessory entries for all stored cases due to bottom calc change, other fixes and adjustments
    [add.scad, sbc_case_builder.scad, sbc_case_builder_accessories.cfg]
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2024-02-10 updated accessory group names and changed order of accessories tab in ui
    [sbc_case_builder.scad]
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2024-02-17 refinement and fixes for folded cases with ui improvements
    [case_folded.scad, sbc_case_builder.scad]
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2024-02-19 standoff variable seperation for gui, initial work for top and bottom standoffs
    [case_bottom.scad, case_top.scad, sbc_case_builder.scad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]
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2024-02-23 sbc_case_builder_accessories.cfg corrections
    [sbc_case_builder_accessories.cfg]
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2024-03-21 fixed regression in standoff supports and more model cahnges to support auto mask generation
    [add.scad, case_bottom.scad, case_top.scad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]
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2024-04-07 removed case_style and added new case_design names as replacement
    [case_bottom.scad, case_folded.scad, case_side.scad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]
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2024-04-14 fixed tray side fastener placement when using extend standoffs, more standard mb case and adapter changes
    [case_adapter.scad, case_bottom.scad, case_side.scad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]
2024-04-17 documentation work and other cleanup and fixes
    [add.scad, case_bottom.scad, case_top.scad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]
2024-04-18 finished library documentation update, added fan and hd masks and other fixes
    [add.scad, case_top.scad, sbc_case_builder_accessories.cfg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]
2024-04-20 fixed z axis parametric problem related to calculated bottom standoff height, more case cleanup and other fixes and changes
    [add.scad, case_adapter.scad, case_bottom.scad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]
2024-04-22 fixed model view sections, fixed tray cases nut holder placement, changed fan mask direction and finalized standard form adapters and cases.
    [case_adapter.scad, case_bottom.scad, case_top.scad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]
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2024-04-24 finished named standoff size for extended standoffs, added mini-stx-thin adapter and io shield, updated readme.md and other fixes.
    [case_adapter.scad, case_bottom.scad, case_top.scad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]
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2024-04-30 Update README.md
    it’s -> its, trivial grammar correction
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2024-05-11 fixed fan_2 mask, created shared fan and heatsink mask code and readme.md updates and corrections
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2024-06-02 rework of extended case standoff placement based on standoff support size, cs-solar_energy_meter and avr_env_sensors case adjustments
    [case_bottom.scad, case_top.scad, sbc_case_builder_accessories.cfg]
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2024-06-09 changed how the inner corner fillet is derived, added a note in the README.md file about updating the submodule sbc model framework as well as other readme.md corrections.
    [case_bottom.scad, case_top.scad]
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2024-08-17 updated sbc model framework for nio12l corrections, created nio12l_shell test case to verify sbc
    [sbc_case_builder_accessories.cfg]
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2025-01-30 fixed standoff openings from interfering with case geometry
    [case_bottom.scad, case_top.scad, sbc_case_builder_accessories.cfg]
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2025-04-01 fixed top standoff z placement and height for fitted and snap cases
    [case_top.scad]
2025-04-01 fixed top standoff z placement and height for tray_side cases
    [case_top.scad]
2025-04-05 fixed top standoff opening problem due to typo
    [case_top.scad]
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2025-04-17 variable length spacer placement and hd reverse, 180 z rotation, implemented
    [case_side.scad, sbc_case_builder.scad]
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2025-04-21 fixed spacer and right side placment issue, updated readme.md, code cleanup and example case accessories
    [case_bottom.scad, case_side.scad, case_top.scad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]
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2025-04-24 panel_nas right side placement and related panel size fixed
    [case_bottom.scad, case_side.scad, case_top.scad]
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2025-04-26 minor gui format change, lib/vent.scad replaced
    [sbc_case_builder.scad, sbc_case_builder_library.scad]
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2025-05-06 more rack bay work, fixes and code cleanup
    [case_rack.scad, sbc_case_builder.scad]
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2025-05-16 added individual standoff control for rack case, fixed, open and removable bays
    [case_rack.scad, sbc_case_builder.scad]
2025-05-16 fixed manifold issue with lower panel clamps and other minor changes
    [case_rack.scad, sbc_case_builder.scad, sbc_case_builder_accessories.cfg]
2025-05-18 set interior walls to fixed width of 2mm
    [case_rack.scad, sbc_case_builder_accessories.cfg]
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2025-05-21 fixed rack bay external bottom heatsink standoff mounting support, raised case wall clamps, changed rack case to initial fixed depth of 100mm
    [case_rack.scad, sbc_case_builder.scad]
2025-05-22 fixed bottom heatsink standoff mounting for relavent sbc
    [case_bottom.scad, case_rack.scad, sbc_case_builder.scad]
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2025-05-26 grommet tolerance adjustment, fixed wrong part count and other minor changes
    [case_rack.scad, sbc_case_builder.scad, sbc_case_builder_accessories.cfg]
2025-05-28 adjusted removable bay clearances, added example rack case and other cleanup
    [case_rack.scad, sbc_case_builder.scad, sbc_case_builder_accessories.cfg]
2025-05-28 corrected interior wall height relative to floor thickness changes.
    [case_rack.scad]
2025-05-29 added sbccb_accessory_tool.scad for user access to the accessory library, fixed rack tab hole spacing, added library parts rack_rail and rack_stand for 1u-4u cases
    [case_rack.scad, sbc_case_builder.scad, sbccb_accessory_tool.scad]
2025-05-30 changed rack stand foot and arc thickness, readme.md corrections.
    [sbccb_accessory_tool.scad]
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2025-08-05 fixed syntax error
    [case_side.scad]
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2025-09-01 changed the position of the extended standoffs so as not to extend into the side wall beyond the bottom of the case which was causing problems for the panel case
    [case_bottom.scad, case_top.scad]
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2025-10-04 restored correct dxf for customfan.dxf
    [customfan.dxf]
2025-11-07 fixed top coverage vents for snap and fixed cases
    [case_top.scad]
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2026-05-05 changed 3.5 hd screw openings to #6, increased depth of standoff nut opening and increased height of h4_panel_nas-bottom_sbc case to increase clearance of internal mounted fan.
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
